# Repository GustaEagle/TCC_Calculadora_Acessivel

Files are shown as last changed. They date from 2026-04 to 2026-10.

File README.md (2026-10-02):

# Calculadora científica acessível (TCC)

Calculadora científica com foco em **acessibilidade** (feedback por voz e operação sem depender só da tela), executada em **Raspberry Pi 4B** com teclado físico, **UPS HAT**, painel **LCD 4,3" Waveshare** e suporte a **monitor HDMI**.

**Equipe:** Gustavo, João, Yuri  

**Repositório:** [github.com/GustaEagle/TCC_Calculadora_Acessivel](https://github.com/GustaEagle/TCC_Calculadora_Acessivel)

---

## Documentação principal

A pasta [`docs/`](docs/README.md) está organizada **por contexto** — comece pelo índice, ou vá direto ao documento:

| Documento | Descrição |
| --- | --- |
| [docs/README.md](docs/README.md) | **Índice da documentação** — o que existe e em que pasta |
| [docs/produto/PRD.md](docs/produto/PRD.md) | Requisitos de produto, escopo e arquitetura em alto nível (**normativo**) |
| [docs/guias/teclado-matriz.md](docs/guias/teclado-matriz.md) | **Teclado físico (matriz 6×7)**: as 38 teclas, funções com Ctrl/Shift, GPIO e diagnóstico |
| [docs/guias/comandos-teclado.md](docs/guias/comandos-teclado.md) | Comandos no teclado de PC: Ctrl/Shift, histórico, última resposta |
| [docs/guias/build-img-linux.md](docs/guias/build-img-linux.md) | Arranque em modo kiosk no Raspberry Pi 4B |
| [docs/desenvolvimento/Sprints.md](docs/desenvolvimento/Sprints.md) | Backlog por sprint e estado das tasks |
| [docs/desenvolvimento/GITHUB_WORKFLOW.md](docs/desenvolvimento/GITHUB_WORKFLOW.md) | Fluxo Git/GitHub da equipe |
| [docs/desenvolvimento/REPO_STRUCTURE.md](docs/desenvolvimento/REPO_STRUCTURE.md) | Mapa de pastas (software, hardware, system) |
| [docs/desenvolvimento/CONTEXT.md](docs/desenvolvimento/CONTEXT.md) | Memória curta entre sessões |
| [cronograma/cronograma.md](cronograma/cronograma.md) | Linha do tempo académica |

---

## Executar

```bash
python -m pip install -r software/requirements.txt
python software/app.py
```

`software/app.py` deteta a saída de vídeo ativa e abre **um** front (PRD §7): monitor HDMI externo quando reconhecido, senão o LCD 4,3", e **modo somente áudio** quando não há vídeo utilizável.

Para desenvolvimento e demonstrações a saída pode ser forçada:

```bash
python software/app.py --force-mode hdmi   # front do monitor externo
python software/app.py --force-mode lcd    # front do painel 4,3"
python software/app.py --force-mode audio  # somente voz, sem janela
```

**Histórico:** abre por **Ctrl + Ans** (no PC, a tecla `a` faz o papel do `Ans` da matriz 6x7). Não há botão de histórico — a entrada é sempre pelo teclado.

Lista completa dos atalhos: [docs/guias/teclado-matriz.md](docs/guias/teclado-matriz.md) (teclado do produto) e [docs/guias/comandos-teclado.md](docs/guias/comandos-teclado.md) (teclado de PC).

Testes: `make check` (ou `python -m unittest discover -s software/tests -t .`).

---

## Estrutura do repositório (resumo)

- **`software/`** — Motor de cálculo, UI (LCD / HDMI / partilhada), acessibilidade (áudio/TTS), plataforma (GPIO, integração), ponto de entrada `app.py`
- **`hardware/`** — PCB (KiCad), snapshots de export para marcos
- **`system/`** — Imagem SO, arranque e scripts (evolução conforme o PRD)
- **`docs/`** — Documentação por contexto: `produto/` (PRD), `guias/` (uso e montagem), `desenvolvimento/` (processo), `testes/`, mais referência de hardware (`raspberry-pi-4b/`, `waveshare/`, `keyboard-layout/`, `cad/`)
- **`cronograma/`** — Cronograma em Markdown, HTML interativo e export bruto
- **`prompts/`** — Prompts de sessão (bootstrap, fecho, agentes)

---

## Contribuir

1. Clonar o repositório e entrar na pasta do projeto  
2. Ler [docs/desenvolvimento/GITHUB_WORKFLOW.md](docs/desenvolvimento/GITHUB_WORKFLOW.md) e, no início de cada sessão, seguir [prompts/bootstrap.txt](prompts/bootstrap.txt)  
3. Trabalhar em branch a partir de `main` atualizada; mensagens de commit em **inglês** (ver [.github/COMMIT_GUIDELINES.md](.github/COMMIT_GUIDELINES.md))

---

## Estado do projeto

O código de aplicação ainda está em estruturação; o PRD e a documentação de apoio são a referência normativa. Consulte [docs/desenvolvimento/Sprints.md](docs/desenvolvimento/Sprints.md) para a sprint corrente e próximos entregáveis.

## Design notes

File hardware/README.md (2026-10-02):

# Hardware

## PCI (KiCad)

- **Canónico (recomendado):** [`pcb/`](pcb/) — um projeto KiCad por linha (ficheiros `.kicad_pro`, `.kicad_sch`, `.kicad_pcb`, bibliotecas locais em subpasta se necessário).
- **Legado / atual:** pasta **`Placa Kicad/`** na raiz do repositório — trabalho em curso; o histórico interno do KiCad (`.history/`) fica **fora do Git** (ver `.gitignore`).

Para marcos de revisão ou fabrico, use **`pcb/snapshots/<data>-<rótulo>/`** com Gerbers, PDF do esquemático, etc., em vez de versionar centenas de ficheiros de backup.

## Outros

- Layout de teclado (KLE): [`docs/keyboard-layout/`](../docs/keyboard-layout/).
- CAD mecânico: [`docs/cad/`](../docs/cad/).

Mapa geral: [docs/desenvolvimento/REPO_STRUCTURE.md](../docs/desenvolvimento/REPO_STRUCTURE.md).

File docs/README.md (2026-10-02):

# Documentação do projeto (`docs/`)

Índice da documentação do TCC — **calculadora científica acessível** em Raspberry Pi 4B.

A pasta está organizada **por contexto**: cada subpasta responde a uma pergunta diferente. Procure primeiro pela pergunta, depois pelo ficheiro.

| Pasta | Responde a | Conteúdo |
| ----- | --- | --- |
| [produto/](produto/) | *O que o produto deve fazer?* | PRD (referência normativa) e materiais/métodos do TCC |
| [guias/](guias/) | *Como se usa e como se faz rodar?* | Teclado da matriz, teclado de PC, imagem de arranque (kiosk) no Pi |
| [desenvolvimento/](desenvolvimento/) | *Como a equipe trabalha?* | Fluxo Git, mapa do repositório, backlog, memória de sessão, registo semanal |
| [testes/](testes/) | *O que já foi validado?* | Relatórios de testes e roteiro de usabilidade |
| [raspberry-pi-4b/](raspberry-pi-4b/) | *Como é a placa?* | Pinout do header J8 (40 pinos), datasheet, diagrama |
| [waveshare/](waveshare/) | *Como são os periféricos?* | LCD 4,3" HDMI (B) e UPS HAT |
| [keyboard-layout/](keyboard-layout/) | *Como é o teclado?* | Layout da matriz 6×7 no formato KLE |
| [cad/](cad/) | *Como as peças se encaixam?* | Modelos 3D (STEP/SLDPRT) do Pi, LCD e UPS HAT |

---

## Por onde começar

- **Chegou agora ao projeto:** [produto/PRD.md](produto/PRD.md) §1 (resumo) → [desenvolvimento/REPO_STRUCTURE.md](desenvolvimento/REPO_STRUCTURE.md) → [desenvolvimento/GITHUB_WORKFLOW.md](desenvolvimento/GITHUB_WORKFLOW.md).
- **Vai programar nesta sessão:** [desenvolvimento/CONTEXT.md](desenvolvimento/CONTEXT.md) (onde a última sessão parou) → [desenvolvimento/Sprints.md](desenvolvimento/Sprints.md) (task em aberto).
- **Vai mexer no hardware:** [raspberry-pi-4b/pinout.md](raspberry-pi-4b/pinout.md) §6 (matriz do teclado) → [keyboard-layout/README.md](keyboard-layout/README.md).
- **Vai montar o aparelho:** [guias/build-img-linux.md](guias/build-img-linux.md) → [waveshare/README.md](waveshare/README.md).

---

## Documentos mais consultados

| Documento | Para quê |
| --- | --- |
| [produto/PRD.md](produto/PRD.md) | Requisitos, escopo e arquitetura — **normativo**; desvios exigem atualizar o PRD |
| [guias/teclado-matriz.md](guias/teclado-matriz.md) | **Teclado físico do produto**: as 38 teclas da matriz 6×7 e o que cada uma faz |
| [guias/comandos-teclado.md](guias/comandos-teclado.md) | Os mesmos comandos no teclado de PC (desenvolvimento e testes) |
| [raspberry-pi-4b/pinout.md](raspberry-pi-4b/pinout.md) | Pinagem J8 e atribuição de GPIO da matriz (contrato com o código) |
| [desenvolvimento/GITHUB_WORKFLOW.md](desenvolvimento/GITHUB_WORKFLOW.md) | Branches, PRs e sequência de comandos da equipe |
| [desenvolvimento/sessoes/](desenvolvimento/sessoes/README.md) | O que cada pessoa fez, por semana do plano |

---

## Fora de `docs/`

| Caminho | Conteúdo |
| --- | --- |
| [`../README.md`](../README.md) | Visão geral do repositório e como executar |
| [`../cronograma/`](../cronograma/) | Linha do tempo académica (Markdown + HTML interativo) |
| [`../prompts/`](../prompts/) | Prompts de sessão (bootstrap, fecho, agentes) |
| [`../openspec/`](../openspec/) | Propostas de mudança e specs vigentes |
| [`../.github/COMMIT_GUIDELINES.md`](../.github/COMMIT_GUIDELINES.md) | Convenção de mensagens de commit |

---

## Convenções desta pasta

- **Um contexto por pasta.** Documento novo entra na pasta que responde à mesma pergunta; se não houver, discuta antes de criar pasta nova.
- **Links relativos**, sempre — o repositório é lido tanto no GitHub como offline no clone.
- **Ficheiros binários** (datasheet, CAD, imagens) ficam junto do documento que os explica, não numa pasta genérica de anexos.

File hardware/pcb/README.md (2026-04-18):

# PCB — KiCad

Coloque aqui o **projeto principal** (ex.: `tcc-calculadora/` com `.kicad_pro`).

## Snapshots (marcos)

Exportações conscientes (não substituem o Git do projeto):

```
snapshots/
  2026-05-01-pre-banca/
  2026-06-10-entrega/
```

Cada pasta pode conter: Gerber ZIP, PDF do esquemático, lista de materiais, notas de revisão.

## O que não versionar

A pasta **`.history/`** gerada pelo KiCad fica fora do Git (ver `.gitignore` na raiz).

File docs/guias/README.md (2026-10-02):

# Guias — operação e montagem

Como **usar** a calculadora e como **fazer o aparelho rodar**. Documentos de procedimento: seguem passo a passo, do começo ao fim.

| Documento | Para quem | Conteúdo |
| --- | --- | --- |
| [teclado-matriz.md](teclado-matriz.md) | Quem usa o produto | **Teclado físico (matriz 6×7)**: catálogo das 38 teclas com posição `C#L#`/`SW#`, layout da grade, funções com `Ctrl`/`Shift`, leitura por GPIO e diagnóstico |
| [comandos-teclado.md](comandos-teclado.md) | Quem desenvolve e testa | **Teclado de PC**: modificadores fixos, histórico, última resposta, graus/radianos, apagar telas, modo somente áudio |
| [build-img-linux.md](build-img-linux.md) | Quem monta o aparelho | Arranque em modo **kiosk** no Raspberry Pi 4B: Pi OS Lite, Alpine ou Buildroot; prós, contras e passos de cada opção |

## Relacionado

- Qual tecla está em qual GPIO: [../raspberry-pi-4b/pinout.md §6](../raspberry-pi-4b/pinout.md)
- Legendas e geometria do teclado: [../keyboard-layout/README.md](../keyboard-layout/README.md)
- `config.txt` e cablagem dos periféricos: [../waveshare/README.md](../waveshare/README.md)

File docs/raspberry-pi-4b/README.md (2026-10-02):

# Raspberry Pi 4 Model B — GPIO (header de 40 pinos)

**Especificação completa do pinout (tabelas, interfaces, notas elétricas):** [pinout.md](pinout.md)

**Diagrama visual:** ficheiro `Pinout.png` (referenciado em [pinout.md](pinout.md)).

**Datasheet oficial (PDF nesta pasta):** [RP-008341-DS-1-raspberry-pi-4-datasheet.pdf](RP-008341-DS-1-raspberry-pi-4-datasheet.pdf)

**Modelo 3D da placa:** [`../cad/raspberry-pi-4-model-b/`](../cad/raspberry-pi-4-model-b/)

**Pinout interativo:** [pinout.xyz](https://pinout.xyz/) · [Documentação Raspberry Pi](https://www.raspberrypi.com/documentation/)

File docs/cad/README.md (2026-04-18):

# Modelos CAD (3D)

Ficheiros **STEP/STP** e **SLDPRT** de referência mecânica para integração da caixa, PCB e periféricos.

| Pasta | Origem / conteúdo |
| ----- | --- |
| [waveshare-4.3inch-hdmi-lcd-b/](waveshare-4.3inch-hdmi-lcd-b/) | Waveshare — LCD **4,3" HDMI (B)** (desenho 3D; alinhar com [wiki](https://www.waveshare.com/wiki/4.3inch_HDMI_LCD_(B))) |
| [waveshare-ups-hat/](waveshare-ups-hat/) | Waveshare — **UPS HAT** (STEP; alinhar com [wiki](https://www.waveshare.com/wiki/UPS_HAT)) |
| [raspberry-pi-4-model-b/](raspberry-pi-4-model-b/) | **Raspberry Pi 4 Model B** — geometria da placa (STEP + SLDPRT conforme ficheiros presentes); pinagem em [../raspberry-pi-4b/README.md](../raspberry-pi-4b/README.md) |

**Nota:** nomes de ficheiros longos ou com espaços podem existir nos exports originais; renomeie no explorador apenas se atualizar referências em desenhos ou scripts.

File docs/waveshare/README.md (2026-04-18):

# Documentação Waveshare (contexto do projeto)

Este diretório contém **notas em português** derivadas das páginas oficiais da Waveshare, para consulta rápida no repositório do TCC. **A fonte normativa continua sendo a wiki e os ficheiros publicados pela Waveshare.**

## Links oficiais (canónicos)

- [UPS HAT — Waveshare Wiki](https://www.waveshare.com/wiki/UPS_HAT)
- [4.3inch HDMI LCD (B) — Waveshare Wiki](https://www.waveshare.com/wiki/4.3inch_HDMI_LCD_(B))
- [UPS HAT — página do produto](https://www.waveshare.com/UPS-HAT.htm)
- [4.3inch HDMI LCD (B) — página do produto](https://www.waveshare.com/4.3inch-hdmi-lcd-b.htm)

## Espelhos locais (Markdown)

| Ficheiro | Tema |
| --- | ---- |
| [UPS_HAT.md](UPS_HAT.md) | UPS HAT, I2C, carregamento, segurança, FAQ |
| [4.3inch_HDMI_LCD_B.md](4.3inch_HDMI_LCD_B.md) | LCD 800×480, `config.txt`, toque, FAQ |

## Modelos 3D no repositório

Ficheiros STEP/STP para alinhamento mecânico estão em [`../cad/`](../cad/README.md):

- [LCD 4,3" HDMI (B)](../cad/waveshare-4.3inch-hdmi-lcd-b/)
- [UPS HAT](../cad/waveshare-ups-hat/)
- [Raspberry Pi 4 Model B](../cad/raspberry-pi-4-model-b/) (placa de referência)

## Snapshot textual

- **Data da captura / redação local:** 2026-04-17  
- **Nota:** diagramas, fotos e PDFs da wiki **não** estão reproduzidos aqui; quando precisar de ilustrações ou datasheets, use os links da wiki e a secção “Resources / Document” de cada página.

## Aviso de uso

O conteúdo descritivo pertence à **Waveshare**. Os ficheiros `.md` desta pasta são um **auxiliar de trabalho**; em trabalhos académicos cite a documentação oficial e as datas de consulta conforme as normas da sua instituição.

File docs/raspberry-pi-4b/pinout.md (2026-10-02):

# Especificação do pinout — Raspberry Pi 4 Model B (header J8)

**Conector:** J8, **40 pinos** (2×20), passo **2,54 mm**.  
**Âmbito:** apenas pinagem e funções de **uso corrente** no header; não substitui o [datasheet oficial](RP-008341-DS-1-raspberry-pi-4-datasheet.pdf) para limites absolutos de corrente, derivações do SoC nem diagramas de bloco.

**Referências externas:** [pinout.xyz](https://pinout.xyz/) · [Documentação Raspberry Pi](https://www.raspberrypi.com/documentation/)

---

## 1. Convenções

| Termo | Significado |
| ----- | --- |
| **Pin** | Número **físico** no conector, **1…40** (estampado na silkbscreen da PCB como “1” junto ao canto da placa). |
| **BCM** | Numeração **Broadcom** do GPIO (uso típico em `gpiozero`, `RPi.GPIO`, `libgpiod`, overlays). |
| **Nome** | Rótulo habitual no **modo GPIO**; entre parêntesis, **função alternativa** mais citada para periféricos. |

**Orientação física:** com a placa vista de cima e os **conectores USB/Ethernet para baixo**, a coluna ímpar (**1, 3, …, 39**) fica em geral **perto da borda** da board; o **pino 1** é o canto que leva **3,3 V** (quadrado na PCB em muitos desenhos). Confirme sempre o **“1”** na sua unidade.

---

## 2. Requisitos elétricos (resumo)

- Todos os pinos marcados como **GPIO** operam a **3,3 V** lógicos. **Não** aplicar **5 V** a entradas GPIO — **não** são tolerantes a 5 V.
- Pinos **3V3** (1, 17): alimentação **3,3 V** limitada (capacidade total partilhada; ver datasheet).
- Pinos **5V** (2, 4): **5 V** (ligados ao rail de alimentação; origem depende do modo de alimentação da placa).
- **GND** (6, 9, 14, 20, 25, 30, 34, 39): referência comum.
- Corrente máxima **por GPIO** e **soma** de I/O: ver **datasheet** e notas de hardware; não assumir carga forte sem transistor/driver.

---

## 3. Tabela de pinos J8 (especificação)

| Pin | Sinal / função principal | BCM | Tipo |
| --- | --- | --- | ---- |
| 1 | 3V3 | — | Alimentação |
| 2 | 5V | — | Alimentação |
| 3 | GPIO2 — **I2C1 SDA** | 2 | GPIO / I2C |
| 4 | 5V | — | Alimentação |
| 5 | GPIO3 — **I2C1 SCL** | 3 | GPIO / I2C |
| 6 | GND | — | Terra |
| 7 | GPIO4 | 4 | GPIO |
| 8 | GPIO14 — **UART0 TXD** | 14 | GPIO / UART |
| 9 | GND | — | Terra |
| 10 | GPIO15 — **UART0 RXD** | 15 | GPIO / UART |
| 11 | GPIO17 — **SPI1 CE1** (ALT) | 17 | GPIO / SPI |
| 12 | GPIO18 — **SPI1 SCLK** (ALT) / **PWM0** / PCM_CLK | 18 | GPIO / SPI / PWM / PCM |
| 13 | GPIO27 | 27 | GPIO |
| 14 | GND | — | Terra |
| 15 | GPIO22 | 22 | GPIO |
| 16 | GPIO23 | 23 | GPIO |
| 17 | 3V3 | — | Alimentação |
| 18 | GPIO24 | 24 | GPIO |
| 19 | GPIO10 — **SPI0 MOSI** | 10 | GPIO / SPI |
| 20 | GND | — | Terra |
| 21 | GPIO9 — **SPI0 MISO** | 9 | GPIO / SPI |
| 22 | GPIO25 | 25 | GPIO |
| 23 | GPIO11 — **SPI0 SCLK** | 11 | GPIO / SPI |
| 24 | GPIO8 — **SPI0 CE0** | 8 | GPIO / SPI |
| 25 | GND | — | Terra |
| 26 | GPIO7 — **SPI0 CE1** | 7 | GPIO / SPI |
| 27 | GPIO0 — **ID_SD** (EEPROM HAT, I2C) | 0 | Reservado HAT / GPIO |
| 28 | GPIO1 — **ID_SC** (EEPROM HAT, I2C) | 1 | Reservado HAT / GPIO |
| 29 | GPIO5 | 5 | GPIO |
| 30 | GND | — | Terra |
| 31 | GPIO6 | 6 | GPIO |
| 32 | GPIO12 — **PWM0** | 12 | GPIO / PWM |
| 33 | GPIO13 — **PWM1** | 13 | GPIO / PWM |
| 34 | GND | — | Terra |
| 35 | GPIO19 — **SPI1 MISO** (ALT) / PCM_FS | 19 | GPIO / SPI / PCM |
| 36 | GPIO16 — **SPI1 CE0** (ALT) | 16 | GPIO / SPI |
| 37 | GPIO26 | 26 | GPIO |
| 38 | GPIO20 — **SPI1 MOSI** (ALT) / PCM_DIN | 20 | GPIO / SPI / PCM |
| 39 | GND | — | Terra |
| 40 | GPIO21 — PCM_DOUT (ALT) | 21 | GPIO / PCM |

**Nota:** **SPI1** só está disponível após ativar o controlador com **Device Tree overlay** (ex.: `spi1-1cs`, `spi1-2cs`, `spi1-3cs` em `config.txt`). Os pinos **MOSI / MISO / SCLK** acima são o mapeamento habitual no header; linhas **CE** (**chip enable** = **chip select**, **CS**) podem ser **reatribuídas** por parâmetros do overlay — ver README em `/boot/firmware/overlays/README` na imagem do SO.

---

## 3.1 SPI0 — sinais no J8 (bus principal)

Controlador **SPI0** (nós típicos `/dev/spidev0.0`, `/dev/spidev0.1`). **CE** = *chip enable* (sinônimo usual de **CS**, *chip select* / **SS**, *slave select*).

| Sinal | Função | BCM | Pin físico |
| ----- | --- | --- | --- |
| **MOSI** | Master Out, Slave In | 10 | 19 |
| **MISO** | Master In, Slave Out | 9 | 21 |
| **SCLK** | *Serial clock* (relógio SPI) | 11 | 23 |
| **CE0** | Chip select 0 | 8 | 24 |
| **CE1** | Chip select 1 | 7 | 26 |

O SPI0 expõe **duas** linhas de chip select (**CE0**, **CE1**). Não há **CE2** no SPI0 neste header.

---

## 3.2 SPI1 — sinais habituais no J8 (bus auxiliar)

Controlador **SPI1** (ex.: `/dev/spidev1.x` quando ativo). Mapeamento **frequente** no conector (compatível com referências como [pinout.xyz — SPI](https://pinout.xyz/pinout/spi)); **confirmar** na sua imagem se usou overlay com `cs*_pin` personalizado.

| Sinal | BCM | Pin físico |
| ----- | --- | --- |
| **MOSI** | 20 | 38 |
| **MISO** | 19 | 35 |
| **SCLK** | 18 | 12 |
| **CE0** | 16 | 36 |
| **CE1** | 17 | 11 |

**CE2 (terceiro chip select):** o overlay **`spi1-3cs`** permite três linhas **CS**; os **números de GPIO** para **CS0 / CS1 / CS2** são **configuráveis** (parâmetros `cs0_pin`, `cs1_pin`, `cs2_pin` no README oficial dos overlays). O valor **padrão** do firmware pode **colidir** com o uso “didático” CE0 = pin 36 se não ler o overlay — **sempre** validar com a documentação da sua versão (`dtoverlay -h spi1-3cs` ou arquivo `README` dos overlays). O **GPIO21** (pin **40**) **não** faz parte deste mapa SPI1 habitual; mantém-se principalmente como **PCM** / GPIO.

---

## 4. Interfaces no header (mapa rápido)

| Interface | Pinos físicos | BCM |
| --- | --- | --- |
| **I2C1** (uso geral, ex.: sensores, muitos HAT) | 3 (SDA), 5 (SCL) | 2, 3 |
| **UART0** | 8 (TX), 10 (RX) | 14, 15 |
| **SPI0** | 19 (**MOSI**), 21 (**MISO**), 23 (**SCLK**), 24 (**CE0**), 26 (**CE1**) | 10, 9, 11, 8, 7 |
| **SPI1** (com overlay) | 38 (**MOSI**), 35 (**MISO**), 12 (**SCLK**), 36 (**CE0**), 11 (**CE1**); **CE2** só com `spi1-3cs` e pinos conforme overlay | 20, 19, 18, 16, 17 |
| **EEPROM HAT** (I2C dedicado) | 27 (ID_SD), 28 (ID_SC) | 0, 1 |

No **Raspberry Pi 4** existem **UARTs adicionais** noutros pinos via configuração; não estão todas listadas nesta especificação resumida.

---

## 5. EEPROM de HAT (pinos 27 e 28)

Os pinos **27** e **28** estão ligados ao bus de **identificação de HAT** (EEPROM). Com **UPS HAT**, **Sense HAT** ou outras placas empilhadas que usem esse bus, **não** atribua estes pinos a **matriz de teclado** ou GPIO geral **sem** analisar **conflito elétrico e lógico** com a pilha de placas.

---

## 6. Matriz do teclado 6×7 — atribuição de GPIO

Teclado **Cherry MX hotswap** ligado **direto ao GPIO** por cabo flat, **sem** microcontrolador (PRD §6). O esquemático KiCad (`hardware/pcb/`) nomeia apenas as nets **`Row0…Row5`** e **`Col0…Col6`**; a correspondência com os pinos do J8 é a tabela abaixo.

**Fonte única de verdade em código:** [`software/hw_platform/keypad_pinout.py`](../../software/hw_platform/keypad_pinout.py) — o módulo valida na importação que cada GPIO existe no J8, que BCM e pino físico batem com a tabela do §3 e que nenhuma linha está repetida. [`software/tests/test_keypad_pinout.py`](../../software/tests/test_keypad_pinout.py) trava estes valores no CI.

> **Numeração:** tudo é **0-based** e o rótulo do chicote **é** a net do esquemático: **L0 = Row0**, **C0 = Col0**. Uma posição da grade escreve-se **`C#L#`** (coluna, linha), e os switches são **`SW0…SW37`** — os mesmos componentes são `SW1…SW38` na PCB do KiCad (**SWn aqui = SW(n+1) lá**).

**Polaridade confirmada no hardware** (o anodo de cada díodo 1N4148 fica do lado do switch/coluna, o catodo na net `RowN`):

| Condutor | Configuração |
| --- | --- |
| Linhas `L0…L5` | entrada com **pull-down** |
| Coluna ativa (uma de cada vez) | saída em **HIGH**, sem bias |
| Colunas inativas | entrada **sem bias** (alta impedância) |

Uma linha lida em **HIGH** com a coluna `Cn` ativa significa switch fechado em `CnLm`. **Nunca** duas colunas em saída ao mesmo tempo, **nunca** uma linha em saída. O scanner está em [`software/hw_platform/keypad_matrix.py`](../../software/hw_platform/keypad_matrix.py) (libgpiod v2, `gpiochip0`, offset = BCM).

### 6.1 Colunas

| Rótulo | Net (KiCad) | Cor do fio | BCM | Pin | Função alternativa do pino |
| --- | --- | --- | --- | --- | --- |
| **C0** | Col0 | Laranja | 26 | 37 | — |
| **C1** | Col1 | Roxo | 19 | 35 | SPI1 MISO (ALT) |
| **C2** | Col2 | Azul | 13 | 33 | PWM1 |
| **C3** | Col3 | Preto com final azul | 21 | 40 | PCM_DOUT (ALT) |
| **C4** | Col4 | Vermelho | 20 | 38 | SPI1 MOSI (ALT) |
| **C5** | Col5 | Marrom | 15 | 10 | **UART0 RXD** |
| **C6** | Col6 | Laranja | 14 | 8 | **UART0 TXD** |

### 6.2 Linhas

| Rótulo | Net (KiCad) | Cor do fio | BCM | Pin | Função alternativa do pino |
| --- | --- | --- | --- | --- | --- |
| **L0** | Row0 | Verde | 10 | 19 | **SPI0 MOSI** |
| **L1** | Row1 | Branco | 9 | 21 | **SPI0 MISO** |
| **L2** | Row2 | Roxo | 11 | 23 | **SPI0 SCLK** |
| **L3** | Row3 | Roxo | 17 | 11 | SPI1 CE1 (ALT, só com overlay) |
| **L4** | Row4 | Amarelo | 27 | 13 | — |
| **L5** | Row5 | Verde | 22 | 15 | — |

13 condutores no total (6 linhas + 7 colunas), sem repetição de GPIO nem de pino físico. **Atenção:** GPIO27 é o **pino físico 13**; o pino físico 27 (EEPROM de HAT, §5) **não** é usado pela matriz.

> Uma versão anterior desta tabela tinha **Row0↔Row2** e **Row3↔Row5** trocadas — os mesmos seis GPIOs em outra ordem. A ordem acima foi conferida eletricamente, tecla a tecla.

### 6.3 Conflitos de função — o que tem de ficar desligado no boot

Seis das treze linhas ocupam pinos com periférico associado. Elas só se comportam como **GPIO comum** enquanto o firmware **não** ativar esse periférico — ver [`system/rpi-os/alpine/overlay/boot/usercfg.txt`](../../system/rpi-os/alpine/overlay/boot/usercfg.txt):

| Periférico | Pinos da matriz | Condição para a matriz funcionar |
| --- | --- | --- |
| **UART0** | C6 (GPIO14), C5 (GPIO15) | `enable_uart=0` e **sem** `console=serial0` no `cmdline.txt` (a imagem usa `console=tty1`). **Custo:** sem consola série para depurar o boot; resta o HDMI/tty1. |
| **SPI0** | L2 (GPIO11), L1 (GPIO9), L0 (GPIO10) | **não** ligar `dtparam=spi=on`. O LCD Waveshare é HDMI, não SPI — nada no produto quer o SPI0. |
| **SPI1** (ALT) | L3 (GPIO17 = CE1) | **não** carregar overlay `spi1-*cs`. Sem overlay, SPI1 nem existe — conflito apenas teórico. |

**I2C1 (GPIO2/GPIO3, pinos 3 e 5) fica FORA da matriz de propósito.** É o barramento onde o UPS HAT lê tensão/corrente/capacidade no endereço **0x42** ([UPS_HAT.md](../waveshare/UPS_HAT.md), RF-06/RF-14): mantendo-o livre, a leitura de bateria usa o I2C **de hardware** (`dtparam=i2c_arm=on`, `/dev/i2c-1`), sem overlay `i2c-gpio` nem código fora do padrão da Waveshare.

> **Porque L3…L5 saíram de GPIO4/3/2 (pinos 7/5/3).** Além do UPS, **GPIO2 e GPIO3 são os únicos pinos do header com pull-ups de 1,8 kΩ para 3,3 V soldados na placa do Pi** — existem sempre, mesmo com o I2C desligado, e nenhuma configuração os remove. Numa linha de matriz lida com pull-down, esses pull-ups a manteriam sempre em HIGH (tecla sempre premida); como I2C, são exatamente os pull-ups que o barramento quer. Os pinos **11/13/15** (GPIO17/27/22) não têm periférico ativo nenhum e continuam a ser três **ímpares contíguos**, ou seja, o flat mantém a geometria.

> **O UPS HAT não é empilhável neste projeto.** O header dele é de 40 pinos **sem passagem** e o header do Pi está ocupado pelo flat do teclado, portanto a HAT liga-se **por fios** (5 V, GND, SDA no pino 3, SCL no pino 5) — ou alimenta o Pi pela saída USB 5 V dela. Confirmar no esquemático do lote antes de soldar.

Os pinos **27/28** (GPIO0/GPIO1, EEPROM de HAT — §5) **não** são usados pela matriz e não entram na lista de livres.

### 6.4 GPIO livres depois desta atribuição

**BCM:** 4, 5, 6, 7, 8, 12, 16, 18, 23, 24, 25 · **Pinos:** 7, 29, 31, 26, 24, 32, 36, 12, 16, 18, 22.

GPIO2/GPIO3 (pinos 3/5) **não** entram aqui: estão reservados ao I2C1 do UPS HAT (§6.3).

### 6.5 Mapa de switches e bring-up

Grade vista de frente, colunas `C0…C6` da esquerda para a direita. Cada célula: switch e keycap. As quatro posições **—** não têm switch (`C2L1`, `C2L2`, `C2L3`, `C4L4`); sinal nelas é defeito e o scanner só o regista no log.

| | C0 | C1 | C2 | C3 | C4 | C5 | C6 |
| - | -- | -- | -- | -- | -- | -- | -- |
| **L0** | SW0 `Pol` | SW1 `x!` | SW2 `Pi` | SW3 `(` | SW4 `)` | SW5 `%` | SW6 `e` |
| **L1** | SW7 `sen` | SW8 `cos` | — | SW9 `7` | SW10 `8` | SW11 `9` | SW12 `/` |
| **L2** | SW13 `tan` | SW14 `log` | — | SW15 `4` | SW16 `5` | SW17 `6` | SW18 `*` |
| **L3** | SW19 `x^-1` | SW20 `^` | — | SW21 `1` | SW22 `2` | SW23 `3` | SW24 `-` |
| **L4** | SW25 `?` | SW26 `nCr` | SW27 `√` | SW28 `0` | — | SW29 `,` | SW30 `+` |
| **L5** | SW31 `Ctrl` | SW32 `exp` | SW33 `Shift` | SW34 `Ans` | SW35 `=` | SW36 `AC` | SW37 `Del` |

A tecla **`?`** existe na placa mas **não tem função** no software: ela é lida e anuncia «Tecla sem função».

**Tempos (valores de bancada, PRD §12):** estabilização de **~1 ms** depois de ativar cada coluna, **debounce de ~20 ms**. Ambos são configuráveis no scanner e na ferramenta de bring-up; rever com o chicote definitivo.

**Checklist de bancada** (manual, no Pi; não corre no CI):

- `python3 software/tools/keypad_bringup.py` — premir as 38 teclas: cada uma aparece com `SW#`, `C#L#`, keycap e GPIOs, a grade final mostra 38 de 38, e nenhuma posição vazia aparece.
- Depois do `Ctrl+C`: `pinctrl get 9-11,13-15,17,19-22,26-27` mostra as 13 GPIOs em entrada sem pull (`ip pn`).
- O mesmo `pinctrl get` depois de `kill -TERM` no app (`python3 -m software.app`).
- Com o app aberto, `Ctrl` e depois `sen` na matriz insere o arco seno — nos dois fronts (LCD e monitor).

---

## 7. Diagrama visual

A imagem `Pinout.png` serve como **referência gráfica**. Pode corresponder a outro modelo no silkscreen (ex.: Pi 3 B+); a **numeração 1…40** e as **funções da tabela acima** aplicam-se ao **Pi 4 Model B** neste projeto.

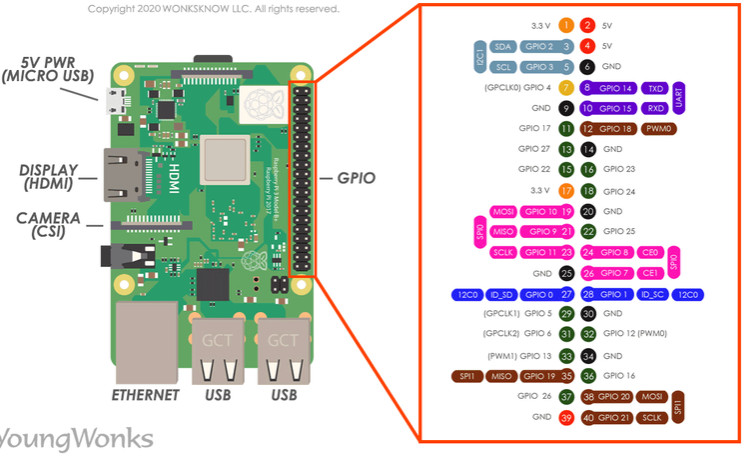
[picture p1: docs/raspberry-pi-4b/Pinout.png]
Pinout GPIO — header de 40 pinos (referência visual)


---

## 8. Artefactos relacionados no repositório

- [README.md](README.md) — índice da pasta (datasheet, CAD, links).
- Modelo 3D: [`../cad/raspberry-pi-4-model-b/`](../cad/raspberry-pi-4-model-b/)

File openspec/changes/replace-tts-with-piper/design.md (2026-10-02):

## Context

A motivação está no `proposal.md` (seção Why) e os requisitos em `specs/speech-engine/spec.md`.

O que já existe e condiciona a abordagem:

- **`software/accessibility/speech.py`** é o **único** lugar que conhece o motor de voz. Ele expõe `SpeechService.say()`, `interrupt_and_say()` e `stop()`, e por baixo tem: uma `queue.Queue`, uma thread worker, o contador `_Generation` (descarta anúncios obsoletos após uma interrupção) e um **processo por frase** (`_SpeakProcess`, subclasse de `multiprocessing.Process`). O processo importa `pyttsx3`, inicializa o motor, escolhe a voz pt-BR, sintetiza para um WAV temporário e toca com `os.system("aplay ...")`. O `_SpeakProcess` lidera um grupo de processo próprio para que `terminate()` mate também o `aplay` neto, e usa um diretório de scratch por frase, apagado no `join()`.
- **Os 5 consumidores** (`app.py`, `ui/lcd/app.py`, `ui/hdmi/app.py`, `audio_only.py`, `ui/shared/video_watch.py`) só chamam `say`/`interrupt_and_say`/`stop`. A mudança fica contida no `speech.py`.
- **`process_factory` / `SpeakProcess` (Protocol)** já são o ponto de injeção: o construtor aceita uma fábrica de "processo de fala" duck-typed (`start`/`join`/`is_alive`/`terminate`). Os testes já usam um `_FakeProcess`. É por aqui que o motor residente entra sem reescrever a fila.
- **Saída de áudio (decidida):** `overlay/etc/asound.conf` fixa a placa `Headphones` (jack 3,5 mm do Pi) **pelo nome**, e o PCM padrão do ALSA na imagem é `plug → hw`, **sem `dmix`**. Só um processo abre a placa por vez. O `espeak-ng` já gera 22.050 Hz / mono / 16-bit, e a voz `cadu` também é 22.050 Hz — o formato que chega ao jack não muda.
- **Imagem:** Alpine 3.24.1 aarch64, Python **3.14.7**, `espeak-ng` 1.52, `alsa-utils` (aplay), só ALSA (sem PulseAudio). O `community` v3.24 tem `onnxruntime`/`py3-onnxruntime` **1.24.4** já compilados para musl e Python 3.14 (confirmado no APKINDEX em cache no rootfs de build). O multiprocessing no 3.14 usa **forkserver** por padrão (o dev/CI usam **fork**).
- **`piper-tts` (upstream `OHF-Voice/piper1-gpl`, versão 1.8.0, GPL-3.0):**
  - depende de `onnxruntime>=1,<2` e `pathvalidate`;
  - **embute o próprio `espeak-ng`** (ligado estaticamente via CMake, tag fixa) e os `espeak-ng-data`, usados só como **fonemizador** — a voz é o modelo neural;
  - o **sdist do PyPI é incompleto** (falta `CMakeLists.txt`, `espeakbridge.c`, `espeak-ng-data`): `pip install piper-tts` compila a partir do **git**, não do sdist. Precisa de `build-base`, `cmake`, `git`, `python3-dev`, `scikit-build` — ~200 MB que **não** vão para a imagem final;
  - a extensão C é `abi3` (compatível entre versões de Python), mas o upstream só declara suporte até 3.13 — o 3.14 precisa ser validado;
  - a API Python é `PiperVoice.load(model, config)` + `voice.synthesize(text) -> Iterable[AudioChunk]`, com `AudioChunk.audio_int16_bytes` (PCM S16LE mono). `SessionOptions` permite limitar as threads do ONNX.
- **Armadilha:** o apk chamado **`piper`** no Alpine **não** é o Piper TTS — é um configurador de mouse (libratbag). Nunca `apk add piper`.
- **Voz `pt_BR-cadu-medium`** (repositório `rhasspy/piper-voices`): 22.050 Hz, 1 locutor, `phoneme_type: espeak`, `espeak.voice: pt-br`, dataset CC0, `.onnx` de 63 MB + `.onnx.json`. `inference`: `noise_scale 0.667`, `length_scale 1.0`, `noise_w 0.8`.
- **Frases fixas são um conjunto pequeno e conhecido:** `SPOKEN_TOKEN_NAMES` (38), os 10 dígitos, os 10 textos de `ERROR_MESSAGES` §13, os avisos 012/013 e os anúncios fixos ("Calculadora pronta", "Controle ativo"...). Dá para pré-sintetizar tudo em poucos MB.

## Goals / Non-Goals

**Goals:**
- Voz neural pt-BR (`cadu`) com o **mesmo contrato** de fila e interrupção de hoje (RF-08), sem tocar nos 5 consumidores.
- Motor **residente**: o modelo carrega uma vez, não por frase.
- Arranque não bloqueado pela carga do modelo (RNF-06): "Calculadora pronta" nunca espera o ONNX.
- Degradação segura: sem Piper, cai para `espeak-ng` e a entrada não trava (WRN-011).
- CI e `make check` continuam **sem** Piper nem áudio, por import tardio e motor injetável.

**Non-Goals:**
- Streaming intra-frase (o Piper devolve a frase inteira).
- Interromper uma síntese **em andamento** (a API do Piper não permite abortar; ver D5).
- Remover o `espeak-ng` do sistema (fonemizador + fallback).
- GPU/CUDA; treino de voz; download de voz em execução.

## Decisions

### D1 — O motor residente entra pela `process_factory`, a fila fica intacta

O `SpeechService` continua idêntico: `say`/`interrupt_and_say`/`stop`, `queue.Queue`, worker, `_Generation`, `process_lock`. O que muda é o objeto que a `process_factory` devolve por frase. Hoje é um `_SpeakProcess` (processo). Passa a ser um **handle de reprodução** leve que:

- fala com o **motor residente** já carregado (não recarrega nada);
- expõe a mesma interface duck-typed `SpeakProcess` (`start`, `join`, `is_alive`, `terminate`), para o worker não perceber diferença;
- em `start()`: sintetiza (ou pega do cache, D4) e dispara **um** `aplay`;
- em `terminate()`: mata o `aplay` (grupo de processo, como hoje);
- em `join()`: espera o `aplay` terminar.

*Alternativa rejeitada:* reescrever a fila para chamar o motor direto na thread worker. Perderia o ponto de teste (`process_factory`/`_FakeProcess`) e misturaria síntese com reprodução, dificultando o `terminate()`.

### D2 — Motor residente: `PiperEngine` carregado em segundo plano

Novo componente em `speech.py` (ou submódulo `accessibility/piper_engine.py`), com **import tardio** do `piper`/`onnxruntime`:

- `PiperEngine.load_async()` carrega `PiperVoice.load(model, config)` numa **thread**, para o construtor do `SpeechService` retornar de imediato (RNF-06).
- Enquanto o modelo não terminou de carregar, ou se a carga falhar, o serviço usa o **fallback** (D6). Assim "Calculadora pronta" sai na hora, pelo espeak-ng, mesmo que o ONNX ainda esteja subindo.
- `synthesize(text) -> bytes` concatena os `AudioChunk.audio_int16_bytes` das frases e devolve PCM S16LE mono.
- As threads do `onnxruntime` são limitadas (`SessionOptions.inter_op_num_threads`/`intra_op_num_threads`, ex.: 2–3), para não competir com o Tk e a varredura da matriz. O valor fica configurável.
- Um único `PiperEngine` por `SpeechService` (o serviço já é reusado entre fronts na troca do RF-09).

### D3 — Reprodução: `aplay` lendo raw pela entrada padrão

O player é `aplay -q -t raw -f S16_LE -c 1 -r <sample_rate> -`, recebendo o PCM pela stdin. Motivos:

- o `sample_rate` vem do `.onnx.json` da voz (cadu = 22.050), não é fixado no código;
- dispensa WAV temporário, `os.system` e processo neto — sai a fila de `fala-*`/`tmp*.wav` em `/tmp`;
- o `aplay` usa o PCM padrão do ALSA, que o `asound.conf` já manda para o jack;
- a interrupção continua sendo **matar o `aplay`**. O handle lidera o próprio grupo de processo (como o `_SpeakProcess` de hoje) e `terminate()` faz `killpg(SIGTERM)`.

Como o ALSA não tem `dmix` (Context), **só um `aplay` toca por vez**. A fila já serializa isso (uma frase por vez), e o fallback nunca toca junto com o Piper.

### D4 — Cache de frases fixas, pré-aquecido após o arranque

Um `dict[str, bytes]` (texto → PCM) guarda as frases de conjunto fechado:

- `SPOKEN_TOKEN_NAMES` (38), os dígitos `0..9`, os 10 `ERROR_MESSAGES` §13 com o prefixo falado ("Erro 001. ..."), os avisos 012/013 e os anúncios fixos.
- O pré-aquecimento roda numa thread de baixa prioridade **depois** que o modelo carrega, sem bloquear nada. Até estar pronto, um miss simplesmente sintetiza na hora.
- `say(text)`: se `text` está no cache, o handle só reproduz os bytes (latência ~ a de abrir o `aplay`); senão, sintetiza.
- Resultados e histórico (números, expressões) **não** entram no cache — são dinâmicos.
- **Mitigação de resultados longos:** "Resultado" e "Última resposta" podem sair do cache **imediatamente**, enquanto o número é sintetizado como frase seguinte. É a diferença entre o Piper e o espeak-ng em latência percebida.

*Estimativa:* todas as frases fixas somam poucos MB de PCM em RAM; aceitável no Pi 4 (Context da imagem).

### D5 — Interrupção: descarte por geração + morte do `aplay`; síntese em curso não é abortada

O `interrupt_and_say()` de hoje faz três coisas que **continuam**: `bump()` da geração, limpa a fila e `terminate()` no processo atual. Com o Piper:

- se a frase interrompida já está **tocando**, o `aplay` é morto na hora (igual a hoje);
- se está sendo **sintetizada**, a API do Piper **não** oferece abortar no meio. No pior caso a síntese da frase termina (~100–500 ms para frases curtas) e é **descartada** pelo `_Generation` antes de tocar — o worker checa `is_stale(generation)` e nem abre o `aplay`. O usuário não ouve a frase obsoleta; só espera, no pior caso, o fim de uma síntese curta.
- A síntese pode ser feita **frase a frase** (o Piper já separa por sentença) e a geração é checada **entre frases**, encurtando a janela para textos longos.

*Trade-off aceito:* não há corte no meio de uma síntese. Para as frases fixas (cache) a síntese nem acontece no caminho crítico, então o caso comum (tecla → `=`) já é instantâneo.

### D6 — Fallback `espeak-ng` e WRN-011

Se `import piper`/`onnxruntime` falhar, se o modelo não carregar, ou enquanto ele ainda está carregando, o serviço usa `espeak-ng`:

- reprodução pelo **mesmo** player raw: `espeak-ng -v pt-br --stdout <texto> | aplay ...`, ou `espeak-ng ... -w tmp.wav`;
- registra `WRN-011` (motor TTS degradado) uma vez, sem repetir a cada frase;
- **nunca bloqueia a entrada** (RF-08): a fila segue funcionando.

Isso mantém o dispositivo utilizável se o build do Piper falhar num campo, e cobre a janela de carga do modelo no arranque.

### D7 — Empacotamento na imagem: wheel pré-compilado + voz com sha256

O `build-alpine-img.sh` **não** compila o Piper dentro do fluxo normal (seria lento sob qemu e traria ~200 MB de toolchain). Em vez disso:

- um **wheel `musl/aarch64`** do `piper-tts` é produzido **uma vez** (num container `alpine:3.24` arm64 ou no próprio Pi, a partir da tag fixa do git) e versionado fora da imagem / baixado no build;
- o build instala o wheel com `pip install --no-deps <wheel>` **sobre** o `py3-onnxruntime` do apk (o `onnxruntime` não vem do pip);
- `pathvalidate` (Python puro) vem do pip;
- a voz `cadu` (`.onnx` + `.onnx.json`) é baixada com **sha256 fixo** e validada, no mesmo padrão do minirootfs do script;
- os modelos de outras línguas embutidos no `piper-tts` (`hebrew/`, `tashkeel/` — ~25 MB) são **apagados** do site-packages, já que só pt-BR é usado;
- o **smoke** deixa de ser `pyttsx3.init()` e passa a ser uma **síntese real** no chroot (Piper → PCM), sem placa de som — teste mais forte que o atual e possível sob qemu;
- o symlink `libespeak.so.1` (defensivo, só para o pyttsx3) é removido.

*Alternativa rejeitada:* compilar o Piper no `build-alpine-img.sh`. Torna o build lento e frágil e mistura toolchain com a imagem final.

### D8 — `py3-onnxruntime` pelo apk, não pelo pip

O `onnxruntime` do PyPI **não** tem wheel `musl`, e compilá-lo é enorme. O Alpine `community` v3.24 já traz `py3-onnxruntime` 1.24.4 para Python 3.14/musl. Vai para `system/rpi-os/alpine/packages`, e o wheel do Piper é instalado com `--no-deps` para não puxar o onnxruntime do pip.

*Efeito:* ~120 MB instalados (closure completo: numpy, openblas, protobuf, abseil, icu, sympy — medido no APKINDEX). É o maior item de tamanho da mudança e cabe na imagem de 2 GB.

### D9 — Multiprocessing vs. thread no motor residente

Hoje cada frase é um **processo** (fork/forkserver). Com o motor residente, o modelo vive no **processo principal**; o que é lançado por frase é o **`aplay`** (subprocesso), não um processo Python que recarrega o motor. Assim:

- não se paga fork + import + load por frase;
- no Pi (Python 3.14/forkserver) não há o risco de o filho não herdar o handler de SIGTERM (memória do projeto `pi-python-forkserver`), porque o `aplay` é um subprocesso comum, não um `multiprocessing.Process`;
- a síntese roda na thread worker do serviço; as threads do ONNX são limitadas (D2).

## Risks / Trade-offs

- **[Build do Piper sob qemu é lento e o sdist é incompleto]** → O wheel é compilado **fora** do fluxo do build (D7), uma vez, e reaproveitado. O `CMakeLists` baixa e compila o espeak-ng estático (tag fixa); sob qemu isso leva dezenas de minutos. Mitigação: compilar num container arm64 nativo ou no Pi, e fixar o artefato.
- **[Python 3.14 não é testado pelo upstream]** → a extensão é `abi3`, mas é preciso **validar** a síntese no chroot 3.14 (o smoke de D7 faz exatamente isso) antes de fechar a imagem.
- **[Latência maior em resultados longos]** → o Piper entrega a frase inteira de uma vez; um número grande pode levar centenas de ms a mais que o espeak-ng. Mitigação: "Resultado"/"Última resposta" saem do cache na hora (D4), e a síntese do número segue como frase seguinte.
- **[ALSA sem `dmix`: reprodução sequencial]** → nunca tocar Piper e fallback ao mesmo tempo, senão `Device or resource busy`. A fila já serializa; o código garante um único player ativo.
- **[Memória e CPU do modelo neural no Pi 4]** → +150–300 MB de RAM residente e picos de CPU na síntese. Threads do ONNX limitadas (D2); a síntese fora do caminho crítico via cache. Medir no hardware (tarefa 6).
- **[Interrupção não corta síntese em curso]** → aceito (D5); janela curta por frase, e o caso comum usa cache.
- **[Licença GPL-3.0 do `piper-tts`]** → o `espeak-ng` já é GPL; a `cadu` é CC0. Registrar a proveniência e a licença na imagem. Não afeta o código próprio do projeto (uso, não linkagem estática distribuída no mesmo binário do app).
- **[Tamanho]** → rootfs ~487 MB → ~0,7 GB. Cabe nos 2 GB; monitorar se a imagem crescer com o kernel/firmware.

## Migration Plan

Não há dados nem estado persistido. A migração é de **motor**; o texto falado e a API não mudam.

1. Provar o Piper/`cadu` **no Pi** (protótipo, tarefa 2): medir carga, latência (tecla, resultado longo), CPU, RAM e temperatura, com as frases reais.
2. Trocar o `speech.py` para o motor residente + cache + fallback, mantendo a API e os testes de fila/interrupção.
3. Empacotar (wheel, `py3-onnxruntime`, voz com sha256, smoke de síntese).
4. Validar no hardware; só então decidir se o apk `espeak-ng` do sistema é removido (fica fora desta mudança).

**Rollback:** reverter o commit devolve o `pyttsx3`/`espeak-ng`. Como o `espeak-ng` **permanece** na imagem (fonemizador + fallback), mesmo um Piper quebrado em campo mantém a voz por fallback.

## Open Questions

- **Threads do ONNX no Pi 4:** 2 ou 3? Depende da medição (tarefa 2) versus a carga do Tk + varredura da matriz.
- **Pré-aquecer todo o cache no arranque** ou só sob demanda na primeira ocorrência? A favor de aquecer: latência previsível desde a primeira tecla. Contra: alguns segundos de CPU no arranque (RNF-06). Decidir com a medição.
- **`length_scale`/velocidade:** manter o padrão da `cadu` (1.0) ou acelerar um pouco, como o `rate 175` do pyttsx3 hoje? É ajuste de UX de voz, a validar com a equipe.
- **Remover o apk `espeak-ng` do sistema depois:** vale os 19 MB, ou o fallback justifica mantê-lo? Fica para depois da validação no hardware.
- **Origem do wheel `musl/aarch64`:** compilar no CI (container arm64), no Pi, ou fixar um artefato no repositório de release? Decisão de infraestrutura de build.

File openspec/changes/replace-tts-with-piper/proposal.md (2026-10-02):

## Why

Hoje a voz da calculadora sai do `espeak-ng` através do `pyttsx3` (`software/accessibility/speech.py`, `requirements.txt`, `system/rpi-os/alpine/packages`). O `espeak-ng` é robusto e cabe no arranque rápido (RNF-06), mas soa **formântico e metálico**, o que atrapalha a inteligibilidade exigida pelo PRD §8 — justamente o requisito que serve o usuário com cegueira total, para quem a voz é o canal principal (RF-04, RF-07). O objetivo é uma voz **neural, natural e em português do Brasil**, mantendo o funcionamento **offline** e a política de interrupção (RF-08) que já existe.

O motor escolhido é o **Piper** (`OHF-Voice/piper1-gpl`, pacote `piper-tts`), TTS neural offline sobre `onnxruntime`, com Raspberry Pi 4 (aarch64) como alvo de primeira classe. A voz será a **`pt_BR-cadu-medium`** (22.050 Hz, 1 locutor, dataset CC0), que a equipe já escolheu e possui.

O trabalho não é uma troca de biblioteca linha a linha. Duas coisas o condicionam e estão na base desta proposta:

- **O modelo de processos do `speech.py` precisa mudar.** Hoje cada frase abre um **processo novo** (`_SpeakProcess`), que importa o motor e reinicializa a voz. Repetir isso com o Piper recarregaria um modelo de 63 MB a cada tecla — inviável. O motor tem de ficar **residente**.
- **O Piper não tem pacote pronto para o Alpine (musl).** Não há apk nem wheel `musl`. O `piper-tts` precisa ser **compilado** a partir do git (o `setup.py` usa CMake e embute o `espeak-ng` estaticamente); o `onnxruntime`, porém, **já existe** no repositório `community` do Alpine v3.24 aarch64 (`py3-onnxruntime` 1.24.4), que é a parte mais difícil e vem pronta.

Sem esta mudança, a calculadora continua com uma voz que cumpre a norma "pt-BR offline" na letra, mas não a intenção de **clareza** do PRD.

## What Changes

- **Motor de voz residente no `software/accessibility/speech.py`.** O `SpeechService` — a fila, o contador de geração (`_Generation`) e a política de interrupção — é **preservado**. O que muda por baixo:
  - Um **motor Piper residente** carrega o modelo `cadu` **uma vez** (em segundo plano, para não travar o arranque) e sintetiza frase a frase.
  - A reprodução passa a ser `aplay` lendo áudio **raw** (`-t raw -f S16_LE -c1 -r <sample_rate do .onnx.json>`) pela entrada padrão, sem WAV temporário e sem `os.system`. O grupo de processo e o `terminate()` que silenciam o `aplay` continuam válidos.
  - **Cache de frases fixas**: os nomes de tecla (`SPOKEN_TOKEN_NAMES`, 38), os dígitos, os textos de erro/aviso §13 e os anúncios fixos são sintetizados uma vez após o arranque e reproduzidos do cache. É o que mantém a latência por tecla igual ou melhor que hoje.
  - **Fallback**: se o Piper não estiver disponível (import falha, modelo ausente), o serviço cai para o `espeak-ng` (`--stdout | aplay`), registra `WRN-011` e **não bloqueia a entrada** (RF-08).
- **Voz `pt_BR-cadu-medium` embutida na imagem.** O modelo `.onnx` + `.onnx.json` é baixado no build com **sha256 fixo** (padrão do `build-alpine-img.sh`) e validado; nada é baixado no aparelho (offline).
- **`piper-tts` na imagem por wheel pré-compilado.** Um wheel `musl/aarch64` é compilado a partir da tag do `piper-tts` e instalado com `--no-deps` sobre o `py3-onnxruntime` do apk. O `onnxruntime` **não** vem do pip.
- **`py3-onnxruntime` adicionado a `system/rpi-os/alpine/packages`** (repositório `community`, já disponível).
- **`pyttsx3` removido** de `requirements.txt`: nenhum caminho passa a usá-lo.
- **Ambiente de desenvolvimento (Docker/CI)** atualizado: em glibc, `pip install piper-tts` funciona direto; um script baixa a voz `cadu`; o `Dockerfile` e o `Makefile` deixam de depender do `pyttsx3`.
- **Documentação e decisões registradas** atualizadas: PRD §12, `software/README.md`, `openspec/config.yaml` e a spec `rpi-boot-image` deixam de dizer "TTS via espeak-ng + pyttsx3" e passam a "Piper (voz cadu), com espeak-ng como fonemizador embutido e fallback".

## Capabilities

### New Capabilities
- `speech-engine`: o motor de síntese de voz offline em pt-BR. Cobre a escolha do Piper e da voz `cadu`, o motor **residente** (modelo carregado uma vez, sem processo por frase), a reprodução por `aplay` em áudio raw pela placa padrão do ALSA, o cache de frases fixas, o carregamento não-bloqueante no arranque (RNF-06), o fallback para `espeak-ng` (WRN-011) e a preservação do contrato de fila e interrupção do `SpeechService` (RF-08).

### Modified Capabilities
- `rpi-boot-image`: o requisito "TTS offline em português embutido" hoje exige `espeak-ng` **e** `pyttsx3`. Passa a exigir o **Piper** com a voz `cadu` embutida e offline, o `onnxruntime` do Alpine, e o `espeak-ng` mantido como fonemizador e fallback (o `pyttsx3` deixa de ser exigido).

## Impact

- **Código alterado:**
  - `software/accessibility/speech.py`: motor residente + player raw + cache + fallback. A API pública (`say`, `interrupt_and_say`, `stop`) e a fila/geração **não mudam**.
  - `software/requirements.txt`: remove `pyttsx3`; acrescenta `piper-tts` (com marcador de ambiente para não quebrar o build musl, que usa o wheel pré-compilado).
  - `system/rpi-os/alpine/packages`: acrescenta `py3-onnxruntime`.
  - `system/rpi-os/alpine/build-alpine-img.sh`: instala o wheel do Piper, baixa e valida a voz `cadu` (sha256), remove os modelos de outras línguas embutidos no `piper-tts` (hebraico/árabe, ~25 MB), troca o smoke de `pyttsx3.init()` por uma **síntese real** no chroot, e remove o symlink `libespeak.so.1` (que só servia ao pyttsx3).
  - `Dockerfile`, `docker-compose*.yml`, `Makefile`: dependências de desenvolvimento.
  - `docs/produto/PRD.md` §12, `software/README.md`, `docs/guias/build-img-linux.md`, `openspec/config.yaml`: texto das decisões.
- **Sem alteração:** os 5 consumidores do serviço de voz — `software/app.py`, `software/ui/lcd/app.py`, `software/ui/hdmi/app.py`, `software/audio_only.py`, `software/ui/shared/video_watch.py` — que só chamam `say` / `interrupt_and_say` / `stop`. Também ficam como estão `software/core/`, os textos falados (`ui/shared/keypad.py`, `history.py`, `error_messages.py`) e a saída de áudio no jack (`overlay/etc/asound.conf`, `usercfg.txt`).
- **Testes:** os testes de fila e interrupção do `SpeechService` continuam (com o motor injetável, sem Piper real). Os testes específicos do driver `pyttsx3`/espeak (`_EspeakLikeEngine`, `SpeakWaitsForPlaybackTest`) são reescritos para o motor residente. Entra um teste de cache e de fallback. A suíte segue rodando **sem Piper** no CI (Python 3.11), por import tardio.
- **Dependências:** `+py3-onnxruntime` e closure (~120 MB instalados, medidos no APKINDEX v3.24 aarch64), `+piper-tts` (wheel, ~35–60 MB) e a voz `cadu` (63 MB). O rootfs sai de ~487 MB para ~0,7 GB, dentro da imagem de 2 GB.
- **Requisitos cobertos:** PRD §8 (inteligibilidade), RNF-02 (TTS offline), RF-08 (a interrupção e a não-blocagem da entrada são preservadas), RNF-06 (carga do modelo não bloqueia o arranque) e RNF-04 (a mudança fica isolada em `accessibility/`).
- **Riscos principais:** build do Piper sob qemu (lento, sdist incompleto, Python 3.14 não testado upstream); latência maior em resultados longos; ALSA sem `dmix` (reprodução sequencial); memória e CPU do modelo neural no Pi 4. Detalhados no `design.md`.

## Não-objetivos

- **Não** mudar o **texto** falado, os nomes de tecla, nem o catálogo de mensagens §13. A migração é do **motor**, não do conteúdo.
- **Não** alterar a saída de áudio no jack de 3,5 mm (`asound.conf`/`usercfg.txt`), que é decisão de produto já registrada.
- **Não** remover o `espeak-ng` da imagem nesta mudança: ele é o fonemizador do Piper (embutido no wheel) e o **fallback**. A remoção do apk `espeak-ng` do sistema, se desejada, fica para uma mudança posterior, depois da validação no hardware.
- **Não** treinar nem afinar voz; usa a `cadu` publicada como está.
- **Não** usar GPU/CUDA (o Pi 4 não tem); o `onnxruntime` roda em CPU.
- **Não** ligar o Piper ao download de vozes em execução (`piper.download_voices`): o aparelho é offline; a voz vai embutida na imagem.
- **Não** adotar streaming intra-frase: o Piper entrega o áudio de uma frase inteira de uma vez. A mitigação (tocar "Resultado" do cache enquanto o número é sintetizado) é de implementação, não de escopo.

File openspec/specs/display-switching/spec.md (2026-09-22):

# display-switching Specification

## Purpose
TBD - created by archiving change add-hdmi-ui. Update Purpose after archive.

## Requirements

### Requirement: Prioridade do monitor HDMI sobre o LCD
Quando as saídas HDMI do LCD e do monitor externo estiverem ambas reconhecidas, o sistema SHALL selecionar o front-end do monitor (`DisplayMode.HDMI`) como saída principal, e o LCD SHALL NOT exibir a mesma interface principal.

#### Scenario: LCD e monitor reconhecidos simultaneamente
- **WHEN** `DisplaySelector.current_mode()` é consultado e tanto a saída HDMI do LCD quanto a do monitor externo estão reconhecidas
- **THEN** o resultado é `DisplayMode.HDMI`

### Requirement: Uso do LCD quando o monitor não está presente
Quando apenas a saída HDMI do LCD estiver reconhecida (monitor externo ausente), o sistema SHALL selecionar o front-end do LCD (`DisplayMode.LCD`).

#### Scenario: Somente LCD reconhecido
- **WHEN** `DisplaySelector.current_mode()` é consultado, a saída HDMI do LCD está reconhecida e a do monitor externo não está
- **THEN** o resultado é `DisplayMode.LCD`

### Requirement: Modo somente áudio sem vídeo utilizável
Quando nenhuma saída de vídeo estiver utilizável (nem LCD nem monitor reconhecidos, incluindo o caso do interruptor físico do LCD cortando sua saída HDMI), o sistema SHALL selecionar `DisplayMode.AUDIO_ONLY`, mantendo entrada por teclado e feedback por voz funcionando (RF-04).

#### Scenario: Nenhuma saída de vídeo reconhecida
- **WHEN** `DisplaySelector.current_mode()` é consultado e nem a saída HDMI do LCD nem a do monitor externo estão reconhecidas
- **THEN** o resultado é `DisplayMode.AUDIO_ONLY`

#### Scenario: Interruptor físico do LCD desligado sem monitor presente
- **WHEN** o interruptor físico do LCD corta sua saída HDMI (painel em standby) e o monitor externo não está reconhecido
- **THEN** `DisplaySelector.current_mode()` retorna `DisplayMode.AUDIO_ONLY`, tratando a saída do LCD como indisponível

### Requirement: Ponto de entrada único desperta o front correto
O sistema SHALL fornecer um único ponto de entrada que consulta `DisplaySelector.current_mode()` na inicialização e instancia exclusivamente o front correspondente (`ui_hdmi` para `HDMI`, `ui_lcd` para `LCD`, ou um laço somente-áudio para `AUDIO_ONLY`), sem instanciar mais de um front visual ao mesmo tempo.

#### Scenario: Inicialização com monitor presente
- **WHEN** o ponto de entrada é executado e `DisplaySelector.current_mode()` retorna `DisplayMode.HDMI`
- **THEN** apenas o front-end `ui_hdmi` é instanciado; `ui_lcd` não é iniciado

#### Scenario: Inicialização sem vídeo utilizável
- **WHEN** o ponto de entrada é executado e `DisplaySelector.current_mode()` retorna `DisplayMode.AUDIO_ONLY`
- **THEN** nenhum front visual (`ui_lcd` ou `ui_hdmi`) é instanciado, e o sistema opera aceitando teclado e respondendo por `SpeechService`

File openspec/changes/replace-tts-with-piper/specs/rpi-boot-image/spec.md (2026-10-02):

## MODIFIED Requirements

### Requirement: TTS offline em português embutido

A imagem SHALL incluir o motor **Piper** (`piper-tts` sobre `onnxruntime`) com a voz **`pt_BR-cadu-medium`** embutida, e a cadeia de áudio necessária para sintetizar voz em **português do Brasil** de forma **offline** (sem qualquer dependência de rede/nuvem), preservando o feedback por voz de entradas e resultados. O `onnxruntime` SHALL vir do repositório do Alpine (`py3-onnxruntime`), e o modelo de voz SHALL ser embutido na imagem com integridade verificada (sha256). O `espeak-ng` SHALL permanecer na imagem como fonemizador do Piper e como motor de **fallback**; o `pyttsx3` SHALL NOT ser exigido.

#### Scenario: Anúncio por voz sem rede

- **WHEN** o dispositivo está sem conexão de rede e o usuário realiza uma operação na calculadora
- **THEN** a entrada e/ou o resultado são anunciados por voz em português do Brasil (voz `cadu`), usando o motor local Piper, sem acessar a rede

#### Scenario: Motor de voz inicializa corretamente

- **WHEN** a aplicação inicia o serviço de TTS na imagem
- **THEN** o modelo `cadu` é carregado a partir da imagem e a síntese ocorre sem falha; se o Piper estiver indisponível, o sistema degrada para `espeak-ng` sem travar a entrada

#### Scenario: Voz embutida e verificada, sem download em execução

- **WHEN** a imagem é construída
- **THEN** o modelo `pt_BR-cadu-medium` (`.onnx` + `.onnx.json`) é incluído com sha256 verificado, e nenhum componente de voz é baixado quando o dispositivo está em uso

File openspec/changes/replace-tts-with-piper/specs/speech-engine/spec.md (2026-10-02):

## Purpose

Definir o **motor de síntese de voz** da calculadora: um TTS neural offline em português do Brasil (Piper, voz `cadu`), residente em memória, que reproduz pela placa de áudio padrão do sistema e preserva a política de fila e interrupção já exigida pelo RF-08. Serve à inteligibilidade do PRD §8 e ao funcionamento offline do RNF-02, sem alterar o texto falado nem os consumidores do serviço de voz.

## ADDED Requirements

### Requirement: Motor de voz neural offline em pt-BR (Piper + cadu)

O sistema SHALL sintetizar a voz com o motor **Piper** (`piper-tts`, sobre `onnxruntime`), usando a voz **`pt_BR-cadu-medium`**, de forma **offline** — sem qualquer dependência de rede ou nuvem. O modelo de voz (`.onnx`) e a sua configuração (`.onnx.json`) SHALL estar embutidos na imagem e SHALL NOT ser baixados em tempo de execução.

#### Scenario: Síntese sem rede
- **WHEN** o dispositivo está sem conexão de rede e uma entrada ou resultado precisa ser anunciado
- **THEN** o texto é falado em português do Brasil pela voz `cadu`, usando o modelo local, sem acessar a rede

#### Scenario: Voz cadu carregada da imagem
- **WHEN** o serviço de voz inicializa
- **THEN** o modelo `pt_BR-cadu-medium` é carregado de um caminho local da imagem, com o `sample_rate` lido do seu `.onnx.json`

### Requirement: Motor residente, sem recarregar por frase

O modelo de voz SHALL ser carregado **uma única vez** por execução e permanecer residente em memória. O sistema SHALL NOT recarregar o modelo a cada anúncio. Cada anúncio SHALL reutilizar o motor já carregado.

#### Scenario: Modelo carregado uma vez
- **WHEN** vários anúncios são feitos em sequência
- **THEN** o modelo de voz é carregado apenas na primeira vez e reutilizado nos anúncios seguintes, sem nova carga do arquivo `.onnx`

### Requirement: Carga não-bloqueante no arranque

A carga do modelo de voz SHALL NOT bloquear o arranque da aplicação (RNF-06). Enquanto o modelo ainda não está pronto, o sistema SHALL permitir que anúncios ocorram por um caminho degradado, sem travar a interface nem a entrada.

#### Scenario: Anúncio de prontidão não espera o modelo
- **WHEN** a aplicação inicia e anuncia que está pronta, antes de o modelo neural terminar de carregar
- **THEN** o anúncio é reproduzido de imediato pelo caminho de fallback, sem aguardar a carga do modelo

### Requirement: Reprodução pela placa de áudio padrão do sistema

O áudio sintetizado SHALL ser reproduzido pela placa de áudio **padrão do ALSA** (que a imagem fixa no jack de 3,5 mm), por meio do reprodutor do sistema (`aplay`), sem depender de servidor de som (PulseAudio). Em nenhum momento SHALL haver mais de um reprodutor de áudio ativo ao mesmo tempo.

#### Scenario: Som sai pela saída padrão
- **WHEN** um anúncio é reproduzido
- **THEN** o áudio sai pela placa padrão definida na configuração do ALSA da imagem, sem PulseAudio

#### Scenario: Reprodução serializada
- **WHEN** um anúncio está tocando e outro é solicitado
- **THEN** os anúncios são reproduzidos um de cada vez, sem dois reprodutores concorrentes sobre a mesma placa

### Requirement: Preservação da fila e da interrupção (RF-08)

O motor SHALL preservar o contrato de fila e interrupção existente: um anúncio de maior prioridade (resultado ou erro P1) SHALL interromper de forma consistente o anúncio em curso ou enfileirado de menor prioridade, e apenas o anúncio mais recente MUST ser reproduzido. A entrada por teclado SHALL NOT ficar bloqueada enquanto a voz fala.

#### Scenario: Resultado interrompe anúncio de tecla
- **WHEN** uma tecla está sendo anunciada e o usuário aciona a avaliação
- **THEN** o anúncio da tecla em reprodução é cortado e o resultado é falado, sem sobrepor os dois

#### Scenario: Anúncio obsoleto descartado sem tocar
- **WHEN** uma interrupção chega enquanto uma frase de menor prioridade ainda está sendo sintetizada e ainda não começou a tocar
- **THEN** essa frase é descartada por obsolescência e não chega a ser reproduzida

#### Scenario: Entrada não bloqueia durante a fala
- **WHEN** o usuário pressiona teclas enquanto um anúncio está em curso
- **THEN** as teclas são aceitas e processadas sem esperar o fim da fala

### Requirement: Cache de frases de conjunto fechado

O sistema SHALL manter em memória o áudio pré-sintetizado das frases de **conjunto fechado** — nomes de tecla, dígitos, mensagens de erro e aviso do PRD §13 e anúncios fixos — e reproduzi-las a partir desse cache, para manter a latência por tecla baixa. Resultados e expressões dinâmicas SHALL ser sintetizados sob demanda.

#### Scenario: Nome de tecla reproduzido do cache
- **WHEN** uma tecla cujo nome falado pertence ao conjunto fixo é anunciada, após o cache estar aquecido
- **THEN** o áudio correspondente é reproduzido do cache, sem nova síntese

#### Scenario: Resultado dinâmico é sintetizado
- **WHEN** um resultado numérico precisa ser anunciado
- **THEN** ele é sintetizado sob demanda pelo motor, pois não pertence ao conjunto fixo

### Requirement: Fallback quando o motor neural está indisponível

Se o motor Piper não puder ser carregado (dependência ausente, modelo ausente ou falha de carga) ou enquanto ainda está carregando, o sistema SHALL degradar para o motor `espeak-ng`, SHALL registrar o aviso `WRN-011` (motor TTS degradado) e SHALL NOT bloquear a entrada do usuário.

#### Scenario: Piper ausente cai para espeak-ng
- **WHEN** o motor Piper não está disponível no arranque
- **THEN** os anúncios são reproduzidos por `espeak-ng`, o sistema registra `WRN-011` e a calculadora continua utilizável

#### Scenario: Falha de voz não trava a entrada
- **WHEN** ocorre uma falha pontual na síntese ou na reprodução
- **THEN** a entrada por teclado continua sendo aceita e o erro é registrado, sem interromper o uso (RF-08)

### Requirement: Contrato de integração inalterado para os consumidores

A interface pública do serviço de voz (`say`, `interrupt_and_say`, `stop`) SHALL permanecer inalterada, de modo que os fronts (LCD, HDMI e somente áudio) e o observador de vídeo continuem funcionando **sem alteração**. A troca de motor SHALL NOT exigir mudanças fora do módulo de acessibilidade.

#### Scenario: Fronts não mudam
- **WHEN** um front chama `say` ou `interrupt_and_say` como faz hoje
- **THEN** o anúncio ocorre com o novo motor, sem que o código do front precise ser alterado

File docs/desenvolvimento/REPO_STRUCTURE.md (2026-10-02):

# Estrutura do repositório (mapa PRD → pastas)

Este documento liga o [PRD.md](../produto/PRD.md) à organização de código e hardware. **Não é obrigatório** criar tudo antes do primeiro commit: pastas vazias podem ganhar ficheiros à medida que as tasks avançam; a árvore abaixo é a **direção** acordada.

---

## Resumo visual

| Área no PRD | Pasta(s) |
| --- | --- |
| Motor de cálculo (§8), Python | [`software/core/`](../../software/core/) |
| Ponto de entrada (escolhe a saída ativa, §7) | [`software/app.py`](../../software/app.py) |
| Front LCD 7.x (§7) | [`software/ui/lcd/`](../../software/ui/lcd/) |
| Front monitor HDMI (§7) | [`software/ui/hdmi/`](../../software/ui/hdmi/) |
| Peças de UI partilhadas pelos dois fronts | [`software/ui/shared/`](../../software/ui/shared/) |
| Modo somente áudio (RF-04) | [`software/audio_only.py`](../../software/audio_only.py) |
| Áudio / TTS / acessibilidade (§8) | [`software/accessibility/`](../../software/accessibility/) |
| GPIO, UPS, detecção HDMI, integração | [`software/hw_platform/`](../../software/hw_platform/) |
| Testes (cruzados ou por módulo) | [`software/tests/`](../../software/tests/) + `tests/` dentro de cada pacote quando fizer sentido |
| PCI KiCad, fenolite (§6) | [`hardware/pcb/`](../../hardware/pcb/) — ver nota sobre `Placa Kicad/` |
| Imagem SO, `config.txt`, arranque, scripts (§12) | [`system/`](../../system/) |
| Datasheets, CAD, pinout, Waveshare | [`docs/`](../README.md) (já existente) |
| Cronograma interativo | [`cronograma/`](../../cronograma/) |

---

## KiCad e várias versões

- O projeto atual pode continuar em **`Placa Kicad/`** até migrarem sem problemas de caminhos; a pasta alvo versionada é **`hardware/pcb/<nome-do-projeto>/`** (um `.kicad_pro` por linha de produto).
- O KiCad gera **`/.history/`** com muitos ficheiros: está **ignorado no Git** (ver [`.gitignore`](../../.gitignore)). Para marcos (revisão, envio à gráfica), use **`hardware/pcb/snapshots/`** com subpastas datadas (ex.: `2026-06-10-gerbers-review/`) contendo export explícito (Gerber, PDF esquemático, STEP se necessário).

---

## Criar pastas “já” vs ir commitando

- **Convém** ter o **esqueleto** `software/*` e `system/` desde cedo: todos sabem onde pôr ficheiros e o PRD cita modularidade (RNF-04).
- **Não é obrigatório** preencher cada pasta na primeira sprint: ficheiros aparecem com as features.
- Quem trabalha com IA: no início da sessão, o [`prompts/bootstrap.txt`](../../prompts/bootstrap.txt) já pede leitura do PRD; **não é necessário um agente novo** só para pastas — opcionalmente mencionar *“seguir docs/desenvolvimento/REPO_STRUCTURE.md”* no chat se estiverem a refatorar árvore.

---

## Migração sugerida (quando quiserem)

1. Copiar ou mover o `.kicad_pro` + `.kicad_sch` + `.kicad_pcb` (+ bibliotecas locais) para `hardware/pcb/tcc-calculadora/` (nome ajustável).
2. Manter `Placa Kicad/` só como arquivo ou apagar após validar que o Git e o KiCad abrem o novo caminho.
3. Registar no [`CONTEXT.md`](CONTEXT.md) a pasta canónica da PCB.

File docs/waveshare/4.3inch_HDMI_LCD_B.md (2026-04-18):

# 4,3" HDMI LCD (B) — Waveshare — notas para o repositório

**Fonte:** [Waveshare Wiki — 4.3inch HDMI LCD (B)](https://www.waveshare.com/wiki/4.3inch_HDMI_LCD_(B))  
**Página do produto:** [4.3inch-hdmi-lcd-b.htm](https://www.waveshare.com/4.3inch-hdmi-lcd-b.htm)  
**Snapshot local:** 2026-04-17

LCD IPS **4,3"**, **800 × 480**, HDMI, painel táctil capacitivo (5 pontos), vidro temperado (dureza até **6H** segundo a wiki). Serve com Raspberry Pi (Raspberry Pi OS, Ubuntu, Kali, Retropie) ou como monitor em PC Windows.

---

## Características (resumo)

- Resolução de hardware **800 × 480**.
- Táctil capacitiva **5 pontos**; em PC Windows suporta Windows 11/10/8.1/8/7 com cinco pontos.
- Menu **OSD** multilingue (brilho, contraste, gestão de energia, etc.).
- **Jack áudio 3,5 mm** e conector de altifalante; áudio via HDMI.

---

## Uso com PC Windows

1. Ligar a interface **TOUCH** do LCD a uma porta **USB** do PC; aguardar reconhecimento do táctil.
2. Ligar o **HDMI** do LCD ao HDMI do PC; após ~**10 s** a imagem deve estabilizar.
3. Áudio: auscultadores no conector **HP** ou altifalante no conector indicado (ex.: **8 Ω, 5 W** na FAQ de áudio).

**Nota:** com vários monitores no Windows, o táctil deste LCD pode controlar apenas o cursor no **monitor principal**; a wiki recomenda definir este LCD como principal.

---

## Uso com Raspberry Pi

Sistemas referidos: Raspberry Pi OS, Ubuntu, Kali, Retropie. Imagem recomendada: versão atual do [site oficial Raspberry Pi](https://www.raspberrypi.com/software/operating-systems/).

1. Descarregar e extrair o `.img`.
2. Formatar o cartão (a wiki sugere [SDFormatter](https://files.waveshare.com/upload/d/d7/Panasonic_SDFormatter.zip) no Windows).
3. Gravar a imagem (a wiki sugere [Win32DiskImager](https://files.waveshare.com/upload/7/76/Win32DiskImager.zip)).
4. No cartão, editar **`config.txt`** na raiz (ou `/boot/firmware/config.txt` em layouts mais recentes) e **acrescentar no fim**:

```ini
hdmi_force_hotplug=1
hdmi_group=2
hdmi_mode=87
hdmi_cvt 800 480 60 6 0 0 0
```

5. Inserir o cartão no Pi.
6. Ligar **TOUCH** do LCD a **USB** do Pi.
7. Ligar **HDMI** do LCD ao **HDMI** do Pi; alimentar e aguardar alguns segundos.

---

## Teclas físicas (OSD)

| Tecla | Função |
| ----- | --- |
| **Power** | Liga / desliga o display (backlight); útil para reduzir consumo em repouso prolongado. |
| **Menu** | Abre o menu OSD; dentro do menu funciona como **OK**. |
| **Up / Left** | Navegação. |
| **Down / Right** | Navegação. |
| **Exit** | Sair; dentro do menu funciona como **voltar**. |

---

## Recursos (oficiais)

- [Desenho 3D (ZIP)](https://files.waveshare.com/wiki/4.3inch_HDMI_LCD_B/4.3inch_HDMI_LCD_3D_Drawing.zip)
- Cópia local extraída (STEP): pasta [`../cad/waveshare-4.3inch-hdmi-lcd-b/`](../cad/waveshare-4.3inch-hdmi-lcd-b/) (ver [`../cad/README.md`](../cad/README.md))

A wiki lista também software adicional na secção **Software** — confirmar na [página atual](https://www.waveshare.com/wiki/4.3inch_HDMI_LCD_(B)).

---

## FAQ (resumo útil)

### Quadrados coloridos no autoteste da GPU no arranque

Acrescentar a `/boot/config.txt` (ou equivalente em Bookworm):

```ini
disable_splash=1
```

### Substituir o logótipo de arranque (Raspberry Pi)

Substituir a imagem em:

`/usr/share/plymouth/themes/pix/splash.png`

### Toque longo = clique direito (Raspberry Pi)

A wiki descreve instalação de **evdev-rce** para sistemas **32 bits** Bullseye (exemplo datado **2022-04-04**); **64 bits** pode não ser suportado por defeito. Passos resumidos:

```bash
wget https://files.waveshare.com/upload/1/18/Evdev-right-click-emulation.zip
unzip Evdev-right-click-emulation.zip
cd evdev-right-click-emulation
sudo apt install build-essential libevdev2 libevdev-dev -y
sudo cp 'out/evdev-rce' '/usr/local/bin/'
sudo chmod +x '/usr/local/bin/evdev-rce'
```

Execução inicial:

```bash
sudo evdev-rce
```

Configuração de utilizador `pi`, módulo `uinput`, regra udev e arranque automático — ver secção completa na wiki (ficheiro `99-uinput.rules`, `autostart/right_click.desktop`, variáveis `LONG_CLICK_INTERVAL` e `LONG_CLICK_FUZZ`).

### O ecrã apaga sozinho?

Depende do sistema e da hibernação; no Raspberry Pi OS, por defeito pode haver escurecimento após ~**10 minutos** sem interação.

### Táctil em PC Linux “genérico”

Experimentar driver **hid-multitouch** no kernel.

### Temperatura de trabalho

**0 °C — 70 °C** (valores da wiki).

### Tensão e corrente típicas

~**5 V**, corrente ~**0,5 A** (indicativos da wiki).

### Brilho por PWM (hardware)

A wiki indica **remoção de uma resistência** indicada no desenho, ligação do pad **PWM** do ecrã ao **PWM** do Pi e **GND** comum, e comandos `gpio` de exemplo para PWM no GPIO 18 (consultar **figura na wiki** — não reproduzida aqui).

### Interface áudio 4 pinos (PH2.0)

Disposição de pinos: **+ − − +**. Altifalante sugerido: [8 Ω 5 W (Waveshare)](https://www.waveshare.com/product/displays/accessories/speakers/8ohm-5w-speaker.htm).

---

## Anti‑pirataria / imitações

A wiki inclui avisos sobre produtos falsificados e diferenças de qualidade. Em caso de dúvida sobre autenticidade, contactar o suporte Waveshare.

---

## Suporte

Formulário e horário na [página oficial](https://www.waveshare.com/wiki/4.3inch_HDMI_LCD_(B)) (GMT+8).

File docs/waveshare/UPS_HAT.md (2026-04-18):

# UPS HAT (Waveshare) — notas para o repositório

**Fonte:** [Waveshare Wiki — UPS HAT](https://www.waveshare.com/wiki/UPS_HAT)  
**Página do produto:** [UPS-HAT.htm](https://www.waveshare.com/UPS-HAT.htm)  
**Snapshot local:** 2026-04-17

UPS HAT para Raspberry Pi: alimentação ininterrupta a **5 V**, circuitos de proteção de bateria e comunicação por **I2C** para monitorização de tensão, corrente, potência e capacidade restante.

---

## Características (resumo)

- Header GPIO de **40 pinos** padrão Raspberry Pi.
- Barramento **I2C** para leitura em tempo real (tensão, corrente, potência, capacidade restante).
- Proteções: sobrecarga / sobredescarga, sobrecorrente, curto‑circuito, polaridade inversa; carga equilibrada entre células.
- Regulador **5 V** onboard, até **2,5 A** contínuos (valor indicado na wiki).
- Saída **5 V USB** para alimentar outros módulos.
- LEDs de **aviso** das baterias (útil para detetar inversão de polaridade na instalação).

---

## Especificações indicadas na wiki

| Parâmetro | Valor |
| --- | ----- |
| Tensão de saída | 5 V |
| Carregador | **8,4 V, 2 A** |
| Barramento de controlo | I2C |
| Bateria | 18650 Li **3,7 V** (não incluídas) |
| Capacidade de referência no material demo | **5200 mAh** total para 2 células (exemplo; baterias não incluídas) |
| Dimensões | 56 mm × 85 mm |
| Furo de montagem | 3,0 mm |

---

## Hardware e segurança

- A interface **8,4 V** é a **porta de carregamento**; usar o carregador adequado (8,4 V / 2 A) indicado pelo fabricante.
- O **interruptor** liga/desliga a alimentação (na documentação Waveshare também referem uso com Jetson Nano).
- **LEDs WARNING:** acendem se as baterias estiverem **invertidas**. **Não carregar** com polaridade invertida.
- Na **primeira instalação** das baterias, a placa pode não arrancar de imediato; pode ser necessário **carregar um pouco** para “ativar” as células.
- Usar **carregador adequado**; adaptadores inadequados podem danificar o módulo.

### Avisos de segurança (Li‑ion / Li‑po)

- Risco de incêndio ou danos se recarga ou uso forem incorretos.
- Não inverter polaridade; não usar carregadores de má qualidade.
- Não misturar baterias velhas com novas nem marcas diferentes.
- Comprar baterias compatíveis e de fabricantes fiáveis; respeitar ciclos de vida e substituir quando apropriado (a wiki sugere substituição após vida útil de ciclos ou **mais de dois anos**, o que ocorrer primeiro).
- Armazenar longe de inflamáveis e de crianças.

---

## Raspberry Pi: ativar I2C

```bash
sudo raspi-config
```

Interfacing Options → I2C → **Yes**, depois reiniciar:

```bash
sudo reboot
```

A HAT pode ir empilhada nos **40 pinos** ou ligada por fios; na ligação manual, **VCC** ao **3,3 V** conforme indicação da wiki (confirmar no esquemático do seu lote).

---

## Demo e código de exemplo (wiki)

```bash
sudo apt-get install p7zip
wget https://files.waveshare.com/upload/d/d9/UPS_HAT.7z
7zr x UPS_HAT.7z -r -o./UPS_HAT
cd UPS_HAT
python3 INA219.py
```

Após iniciar o servidor de exemplo, o terminal pode mostrar IP, tensão da bateria, corrente, percentagem estimada, e informação de CPU/GPU/memória (conforme demo).

**Sinal da corrente:**

- **Corrente negativa:** as baterias estão a **alimentar** o Raspberry Pi.
- **Corrente positiva:** as baterias estão a **carregar**.

---

## Endereço I2C

Na FAQ da wiki, o endereço indicado é **0x42**. Para verificar no sistema:

```bash
sudo apt-get install i2c-tools
sudo i2cdetect -y 1
```

(Em alguns modelos de Pi o barramento pode ser `0` em vez de `1`; ajuste conforme a sua placa.)

---

## Recursos para download (oficiais)

- [Demo codes — UPS_HAT.7z](https://files.waveshare.com/upload/d/d9/UPS_HAT.7z)
- [Demo codes V2 — UPS_HAT_V2.zip](https://files.waveshare.com/wiki/UPS_HAT_B/UPS_HAT_V2.zip)

Cópia local do STEP da HAT: pasta [`../cad/waveshare-ups-hat/`](../cad/waveshare-ups-hat/) (ver [`../cad/README.md`](../cad/README.md)).

Na wiki, na secção **Document**, há ainda ligações para desenho 3D, esquemático e datasheets (INA219, HY2120, HY2213). **Consulte sempre a página atual** para URLs atualizadas.

---

## FAQ (resumo da wiki)

| Questão | Resposta resumida |
| --- | --- |
| Altura com o Pi | ~**42,05 mm** empilhado. |
| Indicador do carregador | **Vermelho** a carregar; **verde** carregado (com carga ligada o estado pode manter‑se em vermelho — ver FAQ “green to red”). |
| Corrente negativa | Baterias a alimentar o Pi. |
| Tempo de carga (indicativo) | Da ordem de **~3 h** (condições dependentes das células e carga). |
| Desligar com bateria baixa | Por I2C é possível ler tensão/corrente/capacidade e **programar** gravação de dados e **shutdown** ordenado. |
| Percentagem ~88% “cheio” | O demo assume **5200 mAh**; com outras capacidades é preciso **ajustar parâmetros** no programa. |
| Duas fontes vs uma | Usar **apenas** a fonte **8,4 V / 2 A** na HAT é suficiente para o Pi na orientação da wiki; **não** ligar fonte direta ao Pi em paralelo conforme essa recomendação. |
| Arranque após instalar baterias | Pode ser preciso **carregar primeiro** para iniciar; se persistir falha, a wiki indica medições de tensão (ver **figuras na página oficial**). |

Para perguntas com **diagramas** (USB externo, teste de tensão, etc.), abra a [página oficial](https://www.waveshare.com/wiki/UPS_HAT).

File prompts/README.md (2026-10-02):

# Prompts do repositório (TCC Calculadora)

Arquivos de texto para colar em conversas com IA (ex.: Cursor) e padronizar rituais da equipe.

| Arquivo | Quando usar |
| --- | --- |
| [`bootstrap.txt`](bootstrap.txt) | **Início de sessão:** Git atualizado, branch correta, leitura de contexto antes de codar. |
| [`close-session.txt`](close-session.txt) | **Fim de sessão:** resumo, `docs/desenvolvimento/Sprints.md`, `docs/desenvolvimento/CONTEXT.md`, handoff. |
| [`agent-sprint-coach.txt`](agent-sprint-coach.txt) | **Durante a sessão:** saúde do sprint atual vs PRD e cronograma. |
| [`agent-weekly-squad-lead.txt`](agent-weekly-squad-lead.txt) | **Semanal:** retrospectiva, status do projeto, prioridades da próxima semana (papel tech/squad lead). |
| [`agent-github-sync.txt`](agent-github-sync.txt) | **Equipe / Git:** checar se a branch está atrás de `main`, explicar fluxo Gustavo → João e merge paralelo. |

Fluxo Git e convenções: [`docs/desenvolvimento/GITHUB_WORKFLOW.md`](../docs/desenvolvimento/GITHUB_WORKFLOW.md).  
Commits: [`.github/COMMIT_GUIDELINES.md`](../.github/COMMIT_GUIDELINES.md).

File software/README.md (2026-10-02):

# Software (calculadora)

Alinhado ao [PRD.md](../docs/produto/PRD.md) §8: **motor em Python**, **dois fronts** (LCD e HDMI), **áudio** em paralelo, módulos **sem** acoplar o núcleo à UI.

| Pasta | Conteúdo esperado |
| ----- | --- |
| `core/` | Parser, precedência, funções §5, códigos de erro; API estável para as UIs. |
| `app.py` | Ponto de entrada: escolhe a saída ativa (§7) e inicia **um** front. |
| `ui/lcd/` | Painel 4,3" — **somente a tela** (800x480 fixo): sem teclado nem botões, entrada só pelo teclado físico. |
| `ui/hdmi/` | Monitor externo — janela do tamanho da tela ativa, com **composição e tipografia derivadas da resolução** (ver "Faixas de layout" abaixo). |
| `ui/shared/` | O que os dois fronts partilham: textos de erro §13, paleta, teclado, formatação, histórico, regras de layout. |
| `audio_only.py` | Modo somente áudio (RF-04), sem janela gráfica. |
| `accessibility/` | TTS, fila de anúncios, política de interrupção (RF-08); idioma pt-BR. |
| `hw_platform/` | GPIO / matriz teclado, leitura UPS quando existir, detecção de saídas HDMI (helpers). |
| `tests/` | Testes de integração ou smoke que cruzam módulos. |

## Faixas de layout (front HDMI)

O monitor externo não tem resolução conhecida, então o front escolhe **na
construção** o que cabe na tela — como a calculadora do Windows, que vai
soltando painéis conforme estreita. Teclado e histórico são conveniências: a
entrada real é o **teclado físico** (RF-05), então nenhuma faixa reduz o
catálogo de operações do PRD §5.

| Faixa | A partir de | Mostra |
| ----- | --- | --- |
| completa | 1200x700 | expressão, resultado, teclado e histórico |
| média | 900x600 | expressão, resultado e teclado |
| compacta | abaixo disso | expressão e resultado |

A tipografia acompanha a resolução por um fator `min(largura/1280, altura/720)`
limitado a **[0,75 ; 2,0]** — o piso protege quem tem visão parcial (PRD §4), o
teto evita que num 4K sobrem três botões por linha.

Os limiares e a escala vivem **num ponto só**, em
[`ui/shared/layout.py`](ui/shared/layout.py): ajustar um número não exige ler o
front inteiro. O módulo é livre de Tk de propósito, e por isso testável sem
display (`tests/test_hdmi_layout_tiers.py`); a ligação com os widgets é
verificada à parte, com janela (`tests/test_hdmi_layout_wiring.py`).

A janela **não** redimensiona: a decisão é tomada uma vez. Numa troca de saída
de vídeo (RF-09) o front é reconstruído, e aí a tela nova é lida de novo.

Cada subprojeto pode ter o seu próprio `tests/` ou `pyproject.toml` quando a stack estabilizar.

## Dependências

- **Python:** `ttkbootstrap` e `piper-tts` (voz neural cadu, sobre `onnxruntime`), com versões fixadas em [requirements.txt](requirements.txt). Em glibc (CI/Docker/host) o `piper-tts` vem do PyPI; na imagem Alpine (musl/aarch64) ele é instalado por um wheel pré-compilado + `py3-onnxruntime` do apk (ver `system/rpi-os/alpine/`).
- **Sistema:** `python3-tk` (Tkinter), `alsa-utils` (`aplay`, que reproduz o PCM) e **`espeak-ng`** — agora como **fonemizador do Piper** e motor de **fallback** (WRN-011), não mais como voz principal.
  > A voz principal é a neural **`cadu`** (Piper). Baixe-a para o caminho padrão com `scripts/download-piper-voice.sh /opt/piper/voices` (o Docker já faz isso no build). Sem a voz ou sem o Piper, o serviço degrada para o `espeak-ng` e registra `WRN-011`, sem travar a entrada (RF-08). Use `espeak-ng`, não o `espeak` clássico.
- **Testes:** só a biblioteca padrão (`unittest`) — nenhuma dependência extra. Ver `make check`.

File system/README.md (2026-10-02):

# Sistema (SO / arranque / imagem)

Área para tudo o que não é “aplicação Python” mas é necessário ao produto no Raspberry Pi 4B, conforme [PRD.md](../docs/produto/PRD.md) §12.

| Subpasta | Uso sugerido |
| --- | --- |
| `rpi-os/` | Scripts de configuração, snippets de `config.txt`, unidades `systemd`, políticas de utilizador `kiosk`, notas de pacotes. |
| `buildroot/` | Receitas ou `defconfig` se optarem por imagem Buildroot (pode ficar vazia até haver decisão). |

**Regra:** não commitar imagens `.img` completas (ocupam muito espaço); documentar como gerar a imagem a partir de scripts ou CI, se mais tarde existir.

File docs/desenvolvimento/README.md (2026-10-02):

# Desenvolvimento — como a equipe trabalha

Processo, estado e memória do trabalho de **Gustavo, João e Yuri**. Nada aqui descreve o produto (isso é [../produto/](../produto/README.md)); tudo aqui descreve *como chegamos lá*.

| Documento | Quando se lê | Quando se escreve |
| --- | --- | --- |
| [CONTEXT.md](CONTEXT.md) | **Início** de sessão — onde a anterior parou, pendências, próximo foco | **Fim** de cada sessão |
| [Sprints.md](Sprints.md) | Ao escolher o que fazer — backlog por sprint, responsável e status | Ao concluir ou criar task |
| [GITHUB_WORKFLOW.md](GITHUB_WORKFLOW.md) | Antes de abrir branch ou PR — convenções de nome e sequência de comandos | Ao mudar a convenção da equipe |
| [REPO_STRUCTURE.md](REPO_STRUCTURE.md) | Ao não saber onde um ficheiro deve morar — mapa PRD → pastas | Ao criar área nova no repositório |
| [sessoes/](sessoes/README.md) | Para saber o que cada pessoa fez na semana N | **Fim** de cada sessão, no ficheiro `semana-NN.md` |

## Ciclo de uma sessão

1. **Abrir:** ler `CONTEXT.md` e a task em `doing` no `Sprints.md` (prompt: [`../../prompts/bootstrap.txt`](../../prompts/bootstrap.txt)).
2. **Trabalhar:** branch a partir de `main` atualizada, conforme `GITHUB_WORKFLOW.md`.
3. **Fechar:** atualizar `CONTEXT.md`, marcar o status no `Sprints.md` e registar em `sessoes/semana-NN.md` (prompt: [`../../prompts/close-session.txt`](../../prompts/close-session.txt)).

## Relacionado

- Prazos académicos: [`../../cronograma/cronograma.md`](../../cronograma/cronograma.md)
- Mensagens de commit: [`../../.github/COMMIT_GUIDELINES.md`](../../.github/COMMIT_GUIDELINES.md)
- Propostas de mudança em aberto: [`../../openspec/changes/`](../../openspec/changes/)

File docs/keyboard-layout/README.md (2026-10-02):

# Layout de teclado (Keyboard Layout Editor)

Este diretório contém o ficheiro **[keyboard-layout(9).json](keyboard-layout%289%29.json)** no formato exportado pelo site **[Keyboard Layout Editor](https://www.keyboard-layout-editor.com/)** (KLE).

## Como abrir ou editar

1. Abra [keyboard-layout-editor.com](https://www.keyboard-layout-editor.com/).
2. Menu **Raw data** (painel lateral) ou **Upload JSON** / importação equivalente.
3. Carregue o ficheiro `keyboard-layout(9).json` desta pasta.
4. Para guardar alterações: **Download JSON** no KLE e substitua o ficheiro no repositório (ou guarde com novo nome e atualize este README).

## Formato

O KLE usa um **array de linhas**; cada linha é um array de teclas. Cada tecla pode ser:

- uma **cadeia de texto** (legenda visível), ou
- um **objeto** com propriedades como `w` (largura em unidades de tecla), `h` (altura), `x` / `y` (posição em grelha), etc.

Documentação informal da sintaxe: painel **Raw data** do próprio site e [repositório do projeto no GitHub](https://github.com/ijprest/keyboard-layout-editor) (licença e código).

## Pinagem (GPIO)

A ligação da matriz **6×7** aos pinos do Raspberry Pi está em [raspberry-pi-4b/pinout.md §6](../raspberry-pi-4b/pinout.md#6-matriz-do-teclado-67--atribuição-de-gpio) (linhas, colunas, cor de fio e conflitos de periférico), com a fonte em código em [`software/hw_platform/keypad_pinout.py`](../../software/hw_platform/keypad_pinout.py). Este layout KLE descreve as **legendas**; o pinout descreve os **fios**.

## Relação com o projeto

Este layout descreve a **grelha de teclas da calculadora científica** (funções tipo `sen`, `cos`, `tan`, `log`, `π`, `Ans`, `Shift`, etc.) para:

- documentação visual do teclado;
- ferramentas que importem JSON do KLE (por exemplo fluxos **KiCad** com plugins que aceitem este formato — confirme sempre o caminho do ficheiro nas preferências do plugin).

## Ficheiros

| Ficheiro | Descrição |
| --- | --- |
| `keyboard-layout(9).json` | Dados crus do layout (export KLE). |

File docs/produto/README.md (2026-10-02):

# Produto — requisitos e definição

O que a calculadora **deve** ser. Esta pasta é a referência normativa: quando o código diverge daqui, ou o código está errado, ou o PRD precisa ser atualizado — não se resolve por decisão isolada.

| Documento | Conteúdo |
| --- | --- |
| [PRD.md](PRD.md) | **Documento de requisitos de produto** (v1.5): personas, requisitos funcionais (RF) e não funcionais (RNF), saídas de vídeo, catálogo de funções, códigos de erro, SO/arranque |
| [materiais-e-metodos-tcc.md](materiais-e-metodos-tcc.md) | **Materiais e métodos** do TCC: componentes de hardware, especificações e finalidade de cada peça no protótipo |

## Como se lê o PRD

- **RF-xx / RNF-xx** são os identificadores citados pelo backlog, pelas propostas em [`../../openspec/`](../../openspec/) e pelos comentários no código — cite sempre o identificador, não o número da seção.
- Mudança de escopo entra **primeiro** no PRD e no [cronograma](../../cronograma/cronograma.md), depois vira task em [../desenvolvimento/Sprints.md](../desenvolvimento/Sprints.md).

## Relacionado

- Comportamento já implementado do teclado: [../guias/comandos-teclado.md](../guias/comandos-teclado.md)
- O que foi validado contra os requisitos: [../testes/](../testes/README.md)

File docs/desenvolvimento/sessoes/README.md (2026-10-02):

# Registro de sessões (equipe)

Objetivo: ao **fim de cada sessão** de trabalho, cada pessoa **anota o que desenvolveu**; **uma vez por semana do plano** tudo fica reunido no **mesmo ficheiro**, visível para Gustavo, João e Yuri e versionado no Git.

---

## Convenção de ficheiros

- Um ficheiro por **Semana N** do [`cronograma/cronograma.md`](../../../cronograma/cronograma.md) (domingo a sábado, semana 1 = 01/03–07/03/2026).
- Nome: **`semana-NN.md`** com `NN` de **01** a **30** (ex.: `semana-07.md`).
- Local: esta pasta `docs/desenvolvimento/sessoes/`.

Para saber **N** a partir da data de hoje: usar o [`cronograma/cronograma.html`](../../../cronograma/cronograma.html) (indica “Semana N do plano”) ou contar a partir de 01/03/2026.

---

## Estrutura dentro de cada `semana-NN.md`

Cada ficheiro tem três secções fixas (**Gustavo**, **João**, **Yuri**). Em cada sessão, a pessoa **acrescenta** no fim da sua secção um bloco com data e conteúdo (não apagar registos antigos da mesma semana).

Modelo de bloco por sessão:

```markdown
#### AAAA-MM-DD — resumo curto (opcional)

- **Task / ID:** ex. T1.2, ou descrição livre se ainda sem ID.
- **Feito:** bullets objetivos (o que foi implementado, decidido ou documentado).
- **PR / branch:** opcional.
- **Bloqueios / próximo:** opcional.
```

---

## Fluxo recomendado

1. Durante a semana, cada um vai **acrescentando** blocos no `semana-NN.md` correto (pode ser no fim de sessão ou antes do push).
2. No **close-session** (prompt [`prompts/close-session.txt`](../../../prompts/close-session.txt)), incluir atualização deste registo junto com [`CONTEXT.md`](../CONTEXT.md) e [`Sprints.md`](../Sprints.md).
3. Integrar em `main` com o resto do trabalho para os outros verem o histórico agregado.

---

## Ficheiros

| Ficheiro | Semana do plano (exemplo) |
| --- | --- |
| [`_template-semana.md`](_template-semana.md) | Modelo vazio para copiar ao criar `semana-NN.md` novo |
| [`semana-07.md`](semana-07.md) | Semana 7 — 12/04 a 18/04/2026 (exemplo inicial) |

Crie `semana-08.md`, etc., quando entrar a semana seguinte (ou crie todos de uma vez a partir do template, se preferirem).

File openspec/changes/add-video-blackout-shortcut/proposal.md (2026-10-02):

## Why

O produto é uma calculadora para quem **não depende da tela**: a voz é o canal principal (RF-04, RNF-02) e a entrada é o teclado físico (RF-05). Hoje, porém, **não existe forma de apagar a tela** — o LCD embutido fica aceso durante toda a sessão mesmo para um utilizador cego, que não tira nenhum proveito dele.

Isso custa duas coisas. **Autonomia:** o painel é uma carga permanente sobre o UPS HAT, cuja bateria é explicitamente limitada (§11, RF-06) — luz que ninguém olha é bateria desperdiçada. **Privacidade e conforto:** a expressão em curso e o resultado ficam visíveis a quem estiver por perto, e num ambiente escuro (sala de aula, quarto partilhado) o painel incomoda terceiros sem servir ao dono.

O interruptor físico do LCD (§7.0) **não** resolve: ele age só no LCD, é uma peça mecânica fora do alcance do software, e o PRD §7.4 trata o seu desligamento como *ausência de vídeo utilizável* — o app cai para `AUDIO_ONLY` e **destrói o front**, perdendo a UI e o modelo de interação por teclas. Não há nada equivalente para o monitor externo, e nada que o utilizador consiga acionar sem tirar a mão do teclado.

O RF-04 já prevê exatamente este estado — «operar em modo somente áudio quando o display estiver **desligado** ou indisponível» — mas hoje só o alcançamos por acidente de hardware, nunca por comando do utilizador.

## What Changes

- **Novo comando de teclado: apagar/religar as telas.** Um atalho alterna (*toggle*) entre `aceso` e `apagado`. Ao apagar, **todas** as saídas de vídeo do X são desligadas via `xrandr --off`: o LCD (HDMI0) e também o monitor externo (HDMI1) **quando estiver conectado**. Ao religar, a saída volta a ser escolhida pela regra de prioridade já existente do PRD §7.2 (monitor > LCD) — o comando não fixa painel nenhum.
- **A calculadora continua a funcionar, inteira, com as telas apagadas.** O front (janela Tk) **não** é destruído: continua a receber teclas, a calcular e a anunciar por voz. Esta é a diferença essencial em relação ao `DisplayMode.AUDIO_ONLY`, que existe para *ausência de hardware de vídeo* e troca o front por um laço de linha de comando. Apagar a tela é uma **preferência do utilizador**, não uma mudança de modo — expressão em curso, `Ans`, histórico e o estado graus/radianos ficam intactos.
- **Atalho `Ctrl` + `AC`, com teclas que já existem na matriz.** A matriz 6x7 real **não tem** tecla livre para o comando (a `?` que constava de `keypad.py` e dos ficheiros KLE não existe no teclado físico). O comando passa a ser a **função secundária de `AC`** com `Ctrl` — o mesmo modelo do `Ctrl` + `Ans` do histórico: não desloca nenhuma função científica do §5, não exige alteração de PCB, e é **o mesmo atalho no PC** (`Ctrl` e depois `Esc`). `AC` é a tecla de «voltar ao neutro», e sozinha continua a ser a via de recuperação (ver abaixo).
- **Confirmação por voz obrigatória, em ambos os sentidos.** Com a tela apagada o utilizador não tem retorno visual nenhum: o anúncio é a **única** prova de que o comando funcionou e a única forma de descobrir como desfazer. O anúncio de desligamento inclui a tecla que religa.
- **Anti-armadilha: `AC` sempre religa.** A tecla `AC` (`Esc` no PC), que já significa «volta ao estado neutro», passa a religar a tela quando ela está apagada. Sem isto, um utilizador vidente que acione o comando por engano fica perante um aparelho aparentemente morto — o modo mais grave de falha que esta mudança pode introduzir.
- **A escolha sobrevive à troca de painel (RF-09).** Se um monitor for ligado ou desligado com as telas apagadas, o `VideoOutputWatch` continua a fazer a entrega entre fronts, mas o novo front **nasce apagado**: uma reconfiguração de hardware não deve cancelar em silêncio uma escolha explícita do utilizador.
- **Novo código de aviso `WRN-013`** registado no PRD §13, como a própria secção exige para códigos novos. **Não** se reusa o `WRN-012`: ele já designa a *troca automática de saída* do RF-09, e dar duas leituras opostas à mesma frase quebraria a regra «mesmo código → mesmo significado» das convenções do projeto.
- **Documentação:** `docs/guias/comandos-teclado.md` deixa de listar `?` como tecla reservada (ela não existe na matriz) e passa a descrever o comando `Ctrl` + `AC`; o `README.md` da imagem Alpine ganha o caso na checklist de bring-up. Os ficheiros KLE não são alterados por esta mudança.

## Capabilities

### New Capabilities
- `video-blackout`: apagar e religar, por comando do utilizador, **todas** as saídas de vídeo reconhecidas, mantendo o front ativo e a calculadora plenamente operável por teclado e voz; inclui a confirmação falada, a via de recuperação garantida (`AC`) e a persistência da escolha ao longo da sessão.

### Modified Capabilities
(nenhuma.) O `display-switching` foi examinado e **não** muda ao nível de requisito: os seus requisitos descrevem o resultado de `DisplaySelector.current_mode()` e qual front é instanciado, e o blackout não toca em nenhum dos dois — a prioridade monitor > LCD continua a decidir qual painel *seria* usado, e continua a nascer exatamente um front por modo. A interação real (com o blackout ativo, a entrega de front do RF-09 tem de propagar o estado em vez de o descartar) é comportamento **da nova capacidade**, e fica especificada nela.

## Impact

- **Código alterado:** `software/hw_platform/video_output.py` (função para desligar todas as saídas e reler o estado para confirmar), `software/app.py` (`point_x_at` respeita o blackout; o estado acompanha o laço `run_mode`), `software/ui/hdmi/app.py` e `software/ui/lcd/app.py` (ligação da tecla e anúncio — mesmo comportamento nos dois fronts), `software/ui/shared/keypad.py` (`AC` ganha a função secundária `BLACKOUT`; a `?` inexistente sai do catálogo), `software/ui/shared/video_watch.py` (propagação do estado na entrega).
- **Sem alteração:** `software/core/` — o motor de cálculo não sabe que existe tela, e continua assim (regra do projeto); `software/hw_platform/display.py`, cuja regra de prioridade do §7 já está correta; o catálogo matemático do PRD §5.
- **Documentação alterada:** `docs/produto/PRD.md` §13 (registo do `WRN-013`), `docs/guias/comandos-teclado.md`, `system/rpi-os/alpine/README.md`.
- **Testes novos** em `software/tests/`, seguindo o padrão de `test_video_output.py`: o caminho `xrandr` é *mockado*, de modo que a suíte continua a correr sem servidor X no CI (Python 3.11).
- **Requisitos cobertos:** RF-04 (o «display desligado» que o requisito já previa passa a ser alcançável por comando), RF-05 (mapeamento de teclas documentado), RF-06 (autonomia do UPS), RF-09 e RNF-03 (a escolha atravessa o hotplug sem travar o app).
- **Risco principal:** deixar o utilizador sem forma de religar. Mitigado pelo anúncio falado que nomeia a tecla, pelo `AC` como via de recuperação e pelo facto de o estado nunca sobreviver a um reinício.

## Não-objetivos

- **Não** alterar o escopo matemático do PRD §5 nem o catálogo de funções: `AC` não tinha função com `Ctrl`, e o atalho não desloca nenhuma operação existente.
- **Não** acrescentar teclas à matriz nem alterar a PCB ou os ficheiros KLE.
- **Não** acoplar `software/core/` a `xrandr`, a Tk ou a qualquer noção de tela.
- **Não** substituir nem replicar o interruptor físico do LCD (§7.0), que continua a ser a via de hardware e a ser lido como ausência de vídeo.
- **Não** redefinir a prioridade monitor > LCD do §7.2, nem introduzir espelhamento ou uso simultâneo das duas telas.
- **Não** implementar economia de energia automática (apagar por inatividade, temporizador, ou reação ao nível de bateria do UPS): esta mudança entrega apenas o comando explícito. O gancho automático fica para uma mudança futura, se o TCC o justificar.
- **Não** persistir a preferência entre encerramentos — alinhado ao RF-13 e ao RF-06, que dispensam persistência de sessão. O aparelho arranca sempre com a tela acesa.
- **Não** desligar a **retroiluminação** do painel por GPIO/DSI nem cortar energia do monitor: o alcance é o CRTC do servidor X, que é o que o software controla de forma portável.

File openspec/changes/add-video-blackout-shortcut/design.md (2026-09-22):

## Context

Ver `proposal.md` — Why para a motivação, e `specs/video-blackout/spec.md` para os requisitos.

O que já existe e condiciona a abordagem:

- **`hw_platform/video_output.py`** já sabe falar com o `xrandr`: descobre os nomes reais das saídas (`read_outputs()`), aplica um layout exclusivo numa única chamada (`activate()`) e **relê o estado para confirmar** que o CRTC mudou, porque o código de saída do `xrandr` só diz que o comando foi aceite. Tudo é melhor-esforço: fora do Pi não há X e as chamadas reportam falha em vez de levantar exceção.
- **`app.py:run_mode()`** é um laço: `point_x_at(mode)` → `start_front(mode, state, speech)`. O front devolve o modo que assume a seguir (ou `None` para sair). O `CalculatorState` é construído **uma vez** e atravessa todas as trocas de front — é assim que a expressão em curso sobrevive ao RF-09.
- **`ui/shared/video_watch.py`** faz a entrega: sonda o *sysfs* de 2 em 2 segundos e, ao detetar mudança, destrói a janela para que o laço construa o outro front.
- **`ui/shared/keypad.py`** listava uma tecla `?` com token vazio, mas **ela não existe na matriz 6x7 real** — não há tecla livre. `AC` e `Del` são as teclas de controlo sem função secundária com `Ctrl`, e o `Ctrl` + `Ans` do histórico já estabeleceu o modelo «comando = modificador + tecla existente».
- Os dois fronts (`ui/lcd`, `ui/hdmi`) têm `_bind_keyboard()` e `_handle_token()` deliberadamente espelhados.

Restrição decisiva: `xrandr --off` desativa o **CRTC**, não o conector. O *sysfs* continua a reportar `connected`, logo o `DisplayWatcher` **não** vê o blackout como mudança de vídeo e não dispara entrega de front. Isto é o que torna a funcionalidade possível sem tocar na máquina de estados do §7.4.

## Goals / Non-Goals

**Goals:**
- Manter o blackout **inteiramente fora** de `DisplayMode`, para que a máquina de estados do PRD §7.4 continue a significar exatamente «que hardware de vídeo existe».
- Um único ponto que aplica vídeo ao servidor X, para que acender e apagar não possam divergir.
- Comportamento idêntico nos dois fronts sem duplicar lógica — mesma regra que já pôs `video_watch.py` em `ui/shared/`.
- Testável no CI sem servidor X, pelo mesmo padrão de *mock* de `test_video_output.py`.

**Non-Goals:**
- **Não** usar DPMS (`xset dpms force off`): o DPMS reacende a qualquer evento de input, e num aparelho cujo único meio de interação é o teclado a tela reacenderia na tecla seguinte. É a razão técnica pela qual o alcance é o CRTC.
- **Não** desligar retroiluminação por GPIO/DSI nem cortar energia do monitor.
- **Não** acrescentar opção de linha de comando para arrancar apagado — contraria o requisito de arranque sempre aceso.

## Decisions

### D1 — O blackout é estado de sessão, não um `DisplayMode`

**Escolha:** um objeto de sessão mutável, criado em `run_mode()` e passado a `point_x_at()` e a cada front.

**Alternativa rejeitada — `DisplayMode.BLACKOUT`:** `DisplayMode` decide **qual front construir**. Um valor novo obrigaria `start_front()` a escolher um front para um estado que não tem front próprio, e a entrega do RF-09 passaria a ter de distinguir «mudou o hardware» de «o utilizador carregou numa tecla». Pior: `AUDIO_ONLY` troca o front pelo `AudioOnlyCalculator`, que lê **linhas inteiras** do stdin — um modelo de interação completamente diferente do teclado tecla-a-tecla. Reaproveitá-lo destruiria a expressão em curso e mudaria o significado de cada tecla.

**Alternativa rejeitada — guardar em `CalculatorState`:** viola a regra do projeto de manter `core/` sem qualquer noção de UI ou de vídeo.

**Alternativa rejeitada — global de módulo em `video_output`:** invisível nos testes, e obrigaria a limpeza entre casos.

Como o objeto pertence ao laço `run_mode()`, a persistência através da troca de front (RF-09) sai **de graça**: é o mesmo mecanismo que já preserva o `CalculatorState`, e não há estado a serializar.

### D2 — Um único ponto aplica o vídeo

`point_x_at()` passa a consultar o estado de sessão: apagado → desliga todas as saídas; aceso → mantém o comportamento atual (`activate()` no painel escolhido pela prioridade do §7.2). O *toggle* nos fronts apenas inverte o sinalizador e chama esse mesmo ponto.

Consequência desejada: o reacendimento **não** precisa de recordar qual painel estava aceso. Ele reexecuta a regra de prioridade, e por isso um monitor ligado ou removido durante o blackout é automaticamente respeitado — sem código adicional.

### D3 — Desligar tudo numa só chamada, e verificar

`xrandr --output <A> --off --output <B> --off` numa única invocação, pela mesma razão que `activate()` já documenta: o servidor reconfigura uma vez em vez de piscar entre dois comandos. A seguir, relê `read_outputs()` e confirma que **nenhuma** saída ficou ativa — o código de saída do `xrandr` diz que o comando foi aceite, não que o CRTC obedeceu.

Os nomes das saídas vêm de `read_outputs()`/`output_name()`, que já resolvem a divergência `HDMI-A-1` (sysfs) vs `HDMI-1` (driver X) na ordem env var → saída presente no X → convenção. Nada de nomes adivinhados.

### D4 — `Ctrl` + `AC`, igual na matriz e no PC

**Escolha:** `BLACKOUT` é a função secundária (`Ctrl`) da tecla `AC`. Na matriz: `Ctrl` e depois `AC`. No PC: `Ctrl` e depois `Esc` (o `Esc` já é o `AC`).

**Porquê `AC`:** é a tecla de «voltar ao estado neutro», e **sozinha** continua a ser a via de recuperação (D5). Quem apaga por engano recupera com a tecla ao lado do dedo, sem precisar de lembrar o modificador. Como toda a função secundária, `Ctrl` + `AC` **substitui** a primária — não limpa a expressão — e consome o `Ctrl`.

**Porquê não outra:** a matriz não tem tecla livre (a `?` do catálogo antigo não existe no hardware). `Ctrl` + `Del` funcionaria, mas separaria o atalho da via de recuperação em teclas diferentes; `Shift` + `AC` fica livre para o futuro. `Ctrl` + `Shift` + tecla está tomado pelo modo «o que faz esta tecla?», que continua a apenas **descrever** `AC` e as suas duas funções.

**Teclado de PC:** o teclado chega ao `_handle_token()` sem o `secondary` da definição da tecla — o mesmo problema que o `Ans` já resolve atribuindo `HISTORY` quando vem vazio. `AC` recebe o mesmo tratamento. Não há atalho extra no PC (`v`, `<question>`): o comando é o mesmo nos dois teclados, como o do histórico. No Windows, `Ctrl`+`Esc` *em simultâneo* abre o menu Iniciar; como o `Ctrl` da calculadora é fixo, pressiona-se em sequência — o kiosk do Pi não tem esse conflito.

**Nome falado:** o anúncio de desligamento nomeia **`AC`** como a tecla que religa (a mais curta das duas vias, e a mesma no PC como `Esc`).

### D5 — `AC` como via de recuperação, em código partilhado

A regra «`AC` reacende antes de limpar» vive num módulo novo `ui/shared/video_blackout.py`, junto com o objeto de sessão e as frases do `WRN-013`. Os fronts chamam-no de `_handle_token()`. Mesma justificação que pôs `video_watch.py` em `ui/shared/`: um só comportamento para os dois fronts, e testável com um duplo em vez de uma janela real.

### D6 — `WRN-013` novo, em vez de reusar `WRN-012`

O PRD §13 exige que códigos novos sejam registados na secção. `WRN-012` designa a **troca automática** de saída do RF-09 e é anunciado como «Saída de vídeo alterada» — o próprio `video_output._warn_layout()` já documenta a recusa em dar dois sentidos à mesma frase. Um comando deliberado do utilizador é outro evento e recebe outro código.

### D7 — Dimensionamento da janela durante o blackout

O front HDMI dimensiona-se por `video_output.screen_size()`. Com todos os CRTC desligados, o ecrã X pode reportar um tamanho degenerado, e uma reconstrução de front durante o blackout (hotplug) escolheria a faixa de layout errada. Mitigação: durante o blackout, o dimensionamento usa o modo **preferido da saída-alvo** em vez do tamanho corrente do ecrã, caindo para o comportamento atual quando o valor não for legível.
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

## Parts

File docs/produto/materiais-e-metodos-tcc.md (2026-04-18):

# Materiais e Métodos (TCC)

Esta lista detalha os componentes de hardware e materiais utilizados na construção do protótipo da Calculadora Científica Acessível, documentando suas especificações e finalidades dentro do escopo do projeto de Trabalho de Conclusão de Curso (TCC).

## 1. Placa de Processamento Principal

### Raspberry Pi 4 Model B
* **Especificações Principais:** 8GB de RAM.
* **Descrição:** A unidade principal de processamento (Single-Board Computer) para o projeto. É responsável por rodar o Sistema Operacional e o motor de cálculo da aplicação integrado à lógica visual (via saídas HDMI para monitor e LCD) e sonora (TTS pelo áudio) do projeto de acessibilidade.

## 2. Periféricos de Tela e Interface

### 4.3inch HDMI LCD (B)
* **Produto:** 4.3inch Capacitive Touch Screen LCD
* **Especificações:**
  * Tecnologia TFT IPS com tela de 4.3 polegadas.
  * Resolução em hardware de 800 × 480 pixels.
  * Controle por toque capacitivo de 5 pontos; painel de vidro temperado de dureza até 6H.
  * Possui *Jack de áudio* embutido de 3.5mm para alto-falante, extraindo suporte nativo de áudio via HDMI.
  * Menu OSD multicamada controlado por botões para gerenciar energia, brilho e contraste.
* **Descrição:** Funciona como o painel local do produto. Comportando-se como interface principal caso o monitor externo não esteja presente. Pode ter sua visualização suspensa através do envio de sinais controlados ou pelo interruptor de energia do vídeo. É montado externamente e suporta os sistemas operacionais principais do projeto.
* **Link de Referência:** [Wiki Waveshare 4.3inch HDMI LCD (B)](https://www.waveshare.com/wiki/4.3inch_HDMI_LCD_(B))

### Cabo Plano Flexível (FFC) compatível com HDMI
* **Nome do Produto:** Cabo plano flexível compatível com HDMI FFC, Raspberry Pi 4 Micro H, DMI para HD, Mini HDM I, 90 graus, FFC, Fita de 20Pin FPV
* **Variantes Adquiridas:** Conectores A4, D1, e fita FFC medindo 15cm.
* **Descrição:** Um cabo em formato achatado de 20-pinos focado em espaços curtos/aero (FPV) e com angulação a 90°. Projetado para estabelecer um canal direto que transmita os dados da conexão Micro HDMI (A4) provinda do Pi 4 para as conexões Mini HDMI ou Standard (D1) da tela LCD, ocupando pouco volume físico na espessura do equipamento.
* **Link:** [AliExpress](https://pt.aliexpress.com/item/1005004030924780.html)

## 3. Gestão e Alimentação

### UPS HAT (Uninterruptible Power Supply)
* **Model:** UPS HAT para Raspberry Pi
* **Especificações:**
  * Opera com interface padrão de 40-Pinos do Raspberry Pi (GPIO header).
  * Comunicação de barramento I2C, monitorando ativamente tensão de baterias, corrente, energia elétrica e capacidade limite contínua.
  * Regulador a bordo de 5V gerando correntes de saída de até 2.5A.
  * Suporta duas baterias do formato de Lítio (Li) 18650 de 3.7V (oferecendo idealmente em total 5200mAh instalados).
  * Requerimento para carga total de entrada: 8.4V 2A através do plugue DC.
  * Elementos de circuitos integrados englobam proteção para: curto-circuito, sobrecarga ou descarga excessiva, reverso na polaridade da bateria e um sistema atuando balanço de recarga (equalizing charge).
  * Medições do módulo de 56mm x 85mm.
* **Descrição:** É o cérebro auxiliar de estabilidade operacional — fornecendo uma funcionalidade perene no estilo bateria de *notebook*. Ajuda na continuidade elétrica isolada e suporta verificação das correntes via I2C. Quando o poder da capacidade entra num nível abaixo, é ele quem provê o gatilho para os avisos por interface de áudio (TTS) sem impor reinicialização forçada abrupta do Pi.
* **Link de Referência:** [Wiki Waveshare UPS HAT](https://www.waveshare.com/wiki/UPS_HAT)

## 4. Teclado Mecânico Físico Tátil

### Cherry MX Red Switches
* **Produto:** Switch Red 
* **Especificações:**
  * Estilo de Chave: Linear.
  * Força de Atuação Requerida (Resistência): Leve, de apenas 45 cN.
  * Ponto de Pré-Curso: Distância curta em torno de 2.0 mm de fundo de tecla de acionamento rápido base.
  * Curso Total: 4.0 mm.
  * Resistência certificada: Mais de 100 milhões de repetições suportadas no switch.
* **Descrição:** Adotados para perfazer a rede de botões tátil principal (organizados numa matriz customizada 7x7 de portas lógicas atreladas nas interfaces GPIO). Eles asseguram digitações mais constantes e velozes para o usuário, ao mesmo tempo criando uma ausência do 'click' mecânico notório o que deixa a trilha mais suave (linearidade), e deixa a evidência puramente atrelada aos anúncios áudios (bipe eletrônico / voz) da Calculadora Acessível.
* **Link de Referência:** [Guia do Switch Cherry MX](https://www.daskeyboard.com/blog/cherry-mx-switches/)

## 5. Áudio e Retorno Auxiliar (TTS)

### Cabo de Áudio 90 Graus 3.5mm TRS
* **Nome do Produto:** 90 graus 3.5mm trs/trrs cabo de áudio estéreo 3.5mm a 3.5mm ângulo direito cabo aux para fone de ouvido mp3 smartphone tablet alto-falantes do carro
* **Especificações:** Comprimento de 0.2m (20 centímetros), 3 Polos TRS operantes na modalidade Macho para Fêmea e extremidades contornadas com geometria ergonômica de 90° (ângulo direito).
* **Descrição:** Solução física restrita para cabiar internamente a saída de áudio base do minicomputador para as aberturas do gabinete em direção aos fones de ouvidos de usuário do TCC, acomodando mais perfeitamente no compartimento sem que dobras excessivas do cabo de áudio resultem no mal contato e que a estabilidade das ondas vitais de informações verbais acustificadas fiquem resguardadas.
* **Link:** [AliExpress](https://pt.aliexpress.com/item/1005008288720867.html)

## 6. Integrantes Customizados Físicos

### Placa de Circuito Impresso (PCI)
* **Características / Dimensões:** Modelo dupla face de tamanho limite de 15×15 cm.
* **Método de Confecção:** Placa em base de tipo Fenolite. O design logístico efetuado através do KiCad com subsequente gravação corrosiva num laboratório físico utilizando percloreto de ferro.
* **Descrição:** A fundação rígida do layout âncora; que alinha eletrificamente as bases operantes dos perfis de switches do tipo *hotswap*. É um substrato desenhado explicitamente contendo em si cabeçotes do cabeamento conectivo paralelo no formato de trilha (cabo flat) que termina sendo ligado nos terminais elétricos nativos expansivos do Raspberry Pi em formato de 7x7 portas de colunas interligadas.

### Elementos Braille de Encapsulamento
* **Composição de Obra / Fabrica:** Estruturada no elemento de modelagem termoplástica chamado PLA nativo. O procedimento material é manufaturado pela impressora compacta 3D modelo *Bambu Lab A1*.
* **Descrição:** Corpos e superfícies táteis de acoplamento do controle dos chassis (botões, *switches* de interruptores das peças do LCD) contendo demarcações estendidas das texturas do formato da linguística brasileira de deficiência visual (Braille PT-BR). Propõem um ambiente onde os utilizadores do limite físico de cegueira ou visibilidade reduzida alcancem acessibilidade na indicação de operação do hardware local.

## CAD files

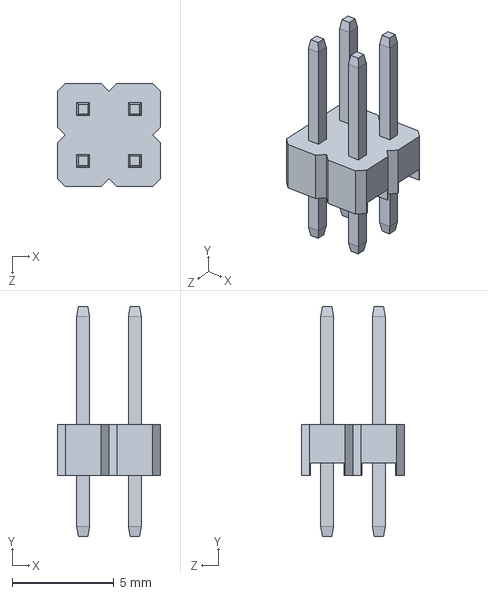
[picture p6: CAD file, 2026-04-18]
docs/cad/raspberry-pi-4-model-b/2.54 mm DUPONT MALE PIN HEADER, POE, 2X2, RPi4ModelB.SLDPRT
5.08 x 11.3 x 5.08 mm

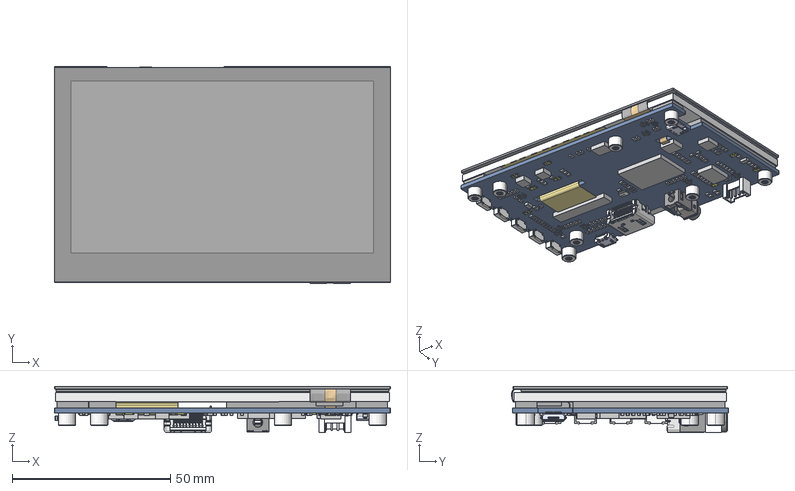
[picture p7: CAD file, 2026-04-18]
docs/cad/waveshare-4.3inch-hdmi-lcd-b/4_3inch-HDMI-LCD_B.stp
106.1 x 68.5 x 14.6 mm
43H-800480-IPS
43H-800480-TP
EVA-2MM
OPEN_CASCADE_STEP_TRANSLATOR_7_
EXTRUDED-4327 x 45
EXTRUDED-4610 x 15
EXTRUDED-4802 x 2
EXTRUDED-5044 x 3
EXTRUDED-5269 x 37
USER_LIBRARY-SOT-363
EXTRUDED-16048 x 24
EXTRUDED-16275 x 8
EXTRUDED-16467 x 8
EXTRUDED-16659 x 8
EXTRUDED-16851 x 6
EXTRUDED-19233 x 2
EXTRUDED-21782
EXTRUDED-22053 x 9
EXTRUDED-22434
EXTRUDED-23024 x 9
EXTRUDED-23216 x 3
USER_LIBRARY-MICROUSB-B_MOLEX_1 x 2
SMTSO-M2_5-4ET x 8
HDMI-19PIN-SMT
MICROPHONE_PLUG__RPI4MODELB_ASM
HP2_0-4PIN-PLUG_IN-VERTICAL
SWITCH-7X3_3X3_5 x 5
C0001

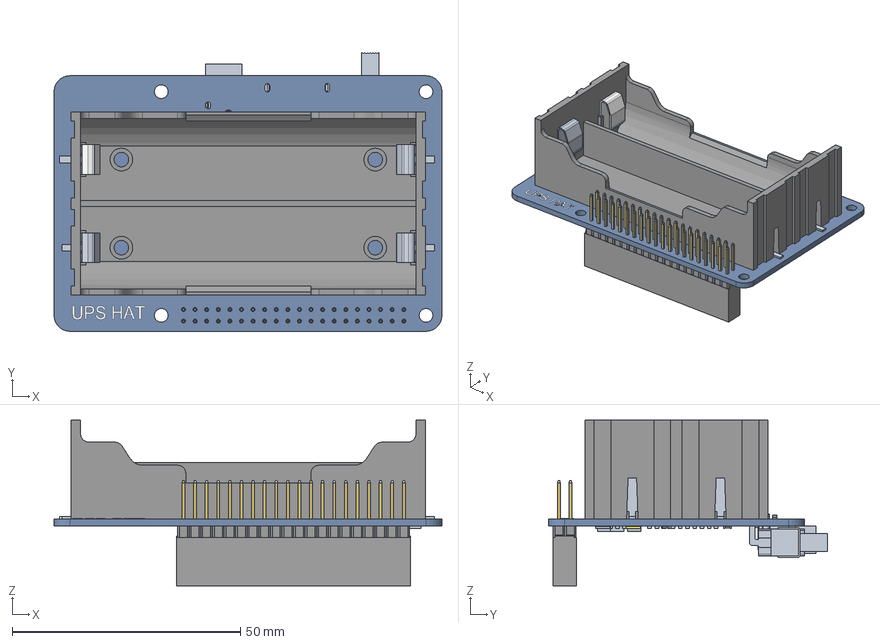
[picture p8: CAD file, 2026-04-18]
docs/cad/waveshare-ups-hat/ups-hat_20221117.stp
85.0 x 61.0 x 36.4 mm
PCB_1
PCB_2
PCB_3
PCB_4
PCB_5
PCB_6
PCB_7
PCB_8
PCB_9
PCB_10
PCB_11
PCB_12
PCB_13
PCB_14
PCB_15
PCB_16
PCB_17
PCB_18
PCB_19
PCB_20
PCB_21
PCB_22
PCB_23
PCB_24
PCB_25
PCB_26
PCB_27
PCB_28
PCB_29
PCB_30
PCB_31
PCB_32
PCB_33
PCB_34
PCB_35
PCB_36
PCB_37
PCB_38
PCB_39
PCB_40
PCB_41
PCB_42
PCB_43
PCB_44
PCB_45
PCB_46
PCB_47
PCB_48
PCB_49
PCB_50
PCB_51
PCB_52
PCB_53
PCB_54
PCB_55
PCB_56
PCB_57
PCB_58
PCB_59
PCB_60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

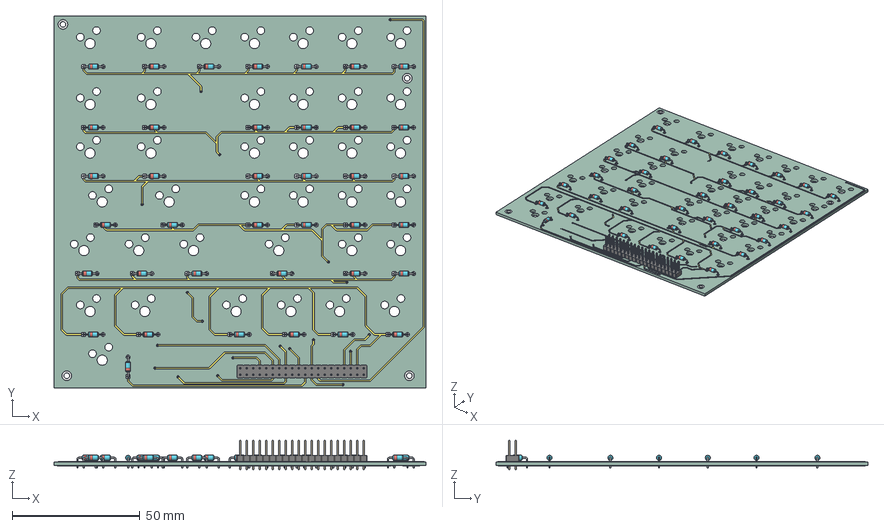
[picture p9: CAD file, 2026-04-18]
hardware/pcb/TCC-06-17-2026-PTH/Placa/Placa1.0.step
145.5 x 145.5 x 11.5 mm
D_DO-35_SOD27_P7.62mm_Horizontal x 38
PinHeader_2x20_P2.54mm_Vertical
tcc-16-04-2026-1322_copper
tcc-16-04-2026-1322_pad
tcc-16-04-2026-1322_via
tcc-16-04-2026-1322_PCB

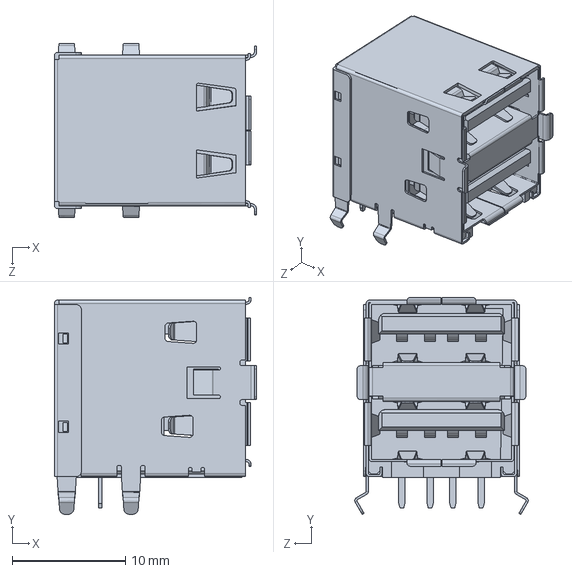
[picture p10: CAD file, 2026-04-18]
docs/cad/raspberry-pi-4-model-b/2X USB2.0 PORTS, RPi4ModelB.SLDPRT
17.9 x 19.2 x 15.3 mm

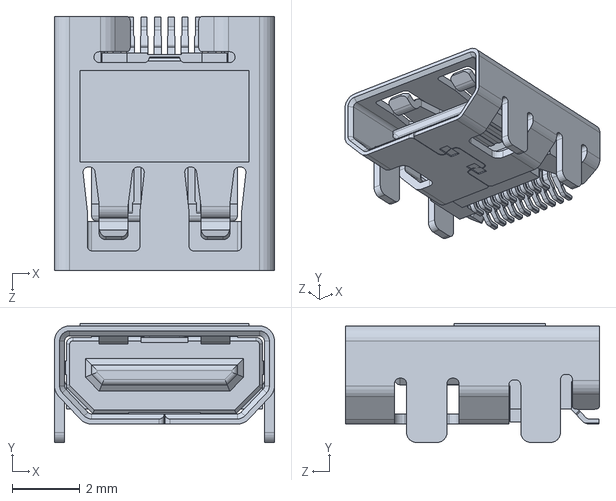
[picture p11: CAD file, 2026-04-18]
docs/cad/raspberry-pi-4-model-b/Female Micro HDMI Connector, RPi4ModelB.SLDPRT
6.50 x 3.52 x 7.50 mm

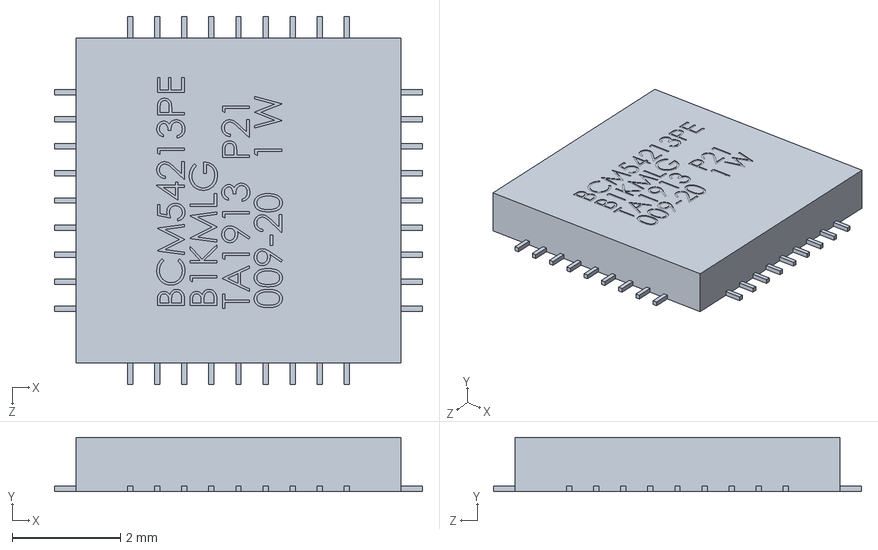
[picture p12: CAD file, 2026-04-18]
docs/cad/raspberry-pi-4-model-b/Broadcom BCM54213PE Gigabit Ethernet Transceiver, RPi4ModelB.SLDPRT
6.80 x 1.00 x 6.80 mm

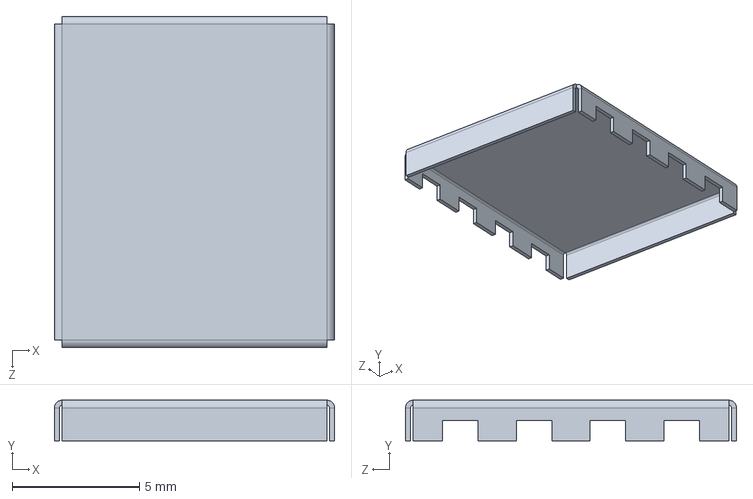
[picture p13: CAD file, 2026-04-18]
docs/cad/raspberry-pi-4-model-b/Cypress CYW43455 Wireless Module Cover, RPi4ModelB.SLDPRT
11.0 x 1.60 x 13.0 mm

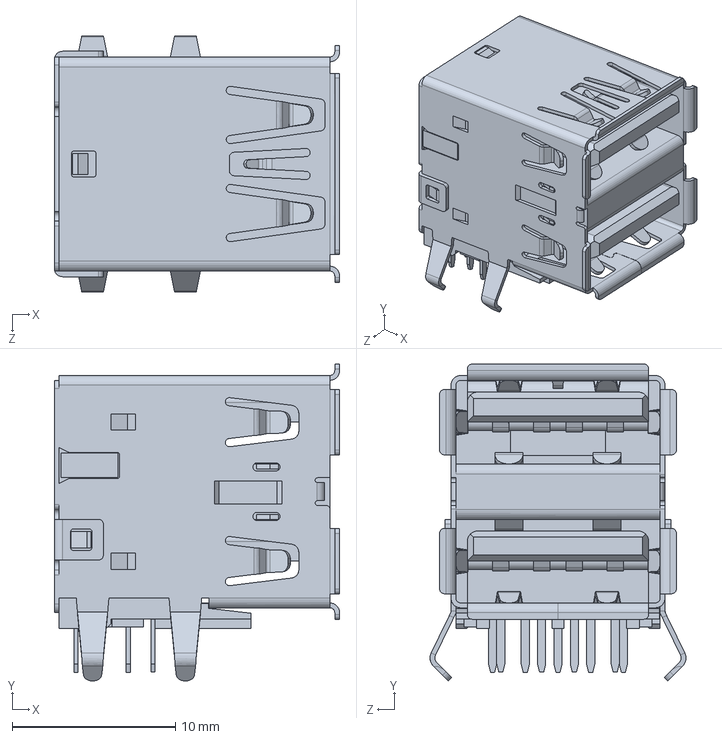
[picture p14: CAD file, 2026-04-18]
docs/cad/raspberry-pi-4-model-b/2X USB3.0 PORTS, RPi4ModelB.SLDPRT
17.5 x 19.4 x 15.7 mm

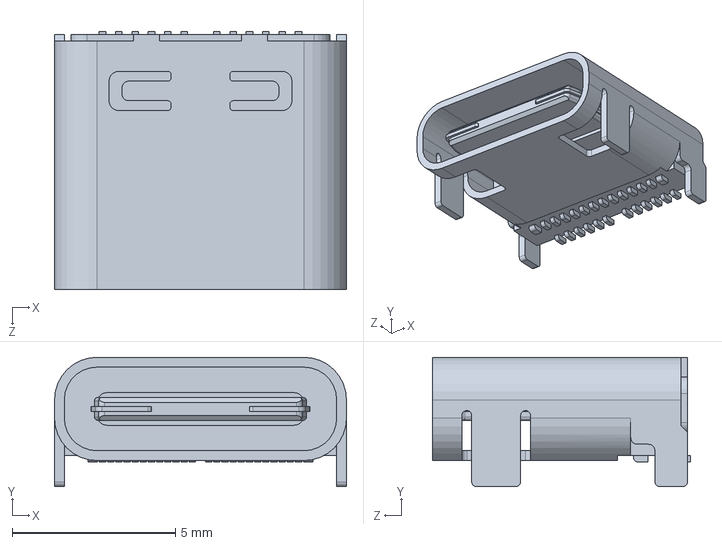
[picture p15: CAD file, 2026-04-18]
docs/cad/raspberry-pi-4-model-b/Female USB Type C Connector, RPi4ModelB.SLDPRT
8.94 x 3.96 x 7.90 mm

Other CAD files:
docs/cad/raspberry-pi-4-model-b/Broadcom BCM2711B0 CPU, RPi4ModelB.SLDPRT
docs/cad/raspberry-pi-4-model-b/Display Connector, RPi4ModelB.SLDPRT
docs/cad/raspberry-pi-4-model-b/Microphone Plug, RPi4ModelB.SLDPRT
docs/cad/raspberry-pi-4-model-b/Raspberry Pi 4 Model B.x_b
docs/cad/raspberry-pi-4-model-b/VIA VL805 PCIe USB 3.0 controller, RPi4ModelB.SLDPRT

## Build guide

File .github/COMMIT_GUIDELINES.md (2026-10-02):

# Diretrizes de commit (TCC Calculadora)

Padronização de mensagens de commit para este repositório (equipe: Gustavo, João, Yuri).  
Base: [Conventional Commits](https://www.conventionalcommits.org/) (mesma ideia do guia “Service-Desk”, adaptada ao projeto).

---

## 1. Objetivo

- Manter histórico **legível** e fácil de bisectar (`git bisect`).
- Facilitar **revisão** em PR e, no futuro, **changelog** semi-automático.
- Alinhar comunicação entre hardware, firmware/software e documentação.

---

## 2. Formato

```
<tipo>[escopo opcional]: descrição curta em inglês
```

- **Título:** imperativo (“add”, “fix”, não “added” / “fixes”).
- **~72 caracteres** no título (recomendado).
- **Corpo (opcional):** linha em branco após o título; explicar *por quê*, listar pontos importantes, referenciar issue/PR.

Exemplo com corpo:

```text
feat(ui): add basic LCD layout shell

Wireframe only; behavior in follow-up PR.
Closes #12
```

---

## 3. Tipos (quando usar)

| Tipo | Uso neste projeto |
| ---- | --- |
| `feat` | Nova funcionalidade ou melhoria visível (UI, cálculo, integração GPIO, fluxo da calculadora). |
| `fix` | Correção de bug ou falha de integração. |
| `docs` | README, `docs/`, PRD, comentários de documentação, diagramas. |
| `style` | Formatação, lint, imports — **sem** mudança de comportamento. |
| `refactor` | Reestruturação de código sem novo comportamento. |
| `perf` | Otimização de tempo, CPU ou memória. |
| `test` | Testes unitários, integração ou e2e. |
| `chore` | Manutenção geral: dependências, scripts, tarefas de housekeeping. |
| `build` | Build, empaquetamento, toolchain (ex.: scripts de release). |
| `ci` | Apenas pipelines (`.github/workflows`, etc.), sem mudar código de produto. |

---

## 4. Escopo (opcional, recomendado quando claro)

Ajuda em monorepos ou pastas grandes. Exemplos para este trabalho:

- `feat(calc):` — núcleo de expressões / precisão.
- `feat(ui):` / `feat(lcd):` — interface no painel.
- `fix(gpio):` — leitura de teclado / pinagem.
- `docs(pinout):` — `docs/raspberry-pi-4b/`.
- `docs(waveshare):` — notas UPS/LCD.
- `hardware(kicad):` ou `hardware(layout):` — PCB, esquemático, teclado.
- `chore(repo):` — `.gitignore`, prompts, organização de pastas.

Use escopo **curto** e consistente na equipe.

---

## 5. Fluxo rápido

```powershell
git checkout -b feature/descricao-curta
# ... alterações ...
git add -A
git commit -m "feat(ui): add display status placeholder" -m "Scaffold only; logic in next task."
git push -u origin feature/descricao-curta
```

Abrir **Pull Request** para `main`; referenciar issue, se existir (`Closes #n` no corpo).

---

## 6. Ajustes locais (com cuidado)

- `git commit --amend` — corrigir **última** mensagem ou incluir arquivos esquecidos (antes do push, ou com acordo da equipe se já publicado).
- `git reset --soft HEAD~1` — desfazer último commit mantendo alterações no stage/working tree.
- `git rebase -i HEAD~n` — reorganizar mensagens/commits **antes** de merge (alinhar com a equipe; evitar reescrever histórico compartilhado sem necessidade).

---

## 7. Regras fixas da equipe

1. Mensagens em **inglês** (título e, de preferência, corpo).
2. Um commit deve representar uma **unidade lógica** de mudança quando possível (facilita review).
3. Usar **escopo** quando deixar o contexto óbvio (`feat(lcd):`, `docs(workflow):`, etc.).

Documento irmão: [`docs/desenvolvimento/GITHUB_WORKFLOW.md`](../docs/desenvolvimento/GITHUB_WORKFLOW.md).

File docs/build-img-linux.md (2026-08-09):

# Rodar a calculadora como sistema embarcado (kiosk) no Raspberry Pi 4B

Objetivo: ao **ligar o Pi, ele arranca direto no aplicativo** da calculadora —
sem mostrar o SO, desktop ou terminal. Referência: [PRD.md](../../PRD.md) §12
(SO/arranque) e RNF-06 (boot rápido).

---

## Duas decisões distintas

1. **Como o app arranca sozinho (modo kiosk)** — é o trabalho de verdade;
   funciona igual em qualquer base de SO.
2. **Como empacotar/distribuir** — imagem Linux pronta vs instalar no Pi OS.
   É só "como entregar", não muda o comportamento.

---

## Opções de empacotamento

| Abordagem | Boot | Esforço | Recomendação |
| --- | ---- | --- | --- |
| **Pi OS Lite + kiosk** | ~15–25 s | Baixo | ✅ Começar por aqui |
| **Alpine (`system/rpi-os/alpine/`)** | rápido (enxuto) | Médio | ✅ Imagem por script, kiosk embutido; alternativa leve ao Buildroot |
| **Buildroot** (`system/buildroot/`) | ~3–8 s | Alto | ⚠️ Só se precisar provar boot ultrarrápido (RNF-06) |
| **Docker no Pi** | Lento | Médio | ❌ Não usar no produto (bom só p/ testar no PC) |

> "Gerar uma imagem que tenha ela" **não** exige Buildroot: configure o Pi OS
> Lite uma vez, valide, e **clone o cartão para um `.img`** (ver abaixo). Isso já
> é uma imagem Linux com o app embutido, reprodutível e sem a dor do Buildroot.
>
> **Docker não é forma de embarcar** GUI no aparelho final — foi útil apenas
> para desenvolvimento/teste no PC.

---

## Como o kiosk funciona (Pi OS Lite)

O app é Tkinter, então precisa de um X11 mínimo — mas **sem desktop**, só o app:

```
Liga o Pi
  → Autologin no console (raspi-config → Boot → Console Autologin)
  → ~/.bash_profile dispara:  startx
  → ~/.xinitrc prepara a tela e executa:  python3 -m software.app
  → Só a janela da calculadora na tela (sem menu, sem barra, sem cursor)
```

O `.xinitrc` também **reinicia o app se ele cair** (laço `while true`), fazendo o
papel de um `Restart=always` sem a complicação de iniciar o X a partir de um
serviço systemd (que exige mexer no `Xwrapper.config`).

---

## Passo a passo (Pi OS Lite + kiosk via ~/.xinitrc)

1. **Gravar Pi OS Lite (64-bit)** no cartão (Raspberry Pi Imager). Dá para
   pré-configurar usuário/senha/Wi-Fi/SSH no próprio Imager (ícone de engrenagem).

2. **Instalar dependências** no Pi:
   ```bash
   sudo apt update
   sudo apt install -y xserver-xorg xinit python3-tk espeak-ng python3-pip unclutter
   ```

   > ⚠️ É `espeak-ng`, **não** `espeak`. O `espeak` clássico é incompatível com o
   > driver do `pyttsx3` (falha com `SetVoiceByName ... gmw/en`) e o TTS não sobe.

3. **Copiar o código** para o Pi (ex.: `/home/pi/calculadora/`, contendo `software/`)
   e instalar as libs Python com as versões fixadas do projeto:
   ```bash
   cd /home/pi/calculadora
   pip3 install --break-system-packages -r software/requirements.txt
   ```

4. **Autologin no console:** `sudo raspi-config` → *System Options* →
   *Boot / Auto Login* → **Console Autologin**.

5. **Criar o lançador do kiosk** em `/home/pi/.xinitrc`:
   ```bash
   xset s off -dpms          # nunca apagar/desligar a tela
   unclutter -idle 0 &       # esconder o cursor do mouse
   cd /home/pi/calculadora
   while true; do            # reinicia o app se ele fechar/cair
       python3 -m software.app
   done
   ```

6. **Disparar o X no login** adicionando ao final de `/home/pi/.bash_profile`:
   ```bash
   [ "$(tty)" = "/dev/tty1" ] && startx
   ```

7. **Reiniciar:**
   ```bash
   sudo reboot
   ```

Ao voltar, o Pi arranca direto na calculadora.

---

## Ajustes recomendados de appliance

- **Sem blanking de tela / cursor escondido / auto-restart:** já embutidos no
  `~/.xinitrc` do passo 5.
- **Áudio:** garantir a saída correta (`raspi-config` → *System Options* → *Audio*)
  para o TTS pt-BR sair no dispositivo certo (HDMI vs. jack).
- **HDMI/LCD:** a lógica de `DisplaySelector` (RF-02) ainda é stub; o kiosk
  desenha na saída ativa do X. Detecção/troca automática é trabalho à parte.

> **Alternativa via systemd:** se preferir gerenciar por serviço, é possível, mas
> exige um launcher separado **e** `allowed_users=anybody` em
> `/etc/X11/Xwrapper.config` para o systemd conseguir iniciar o X. O método
> `~/.xinitrc` acima evita isso e é o padrão consagrado de kiosk no Pi.

---

## Gerar uma imagem distribuível (.img)

Depois de tudo configurado e validado:

1. Desligar o Pi, remover o cartão, inserir no PC.
2. Clonar para arquivo (Linux):
   ```bash
   sudo dd if=/dev/sdX of=calculadora.img bs=4M status=progress
   ```
   (ou usar *Pi Imager* / *rpi-clone*).
3. Opcional: encolher a imagem com `pishrink` para caber em cartões menores.

> **Não commitar `.img` no Git** (regra do [system/README.md](../README.md)):
> versione apenas os scripts/config deste diretório e documente como gerar.

---

## Criar a imagem do zero (reprodutível)

Clonar o cartão (seção acima) é rápido, mas depende de você ter configurado o Pi
"na mão". Para uma imagem **reprodutível a partir do zero** — que qualquer pessoa
regenera só rodando um build — há duas vias:

| Via | O que gera | Esforço | Quando escolher |
| --- | --- | --- | --- |
| **pi-gen** | Imagem baseada no Pi OS, montada por script | Médio | ✅ Reprodutível sem sair do ecossistema Pi OS |
| **Alpine** | Imagem Alpine mínima (musl) montada por script | Médio | ✅ Appliance enxuto e reprodutível; boot rápido sem o custo do Buildroot |
| **Buildroot** | Linux mínimo do zero (kernel + rootfs custom) | Alto | ⚠️ Só p/ boot ultrarrápido / appliance enxuto (RNF-06) |

### Via A — pi-gen (Pi OS montado por script)

`pi-gen` é a ferramenta oficial que constrói as imagens do Raspberry Pi OS. Você
adiciona um "estágio" próprio que instala o app e o kiosk — o resultado é um
`.img` gerado 100% por script, sem configuração manual.

1. Clonar e preparar:
   ```bash
   git clone https://github.com/RPi-Distro/pi-gen
   cd pi-gen
   ```
2. Criar um estágio `stage-calculadora/` com:
   - `00-packages` — lista de pacotes apt (`xserver-xorg xinit python3-tk espeak-ng unclutter`).
   - `01-run.sh` — copia a pasta `software/`, instala as libs Python
     (`pip3 install --break-system-packages -r software/requirements.txt`), grava o
     `~/.xinitrc` e o `~/.bash_profile` e habilita o autologin (os mesmos passos 3–6
     da seção kiosk, mas em script).
3. Definir `config` (nome da imagem, `TARGET_HOSTNAME`, usuário) e rodar:
   ```bash
   sudo ./build.sh
   ```
4. A imagem sai em `deploy/*.img` — pronta para gravar com o Pi Imager.

> Vantagem: o build é o "código" da imagem. Versione o estágio
> `stage-calculadora/` em `system/rpi-os/` (não o `.img`).

### Via C — Alpine (kiosk enxuto por script)

Imagem **Alpine Linux (aarch64)** montada 100% por script, já com o app e o kiosk
embutidos. Fica mais enxuta que o Pi OS e é bem mais rápida de montar que o
Buildroot (usa pacotes prontos: `python3`, `py3-tkinter`, `espeak-ng`, X mínimo).
Base fixada e reprodutível; roda no PC via `qemu-user`/binfmt (ou nativo no Pi).

Tudo vive em [../system/rpi-os/alpine/](../system/rpi-os/alpine/):

```bash
cd system/rpi-os/alpine
sudo ./build-alpine-img.sh          # gera calculadora-alpine-<ver>-aarch64.img
```

O script baixa+verifica o minirootfs oficial, instala os pacotes de `packages` +
kernel/firmware do Pi + as libs Python de `software/requirements.txt`, configura
o autologin/kiosk (mesmo padrão `~/.xinitrc` desta doc, adaptado ao OpenRC/BusyBox
do Alpine) e empacota a imagem. Detalhes de gravação e a **checklist de validação
no hardware** estão no [README da pasta](../system/rpi-os/alpine/README.md).

> Como nas demais vias: versione só os scripts/config de `system/rpi-os/alpine/`,
> **nunca** o `.img`.

### Via B — Buildroot (Linux do zero)

Constrói um sistema mínimo só com o necessário para o app. Boot em segundos, mas
é a via mais trabalhosa — Tkinter, X e TTS precisam ser habilitados manualmente e
alguns pacotes Python não existem prontos no Buildroot. Os artefatos reutilizáveis
(defconfig, overlay) ficam em [system/buildroot/](../buildroot/).

1. Obter o Buildroot e partir do defconfig do Pi 4 (64-bit):
   ```bash
   git clone https://gitlab.com/buildroot.org/buildroot
   cd buildroot
   make raspberrypi4_64_defconfig
   ```
2. `make menuconfig` e habilitar:
   - **Toolchain:** headers/compilador compatíveis.
   - **Target packages → Interpreter languages:** `python3` + a opção **tkinter**.
   - **Graphic libraries → X.org:** servidor X mínimo (xserver + xinit).
   - **Audio/misc:** `espeak-ng` (para o TTS; o `espeak` clássico não serve ao pyttsx3).
   - **System:** init (systemd **ou** BusyBox) e autologin.
3. **App + dependências Python:** `ttkbootstrap` e `pyttsx3` não são pacotes
   nativos do Buildroot. Opções:
   - criar um *package* Buildroot para cada um, **ou**
   - usar um **rootfs overlay** (`system/buildroot/overlay/`) com o `software/` e
     as libs Python já instaladas, mais um script de init que executa
     `startx python3 -m software.app`.
4. Construir a imagem:
   ```bash
   make
   ```
   O resultado (`output/images/sdcard.img`) já é a imagem final.
5. Gravar no cartão com `dd` (mesmo comando da seção `.img`).

> **Honestidade de prazo:** para o TCC, comece pela **Via A (pi-gen)** ou pelo
> kiosk simples. O Buildroot só compensa se boot ultrarrápido for um **resultado
> a demonstrar** — o cross-build de Tkinter + X + TTS consome tempo real.

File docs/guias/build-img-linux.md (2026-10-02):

# Rodar a calculadora como sistema embarcado (kiosk) no Raspberry Pi 4B

Objetivo: ao **ligar o Pi, ele arranca direto no aplicativo** da calculadora —
sem mostrar o SO, desktop ou terminal. Referência: [PRD.md](../produto/PRD.md) §12
(SO/arranque) e RNF-06 (boot rápido).

---

## Duas decisões distintas

1. **Como o app arranca sozinho (modo kiosk)** — é o trabalho de verdade;
   funciona igual em qualquer base de SO.
2. **Como empacotar/distribuir** — imagem Linux pronta vs instalar no Pi OS.
   É só "como entregar", não muda o comportamento.

---

## Opções de empacotamento

| Abordagem | Boot | Esforço | Recomendação |
| --- | ---- | --- | --- |
| **Pi OS Lite + kiosk** | ~15–25 s | Baixo | ✅ Começar por aqui |
| **Alpine (`system/rpi-os/alpine/`)** | rápido (enxuto) | Médio | ✅ Imagem por script, kiosk embutido; alternativa leve ao Buildroot |
| **Buildroot** (`system/buildroot/`) | ~3–8 s | Alto | ⚠️ Só se precisar provar boot ultrarrápido (RNF-06) |
| **Docker no Pi** | Lento | Médio | ❌ Não usar no produto (bom só p/ testar no PC) |

> "Gerar uma imagem que tenha ela" **não** exige Buildroot: configure o Pi OS
> Lite uma vez, valide, e **clone o cartão para um `.img`** (ver abaixo). Isso já
> é uma imagem Linux com o app embutido, reprodutível e sem a dor do Buildroot.
>
> **Docker não é forma de embarcar** GUI no aparelho final — foi útil apenas
> para desenvolvimento/teste no PC.

---

## Como o kiosk funciona (Pi OS Lite)

O app é Tkinter, então precisa de um X11 mínimo — mas **sem desktop**, só o app:

```
Liga o Pi
  → Autologin no console (raspi-config → Boot → Console Autologin)
  → ~/.bash_profile dispara:  startx
  → ~/.xinitrc prepara a tela e executa:  python3 -m software.app
  → Só a janela da calculadora na tela (sem menu, sem barra, sem cursor)
```

O `.xinitrc` também **reinicia o app se ele cair** (laço `while true`), fazendo o
papel de um `Restart=always` sem a complicação de iniciar o X a partir de um
serviço systemd (que exige mexer no `Xwrapper.config`).

---

## Passo a passo (Pi OS Lite + kiosk via ~/.xinitrc)

1. **Gravar Pi OS Lite (64-bit)** no cartão (Raspberry Pi Imager). Dá para
   pré-configurar usuário/senha/Wi-Fi/SSH no próprio Imager (ícone de engrenagem).

2. **Instalar dependências** no Pi:
   ```bash
   sudo apt update
   sudo apt install -y xserver-xorg xinit python3-tk espeak-ng alsa-utils python3-pip unclutter
   ```

   > ⚠️ É `espeak-ng`, **não** `espeak`. O `espeak-ng` é o **fonemizador** do Piper
   > e o motor de **fallback** (WRN-011); a voz principal é a neural `cadu`. O
   > `alsa-utils` fornece o `aplay`, que reproduz o PCM.

   Baixe a voz neural cadu para o caminho padrão (uma vez; o dispositivo é offline):
   ```bash
   sudo scripts/download-piper-voice.sh /opt/piper/voices
   ```

3. **Copiar o código** para o Pi (ex.: `/home/pi/calculadora/`, contendo `software/`)
   e instalar as libs Python com as versões fixadas do projeto:
   ```bash
   cd /home/pi/calculadora
   pip3 install --break-system-packages -r software/requirements.txt
   ```

4. **Autologin no console:** `sudo raspi-config` → *System Options* →
   *Boot / Auto Login* → **Console Autologin**.

5. **Criar o lançador do kiosk** em `/home/pi/.xinitrc`:
   ```bash
   xset s off -dpms          # nunca apagar/desligar a tela
   unclutter -idle 0 &       # esconder o cursor do mouse
   cd /home/pi/calculadora
   while true; do            # reinicia o app se ele fechar/cair
       python3 -m software.app
   done
   ```

6. **Disparar o X no login** adicionando ao final de `/home/pi/.bash_profile`:
   ```bash
   [ "$(tty)" = "/dev/tty1" ] && startx
   ```

7. **Reiniciar:**
   ```bash
   sudo reboot
   ```

Ao voltar, o Pi arranca direto na calculadora.

---

## Ajustes recomendados de appliance

- **Sem blanking de tela / cursor escondido / auto-restart:** já embutidos no
  `~/.xinitrc` do passo 5.
- **Áudio:** garantir a saída correta (`raspi-config` → *System Options* → *Audio*)
  para o TTS pt-BR sair no dispositivo certo (HDMI vs. jack).
- **HDMI/LCD:** a lógica de `DisplaySelector` (RF-02) ainda é stub; o kiosk
  desenha na saída ativa do X. Detecção/troca automática é trabalho à parte.

> **Alternativa via systemd:** se preferir gerenciar por serviço, é possível, mas
> exige um launcher separado **e** `allowed_users=anybody` em
> `/etc/X11/Xwrapper.config` para o systemd conseguir iniciar o X. O método
> `~/.xinitrc` acima evita isso e é o padrão consagrado de kiosk no Pi.

---

## Gerar uma imagem distribuível (.img)

Depois de tudo configurado e validado:

1. Desligar o Pi, remover o cartão, inserir no PC.
2. Clonar para arquivo (Linux):
   ```bash
   sudo dd if=/dev/sdX of=calculadora.img bs=4M status=progress
   ```
   (ou usar *Pi Imager* / *rpi-clone*).
3. Opcional: encolher a imagem com `pishrink` para caber em cartões menores.

> **Não commitar `.img` no Git** (regra do [system/README.md](../README.md)):
> versione apenas os scripts/config deste diretório e documente como gerar.

---

## Criar a imagem do zero (reprodutível)

Clonar o cartão (seção acima) é rápido, mas depende de você ter configurado o Pi
"na mão". Para uma imagem **reprodutível a partir do zero** — que qualquer pessoa
regenera só rodando um build — há duas vias:

| Via | O que gera | Esforço | Quando escolher |
| --- | --- | --- | --- |
| **pi-gen** | Imagem baseada no Pi OS, montada por script | Médio | ✅ Reprodutível sem sair do ecossistema Pi OS |
| **Alpine** | Imagem Alpine mínima (musl) montada por script | Médio | ✅ Appliance enxuto e reprodutível; boot rápido sem o custo do Buildroot |
| **Buildroot** | Linux mínimo do zero (kernel + rootfs custom) | Alto | ⚠️ Só p/ boot ultrarrápido / appliance enxuto (RNF-06) |

### Via A — pi-gen (Pi OS montado por script)

`pi-gen` é a ferramenta oficial que constrói as imagens do Raspberry Pi OS. Você
adiciona um "estágio" próprio que instala o app e o kiosk — o resultado é um
`.img` gerado 100% por script, sem configuração manual.

1. Clonar e preparar:
   ```bash
   git clone https://github.com/RPi-Distro/pi-gen
   cd pi-gen
   ```
2. Criar um estágio `stage-calculadora/` com:
   - `00-packages` — lista de pacotes apt (`xserver-xorg xinit python3-tk espeak-ng alsa-utils unclutter`).
   - `01-run.sh` — copia a pasta `software/`, instala as libs Python
     (`pip3 install --break-system-packages -r software/requirements.txt`, que puxa o
     `piper-tts`/`onnxruntime` em glibc), baixa a voz cadu
     (`scripts/download-piper-voice.sh /opt/piper/voices`), grava o `~/.xinitrc` e o
     `~/.bash_profile` e habilita o autologin (os mesmos passos 3–6 da seção kiosk,
     mas em script).
3. Definir `config` (nome da imagem, `TARGET_HOSTNAME`, usuário) e rodar:
   ```bash
   sudo ./build.sh
   ```
4. A imagem sai em `deploy/*.img` — pronta para gravar com o Pi Imager.

> Vantagem: o build é o "código" da imagem. Versione o estágio
> `stage-calculadora/` em `system/rpi-os/` (não o `.img`).

### Via C — Alpine (kiosk enxuto por script)

Imagem **Alpine Linux (aarch64)** montada 100% por script, já com o app e o kiosk
embutidos. Fica mais enxuta que o Pi OS e é bem mais rápida de montar que o
Buildroot (usa pacotes prontos: `python3`, `py3-tkinter`, `py3-onnxruntime`,
`espeak-ng`, X mínimo; o Piper vem por wheel + a voz cadu baixada no build).
Base fixada e reprodutível; roda no PC via `qemu-user`/binfmt (ou nativo no Pi).

Tudo vive em [../system/rpi-os/alpine/](../../system/rpi-os/alpine/):

```bash
cd system/rpi-os/alpine
sudo ./build-alpine-img.sh          # gera calculadora-alpine-<ver>-aarch64.img
```

O script baixa+verifica o minirootfs oficial, instala os pacotes de `packages` +
kernel/firmware do Pi + as libs Python de `software/requirements.txt`, configura
o autologin/kiosk (mesmo padrão `~/.xinitrc` desta doc, adaptado ao OpenRC/BusyBox
do Alpine) e empacota a imagem. Detalhes de gravação e a **checklist de validação
no hardware** estão no [README da pasta](../../system/rpi-os/alpine/README.md).

> Como nas demais vias: versione só os scripts/config de `system/rpi-os/alpine/`,
> **nunca** o `.img`.

### Via B — Buildroot (Linux do zero)

Constrói um sistema mínimo só com o necessário para o app. Boot em segundos, mas
é a via mais trabalhosa — Tkinter, X e TTS precisam ser habilitados manualmente e
alguns pacotes Python não existem prontos no Buildroot. Os artefatos reutilizáveis
(defconfig, overlay) ficam em [system/buildroot/](../../system/buildroot/).

1. Obter o Buildroot e partir do defconfig do Pi 4 (64-bit):
   ```bash
   git clone https://gitlab.com/buildroot.org/buildroot
   cd buildroot
   make raspberrypi4_64_defconfig
   ```
2. `make menuconfig` e habilitar:
   - **Toolchain:** headers/compilador compatíveis.
   - **Target packages → Interpreter languages:** `python3` + a opção **tkinter**.
   - **Graphic libraries → X.org:** servidor X mínimo (xserver + xinit).
   - **Audio/misc:** `espeak-ng` (fonemizador do Piper + fallback), `alsa-utils`
     (`aplay`) e `onnxruntime` (runtime do Piper). A voz principal é a neural cadu
     (Piper), instalada por wheel + modelo baixado no build.
   - **System:** init (systemd **ou** BusyBox) e autologin.
3. **App + dependências Python:** `ttkbootstrap` e `piper-tts` não são pacotes
   nativos do Buildroot. Opções:
   - criar um *package* Buildroot para cada um, **ou**
   - usar um **rootfs overlay** (`system/buildroot/overlay/`) com o `software/` e
     as libs Python já instaladas, mais um script de init que executa
     `startx python3 -m software.app`.
4. Construir a imagem:
   ```bash
   make
   ```
   O resultado (`output/images/sdcard.img`) já é a imagem final.
5. Gravar no cartão com `dd` (mesmo comando da seção `.img`).

> **Honestidade de prazo:** para o TCC, comece pela **Via A (pi-gen)** ou pelo
> kiosk simples. O Buildroot só compensa se boot ultrarrápido for um **resultado
> a demonstrar** — o cross-build de Tkinter + X + TTS consome tempo real.

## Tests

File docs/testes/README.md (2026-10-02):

# Testes — resultados e roteiros

O que já foi **validado** e o que ainda precisa ser executado com pessoas. Os testes automatizados vivem em [`../../software/tests/`](../../software/tests/); esta pasta guarda os **registos** e os roteiros manuais.

| Documento | Tipo | Estado |
| --- | ---- | --- |
| [arithmetic_tests_2026-05-17.md](arithmetic_tests_2026-05-17.md) | Log de execução — aritmética e funções científicas (15 suítes, robustez e precisão) | Executado em **2026-05-17**: 15/15 sucesso |
| [testes_logaritmicos_renumerado.md](testes_logaritmicos_renumerado.md) | Casos esperados de logaritmos (55 casos: base, mudança de base, precisão, performance) | Conferido |
| [usability_test_script_accessibility.md](usability_test_script_accessibility.md) | **Roteiro** de usabilidade com foco em acessibilidade | **Pendente** — a executar com usuários reais |

## Convenções

- Relatório de execução leva **data no nome** (`*_AAAA-MM-DD.md`) — é um registo histórico, não se reescreve.
- Roteiro (documento a executar) **não** leva data: é reutilizado a cada rodada, e os achados de cada rodada entram na seção final.
- Achado que vira trabalho: abrir task em [../desenvolvimento/Sprints.md](../desenvolvimento/Sprints.md) ou proposta em [`../../openspec/changes/`](../../openspec/changes/).

## Relacionado

- Requisitos que estes testes verificam: [../produto/PRD.md](../produto/PRD.md) §5 (funções) e §13 (códigos de erro)
- Suíte automatizada: `make check`

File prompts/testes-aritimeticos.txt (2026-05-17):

Objetivo

Realizar testes aritméticos para todas as funções disponíveis na calculadora, garantindo que o motor de cálculo esteja retornando resultados corretos e consistentes.

Etapas
Criar uma lista de testes contendo:
a operação matemática a ser executada;
o resultado esperado da operação.
Executar todos os cálculos utilizando o motor de cálculo da aplicação.
Comparar o resultado obtido com o resultado esperado.
Validar e registrar o status de cada teste:
✅ Sucesso — resultado correto;
⚠️ Divergência — diferença aceitável por arredondamento;
❌ Falha — resultado incorreto;
🚫 Erro esperado — operação inválida tratada corretamente.
Escopo dos Testes

Os testes devem abranger todas as funcionalidades aritméticas disponíveis, incluindo:

Soma
Subtração
Multiplicação
Divisão
Potenciação
Radiciação
Porcentagem
Operações com números negativos
Operações com casas decimais
Prioridade de operadores
Expressões com parênteses
Funções logarítmicas
Logaritmo decimal (log)
Logaritmo natural (ln)
Logaritmo em bases variáveis
Funções trigonométricas
Seno (sin)
Cosseno (cos)
Tangente (tan)
Funções trigonométricas inversas
Casos especiais e limites numéricos
Tratamento de erros matemáticos
Resultado Esperado

Ao final da execução, todos os cálculos devem produzir resultados compatíveis com os valores esperados, validando o funcionamento correto do motor de cálculo da calculadora.

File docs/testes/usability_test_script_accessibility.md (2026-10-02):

# Roteiro de teste de usabilidade — acessibilidade

**Contexto:** change `accessibility-improvements` (`openspec/changes/accessibility-improvements/`).
**Objetivo:** validar com usuários reais o que a implementação e os testes automatizados não conseguem confirmar sozinhos — clareza do áudio, contraste percebido, navegação sem mouse e ausência de fricção nos fluxos.

Este documento é um roteiro a ser **executado pela equipe** com usuários reais (idealmente incluindo pessoas com cegueira total e com baixa visão, conforme as personas do [PRD.md](../produto/PRD.md) §4). Os achados devem ser registrados na seção final e realimentar novas propostas/specs.

---

## Perfil dos participantes sugeridos

- Ao menos 1 pessoa com cegueira total (uso apoiado só em áudio).
- Ao menos 1 pessoa com baixa visão (ex.: ~50%, conforme PRD §4).
- Opcional: 1 pessoa sem deficiência visual, para comparação de baseline.

## Ambiente

- Rodar via Docker local ([docker-compose.yml](../../docker-compose.yml)) ou diretamente com `python -m software.app`.
- Fones de ouvido disponíveis (uso previsto no PRD §7.3).

---

## Roteiro de tarefas

Para cada tarefa, observar: **tempo até concluir**, **erros/hesitações**, **se o áudio foi suficiente para concluir sem olhar a tela**.

1. **Operação básica:** calcular `12 + 8` e ouvir o resultado.
2. **Função científica:** calcular `√(64)` e conferir se o valor falado e exibido fazem sentido.
3. **Erro proposital:** tentar `10 / 0` — o aviso falado explica o problema? O texto na tela usa a mesma mensagem?
4. **Aviso (não passa de erro rígido):** pressionar `Ans` sem nenhum cálculo anterior — confirmar que é anunciado como "Aviso", não "Erro".
5. **Repetir última resposta:** após um cálculo, usar Shift+`=` (ou Ctrl+`=`) e confirmar que a resposta é reanunciada sem precisar recalcular.
6. **Navegação só por teclado:** repetir as tarefas 1–5 sem tocar no mouse, usando os atalhos documentados em `software/hw_platform/keyboard.py`.
7. **Modificadores:** ativar Shift e Ctrl e conferir se o estado é percebido (visual e sonoro) antes de pressionar a função.
8. **Histórico:** abrir o histórico de operações e confirmar que a abertura é anunciada.
9. **Alternância Graus/Radianos:** trocar o modo e confirmar o anúncio correspondente.
10. **Leitura geral da tela:** para o participante com baixa visão, perguntar se o contraste e o tamanho do texto são suficientes em uso normal (sem ampliação extra).

---

## Perguntas pós-teste

- O que você faria diferente se estivesse usando a calculadora sozinho(a), sem apoio?
- Alguma mensagem falada foi confusa ou longa demais?
- Algum botão ficou "sem resposta" (nem visual nem sonora) em algum momento?
- Você conseguiria operar a calculadora inteira sem tocar na tela/mouse?

---

## Achados (preencher após as sessões)

| Data | Participante (perfil) | Tarefa | Achado | Prioridade | Ação sugerida |
| ---- | --- | --- | --- | --- | --- |
| _(pendente)_ | | | | | |

> Ao preencher esta tabela, considere abrir uma nova proposta OpenSpec (`/opsx:propose`) para achados que exigam mudança de comportamento, em vez de editar o change já arquivado.

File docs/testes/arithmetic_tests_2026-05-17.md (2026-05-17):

# Log de Resultados — Testes Aritméticos e Científicos
**Data:** 2026-05-17
**Relator:** Antigravity (IA)
**Contexto:** Validação de Robustez e Precisão (Alta Performance)

## Resumo de Status
- **Total de testes:** 15 suítes (cobertura total do PRD + Robustez)
- **Sucesso:** 15
- **Falhas:** 0
- **Divergências:** 0 (Ajuste de epsilon para 1e-9)

---

## Detalhamento por Categoria

### 1. Robustez e Precisão
| Operação | Resultado | Status | Notas |
| :--- | :--- | :--- | :--- |
| `0.1 + 0.2` | `0.3` | ✅ Sucesso | Epsilon 1e-9 validado |
| `1 / 3 * 3` | `1.0` | ✅ Sucesso | Precisão de float64 |
| `999999.999999 - ...` | `0.000001` | ✅ Sucesso | Cancelamento numérico testado |

### 2. Associatividade e Ordem
| Operação | Resultado | Status | Notas |
| :--- | :--- | :--- | :--- |
| `10 - 3 - 2` | `5` | ✅ Sucesso | Associatividade à esquerda |
| `100 / 10 / 2` | `5` | ✅ Sucesso | Associatividade à esquerda |
| `2^3^2` | `512` | ✅ Sucesso | Associatividade à direita (`2^(3^2)`) |
| `-3^2` | `-9` | ✅ Sucesso | Precedência de potência (standard math) |

### 3. Identidades Matemáticas (Validação Forte)
| Operação | Resultado | Status | Notas |
| :--- | :--- | :--- | :--- |
| `sin(x)^2 + cos(x)^2`| `1.0` | ✅ Sucesso | Identidade Pitagórica |
| `log(2*5)` vs `log(2)+log(5)`| Equivalente | ✅ Sucesso | Propriedade do Produto |
| `ln(e^x)` | `x` | ✅ Sucesso | Consistência Log/Exp |
| `e^ln(x)` | `x` | ✅ Sucesso | Identidade Eperiana |

### 4. Stress de Parser e UX
| Entrada / Expressão | Resultado | Status | Notas |
| :--- | :--- | :--- | :--- |
| `((((((2+3))))))` | `5` | ✅ Sucesso | Profundidade de parênteses |
| `sin(cos(tan(30)))` | `~0.51` | ✅ Sucesso | Funções aninhadas |
| `SIN(30) + 2 × 2` | `4.5` | ✅ Sucesso | Case-insensitive e símbolos UTF-8 |
| `2++2` | `4` | ✅ Sucesso | Normalização de operadores duplos |

### 5. Erros Agressivos
| Expressão | Resultado | Status | Notas |
| :--- | :--- | :--- | :--- |
| `()` | `ERR-007` | 🚫 Erro esperado | Expressão vazia |
| `(2+3` | `ERR-007` | 🚫 Erro esperado | Parêntese não fechado |
| `sqrt(-1)` | `ERR-002` | 🚫 Erro esperado | Domínio matemático (Real only) |
| `1/0 + 5` | `ERR-001` | 🚫 Erro esperado | Divisão por zero em expressão |

---
**Assinatura:** 
*Validado via `software/tests/test_arithmetic.py` em 2026-05-17.*

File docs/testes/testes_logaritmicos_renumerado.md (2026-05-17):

# Lista de Cálculos Logarítmicos com Resultados Esperados

## Logaritmos Básicos

1. `log10(100) = 2` - ✅
2. `log10(1000) = 3` - ✅
3. `log2(8) = 3` - ✅
4. `log2(1024) = 10` - ✅
5. `log5(125) = 3` - ✅
6. `log3(81) = 4` - ✅
7. `ln(e) = 1` - ✅
8. `ln(e^5) = 5` - ✅
9. `log10(0.1) = -1` - ✅
10. `log2(0.5) = -1` - ✅

\---

## Mudança de Base

11. `log4(64) = 3` - ✅
12. `log7(49) = 2` - ✅
13. `log9(27) = 1.5` - ✅
14. `log16(2) = 0.25` - ✅
15. `log25(5) = 0.5` - ✅

\---

## Propriedades dos Logaritmos

16. `log(10 \* 100) = 3` - ✅
17. `log(1000 / 10) = 2` - ✅
18. `log(10^5) = 5` - ✅
19. `log(2^8) ≈ 2.40824` - ✅
20. `log(50) + log(2) = 2` - ✅
21. `log(100) - log(10) = 1` - ✅
22. `2 \* log(10) = 2` - ✅
23. `log(sqrt(100)) = 1` - ✅

\---

## Casos com Resultado Decimal

24. `log10(7) ≈ 0.84510` - ✅
25. `log2(3) ≈ 1.58496` - ✅
26. `ln(2) ≈ 0.69315` - ✅
27. `log5(12) ≈ 1.54396` - ✅
28. `log7(100) ≈ 2.36658` - ✅

\---

## Casos Extremos / Validação

29. `log10(1) = 0` - ✅
30. `ln(1) = 0` - ✅
31. `log2(1) = 0` - ✅
32. `log10(0) -> erro esperado` - ✅
33. `log10(-5) -> erro esperado` - ✅
34. `log1(10) -> base inválida` - ✅
35. `log-2(8) -> base inválida` - ✅

\---

## Combinações Avançadas

36. `log2(32) + log2(4) = 7` - ✅
37. `log10(1000) - log10(10) = 2` - ✅
38. `log(1000) / log(10) = 3` - ✅
39. `ln(e^8) - ln(e^3) = 5` - ✅
40. `log3(27 \* 9) = 5` - ✅

\---

## Testes de Precisão

41. `ln(1.0001) ≈ 9.9999500033*10^-5` - ✅
42. `log10(999999) ≈ 5.999999566` - ✅
43. `log2(2048) = 11` - ✅
44. `log10(3.14159265) ≈ 0.4971498722` - ✅
45. `ln(123456789) ≈ 18.63140177` - ✅

\---

## Testes Mistos

46. `sqrt(log10(10000)) = 2` - ✅
47. `(log2(64))^2 = 36` - ✅
48. `log10(10^8) = 8` - ✅
49. `ln(sqrt(e^6)) = 3` - ✅
50. `log5(625) * 2 = 8` - ✅

\---

## Casos para Performance

51. `log2(2^100) = 100` - ✅
52. `ln(e^50) = 50` - ✅
53. `log10(10^20) = 20` - ✅
54. `log3(3^15) = 15` - ✅
55. `log7(7^30) = 30` - ✅

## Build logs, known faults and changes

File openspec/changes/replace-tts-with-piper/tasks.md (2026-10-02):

## 1. Preparação e decisão

- [ ] 1.1 Medir a **baseline** no Pi: latência entre soltar a tecla e o som com o espeak-ng/pyttsx3 atual, para o "sete", para um resultado longo e para um erro §13. Registrar em `docs/testes/`. Verificar: números anotados para comparação posterior.
- [ ] 1.2 Confirmar no rootfs de build que `py3-onnxruntime` (community v3.24, aarch64) resolve para Python 3.14/musl e mede ~120 MB de closure. Verificar: `apk add --simulate py3-onnxruntime` no chroot lista os pacotes esperados sem erro.
- [x] 1.3 Registrar a decisão no OpenSpec/PRD antes de codar (esta mudança). Verificar: `proposal.md`, `design.md`, `specs/speech-engine/spec.md` e `specs/rpi-boot-image/spec.md` presentes e coerentes.

## 2. Protótipo no hardware (gate antes de codar o serviço)

- [ ] 2.1 Compilar um wheel `musl/aarch64` de `piper-tts` (tag fixa, via git — o sdist do PyPI é incompleto) num container `alpine:3.24` arm64 ou no próprio Pi, sobre `py3-onnxruntime`. Verificar: `pip install --no-deps <wheel>` e `python3 -c "import piper"` no Pi.
- [ ] 2.2 Rodar a voz `cadu` no Pi (Python 3.14) e sintetizar as frases reais: 38 nomes de tecla, dígitos, os 10 erros §13, avisos 012/013 e resultados longos. Verificar: WAVs gerados e audíveis; nenhuma palavra curta ("é", "pi", "mais") engolida — senão, avaliar pontuação/pausa.
- [ ] 2.3 Medir carga do modelo, latência por frase (tecla e resultado longo), pico de CPU, RAM residente e temperatura. Verificar: latência de tecla ≤ baseline (2.1) com cache; resultado longo dentro do aceitável do PRD; anotado em `docs/testes/`.
- [ ] 2.4 Teste de escuta da `cadu` com as frases reais (equipe). Verificar: inteligibilidade aprovada (PRD §8); se reprovada, reavaliar voz antes de prosseguir (fora do escopo desta mudança se trocar).
- [ ] 2.5 Definir o número de threads do ONNX no Pi 4 e se o cache é pré-aquecido no arranque ou sob demanda (design, Open Questions). Verificar: valores escolhidos com base em 2.3.

## 3. Serviço de voz residente (`software/accessibility/speech.py`)

- [x] 3.1 Criar o motor residente (import tardio de `piper`/`onnxruntime`): carga assíncrona do modelo `cadu`, `synthesize(text) -> bytes` (PCM S16LE mono) e threads do ONNX limitadas (D2). Verificar: `python -c "import software.accessibility.speech"` **sem** Piper instalado não falha (import tardio).
- [x] 3.2 Substituir a reprodução por um player raw `aplay -t raw -f S16_LE -c1 -r <sample_rate> -` pela stdin, com grupo de processo próprio e `terminate()` que mata o `aplay` (D3). Verificar: teste com `aplay` falso no PATH (memória `tts-fake-aplay-testing`) confirma o comando e o formato; `terminate()` encerra o player.
- [x] 3.3 Manter a fila, `_Generation` e a API `say`/`interrupt_and_say`/`stop` intactas, ligando o motor pela `process_factory`/`SpeakProcess` (D1). Verificar: os testes de fila e interrupção existentes passam com um motor injetado (sem Piper real).
- [x] 3.4 Implementar o cache de frases fixas, aquecido após a carga do modelo, e a reprodução por cache no `say` (D4). Verificar: teste mostra que uma frase do conjunto fixo não chama a síntese quando o cache está quente, e que um resultado numérico chama.
- [x] 3.5 Implementar o fallback `espeak-ng` + `WRN-011` (motor ausente, modelo ausente, ou durante a carga), sem bloquear a entrada (D6). Verificar: teste com Piper "indisponível" reproduz por espeak-ng, loga `WRN-011` uma vez, e a fila segue.
- [x] 3.6 Reescrever/retirar os testes específicos do driver pyttsx3 (`_EspeakLikeEngine`, `SpeakWaitsForPlaybackTest`) para o motor residente; adicionar testes de cache e fallback. Verificar: `python -m unittest software.tests.test_speech_service -v` passa sob **fork e forkserver** (memória `pi-python-forkserver`).

## 4. Dependências de desenvolvimento (Docker/CI/host)

- [x] 4.1 `software/requirements.txt`: remover `pyttsx3`; adicionar `piper-tts` com marcador de ambiente que não quebre o build musl (imagem usa o wheel pré-compilado). Verificar: `pip install -r requirements.txt` funciona no CI (glibc, Python 3.11).
- [x] 4.2 Script para baixar a voz `cadu` (`.onnx` + `.onnx.json`) com sha256, reutilizável por Docker e imagem. Verificar: script baixa e valida o hash; roda idempotente.
- [x] 4.3 `Dockerfile`, `docker-compose*.yml`, `Makefile`: remover dependência do `pyttsx3`, instalar `piper-tts` e a voz, manter a ponte de áudio para o host. Verificar: `make up` fala pela voz `cadu` no host Linux.
- [x] 4.4 Confirmar que `make check` e o CI passam **sem** Piper e **sem** áudio (import tardio, motor injetável). Verificar: `python -m unittest discover -s software/tests -v` verde no CI.

## 5. Imagem Alpine (`system/rpi-os/alpine/`)

- [x] 5.1 `packages`: adicionar `py3-onnxruntime` (community). Atualizar o comentário da seção de TTS (Piper + cadu; espeak-ng como fonemizador/fallback). Verificar: `test_image_packages.py` (parser) e o `apk add` no chroot incluem o pacote.
- [x] 5.2 `build-alpine-img.sh`: instalar o wheel do Piper com `--no-deps`, baixar e validar a voz `cadu` (sha256), remover os modelos de outras línguas do `piper-tts` (hebrew/tashkeel, ~25 MB) e o symlink `libespeak.so.1`. Verificar: rootfs contém `piper`, o `.onnx` da cadu e não contém o pyttsx3.
- [x] 5.3 Trocar o smoke de `pyttsx3.init()` por uma **síntese real** do Piper no chroot (Piper → PCM, sem placa de som). Verificar: o smoke gera PCM não-vazio sob qemu; falha cedo se o Piper não importar no 3.14.
- [x] 5.4 Atualizar o checklist de hardware do `system/rpi-os/alpine/README.md`: voz `cadu` anuncia offline, interrupção (RF-08) sem `Device busy`, `/tmp` sem sobras, latência e arranque. Verificar: itens presentes no checklist.

## 6. Validação no hardware e documentação

- [ ] 6.1 Gravar a imagem e validar no Pi: voz `cadu` offline; interrupção do `=` corta a fala sem sobrepor; sem `WRN-011` inesperado (Piper carregou); `/tmp` (tmpfs) sem acúmulo. Verificar: checklist do README marcado no aparelho.
- [ ] 6.2 Medir latência (tecla, resultado, erro) e tempo de arranque no hardware; comparar com a baseline (1.1). Verificar: números em `docs/testes/`; RNF-06 não regride de forma inaceitável.
- [x] 6.3 Atualizar PRD §12, `software/README.md`, `docs/guias/build-img-linux.md` e `openspec/config.yaml`: TTS passa a "Piper (voz cadu), espeak-ng como fonemizador/fallback"; remover as afirmações de que a voz é pyttsx3/espeak. Verificar: `grep -rn pyttsx3 software docs openspec` só aparece em contexto histórico/arquivado.
- [x] 6.4 Rodar a suíte completa e revisar o diff. Verificar: `python -m unittest discover -s software/tests -v` verde; nenhum consumidor de voz (`app.py`, fronts, `audio_only.py`, `video_watch.py`) alterado.
- [x] 6.5 Decidir (fora desta mudança) se o apk `espeak-ng` do sistema é removido depois da validação. Verificar: decisão registrada; se mantido, justificativa do fallback anotada.

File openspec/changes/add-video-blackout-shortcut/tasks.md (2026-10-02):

## 1. Mecânica: desligar todas as saídas no X

- [x] 1.1 Em `software/hw_platform/video_output.py`, criar `all_off(outputs)` que monta **uma única** chamada `xrandr --output <A> --off --output <B> --off` com os nomes resolvidos por `output_name()` (design D3), e devolve `bool`. Verificar: teste unitário confirma o `argv` exato com os dois nomes.
- [x] 1.2 Após o `xrandr`, reler `read_outputs()` e só devolver `True` quando **nenhuma** saída estiver ativa; divergência ou estado ilegível → `False` e `logger.warning` com o código `WRN-013`. Verificar: teste com releitura *mockada* mostrando saída ainda ativa devolve `False`.
- [x] 1.3 Tratar o caso de só o LCD estar presente no X como sucesso, sem erro pela ausência do monitor (spec: «Apenas o LCD conectado»). Verificar: teste com `read_outputs()` devolvendo uma só saída.
- [x] 1.4 Garantir degradação sem X: sem `DISPLAY` ou sem binário `xrandr`, `all_off()` devolve `False` sem levantar exceção, reusando `available()`/`missing_xrandr_on_x()`. Verificar: teste com `DISPLAY` removido do ambiente.
- [x] 1.5 Acrescentar os testes de 1.1–1.4 a `software/tests/test_video_output.py`, seguindo o padrão de *mock* de `subprocess.run` já usado no ficheiro. Verificar: `python -m unittest software.tests.test_video_output -v` passa **sem** servidor X.

## 2. Estado de sessão e frases partilhadas

- [x] 2.1 Criar `software/ui/shared/video_blackout.py` com um objeto de sessão mutável (sinalizador `active`, inicial `False`) e **sem** importar Tk (design D1, D5). Verificar: `python -c "import software.ui.shared.video_blackout"` corre sem `DISPLAY`.
- [x] 2.2 No mesmo módulo, definir as frases do `WRN-013` — apagado (nomeando a tecla `AC` como via de retorno), religado (nomeando o painel), e falha ao apagar — como constantes/funções, no padrão de `video_changed_speech()` em `video_watch.py`. Verificar: teste confirma que a frase de desligamento contém a tecla e o prefixo «Aviso 013».
- [x] 2.3 Implementar a função de *toggle* que recebe o estado de sessão e um aplicador de vídeo injetável, inverte o sinalizador **só** quando o aplicador confirma sucesso, e devolve a frase a anunciar (spec: «Falha ao apagar é anunciada e não altera o estado»). Verificar: teste com aplicador que falha deixa `active == False` e devolve a frase de falha.
- [x] 2.4 Implementar a regra de recuperação por `AC`: com `active == True`, reacende e limpa o sinalizador; com `active == False`, não chama o aplicador (spec: «AC inalterado com a tela acesa»). Verificar: teste com duplo contando chamadas ao aplicador — zero com a tela acesa.
- [x] 2.5 Criar `software/tests/test_video_blackout.py` com os casos de 2.2–2.4. Verificar: passa sem `DISPLAY`.

## 3. Integração no laço de fronts

- [x] 3.1 Em `software/app.py`, construir o estado de sessão **uma vez** em `run_mode()`, ao lado do `CalculatorState`, e passá-lo a `point_x_at()` e a `start_front()` (design D1). Verificar: `software/tests/test_entrypoint_dispatch.py` continua a passar.
- [x] 3.2 Alterar `point_x_at()` para, com `active == True`, chamar `video_output.all_off()` em vez de `activate()`; com `False`, manter o comportamento atual intacto (design D2). Verificar: teste novo com `video_output` *mockado* confirma qual das duas funções é chamada em cada estado.
- [x] 3.3 Expor o reacendimento como chamada a `point_x_at(mode_atual)`, para que reacender reexecute a prioridade do §7.2 sem memorizar o painel anterior (spec: «Reacendimento respeita a prioridade de painel»). Verificar: teste em que o seletor simulado muda de LCD para HDMI entre apagar e religar confirma `activate()` com o monitor como alvo.
- [x] 3.4 Confirmar que a entrega do RF-09 preserva o blackout: com `active == True`, uma troca de front leva `point_x_at()` a chamar `all_off()` para o front seguinte (spec: «Hotplug durante o blackout não reacende a tela»). Verificar: teste do laço `run_mode()` com dois fronts simulados em sequência.
- [x] 3.5 Confirmar que `--force-mode audio` e o `AudioOnlyCalculator` **não** recebem nem usam o estado de blackout. Verificar: teste de *dispatch* do modo áudio inalterado.

## 4. Tecla e ligação nos dois fronts

- [x] 4.1 Em `software/ui/shared/keypad.py`, dar à tecla `AC` a função secundária `BLACKOUT` (`("AC", "AC", "BLACKOUT", None)`), retirar a tecla `?` inexistente na matriz (vira espaço vazio) e acrescentar o nome falado em `SPOKEN_TOKEN_NAMES` (design D4). Verificar: teste confirma que `BLACKOUT` só é alcançável como secundária de `AC`, que nenhuma tecla `?` resta no catálogo, e que `BLACKOUT` não coincide com nenhum token do §5.
- [x] 4.2 Em `software/hw_platform/keyboard.py`, **não** acrescentar atalho próprio: o PC usa `Ctrl` e depois `Esc`, como a matriz. Verificar: teste confirma que nenhuma tecla de `KEY_MAP` produz `BLACKOUT`.
- [x] 4.3 Em `software/ui/hdmi/app.py`, atribuir `BLACKOUT` como `secondary` quando `AC` chega do teclado sem ele (mesmo tratamento do `Ans`/`HISTORY`), tratar o token `BLACKOUT` depois da resolução dos modificadores, e tratar o caso `AC` sozinho chamando o módulo de 2.x e anunciando por `speech.interrupt_and_say()`. Verificar: teste de GUI (sob Xvfb) com `Ctrl` seguido de `AC` pela via do teclado confirma o anúncio e a inversão do estado com aplicador *mockado*.
- [x] 4.4 Espelhar 4.3 em `software/ui/lcd/app.py`, mantendo os dois `_handle_token()` equivalentes. Verificar: o mesmo teste parametrizado pelos dois fronts.
- [x] 4.5 Garantir que `Ctrl` + `AC` **não** limpa a expressão nem entra nela, **consome** o `Ctrl` como qualquer função secundária, e que o modo «o que faz esta tecla?» (`Ctrl`+`Shift`) apenas **descreve** `AC` com a sua função secundária, sem apagar a tela. Verificar: testes da expressão intacta e do `Ctrl` consumido nos dois fronts, e teste com `Ctrl`+`Shift` ativos no HDMI confirmando descrição falada e estado de vídeo inalterado.
- [x] 4.6 Verificar o requisito «Calculadora permanece operável»: com `active == True`, digitar `2+2`, `=`, confirmar resultado anunciado e presença no histórico; religar e confirmar expressão, `Ans`, histórico e modo graus/radianos intactos. Verificar: teste de GUI de ponta a ponta com aplicador *mockado*.

## 5. Dimensionamento durante o blackout

- [x] 5.1 No front HDMI, quando o front é construído com `active == True`, dimensionar pela geometria preferida da saída-alvo em vez de `video_output.screen_size()`, caindo para o comportamento atual quando ilegível (design D7). Verificar: teste com `screen_size()` *mockado* a devolver tamanho degenerado confirma que a faixa de layout escolhida corresponde à saída-alvo.
- [x] 5.2 Confirmar que, com `active == False`, o dimensionamento é **exatamente** o atual. Verificar: `software/tests/test_window_geometry.py` e `test_hdmi_layout_wiring.py` passam sem alterações.

## 6. Documentação e registo do código

- [x] 6.1 Registar `WRN-013` na tabela do `docs/produto/PRD.md` §13 (P2, «Telas desligadas/religadas por comando»), com a frase falada, e acrescentar entrada no histórico de versões do PRD. Verificar: a linha existe entre `WRN-012` e `WRN-020`.
- [x] 6.2 Em `docs/guias/comandos-teclado.md`, retirar `?` da lista de teclas reservadas (§3; ela não existe na matriz), acrescentar `Ctrl` + `AC` às tabelas do teclado físico e `Ctrl` e depois `Esc` à do PC (com a nota do menu Iniciar no Windows), e documentar a recuperação por `AC`. Verificar: nenhuma menção residual a `?` como tecla nem a `v` como atalho.
- [x] 6.3 Em `system/rpi-os/alpine/README.md`, acrescentar à checklist de bring-up os itens da secção 7. Verificar: itens presentes na checklist.

## 7. Verificação no hardware (Raspberry Pi 4B)

- [ ] 7.1 Com só o LCD ligado, pressionar `Ctrl` e depois `AC`: o LCD apaga e o anúncio `WRN-013` é ouvido. Verificar: `xrandr --query` mostra a saída do LCD sem geometria ativa, e `~/calculadora.log` regista o sucesso.
- [ ] 7.2 **Hipótese crítica (design, Riscos):** com as telas apagadas, digitar `2+2=` e confirmar o resultado falado — prova de que as teclas continuam a chegar à janela Tk sem CRTC ativo. Se falhar, **parar** e reabrir o design antes de continuar.
- [ ] 7.3 Confirmar se o driver `modesetting` aceita desligar o último CRTC. Se recusar, confirmar que o anúncio é o de falha, que a tela permanece acesa, e registar o resultado no `README.md` da imagem.
- [ ] 7.4 Com LCD e monitor ligados, pressionar `Ctrl` + `AC`: as duas saídas apagam. Pressionar `Ctrl` + `AC` de novo: reacende **só** o monitor. Verificar por `xrandr --query`.
- [ ] 7.5 Com as telas apagadas, ligar o monitor externo, aguardar a entrega de front, e confirmar que **nenhum** painel acende; depois pressionar `AC` e confirmar que o monitor reacende com a expressão limpa.
- [ ] 7.6 Encerrar a calculadora com as telas apagadas e reiniciá-la: arranca acesa. Verificar visualmente.
- [ ] 7.7 Medir e registar se o LCD Waveshare corta a retroiluminação sem sinal ou mostra «sem sinal» iluminado (alimenta a Open Question de autonomia). Verificar: resultado registado no `README.md` da imagem.

## 8. Fecho

- [x] 8.1 Correr a suíte completa como o CI: `xvfb-run -a python -m unittest discover -s software/tests -t . -v`. Verificar: todos os testes passam, incluindo os pré-existentes.
- [x] 8.2 Validar a mudança: `openspec validate add-video-blackout-shortcut --strict`. Verificar: sem erros.

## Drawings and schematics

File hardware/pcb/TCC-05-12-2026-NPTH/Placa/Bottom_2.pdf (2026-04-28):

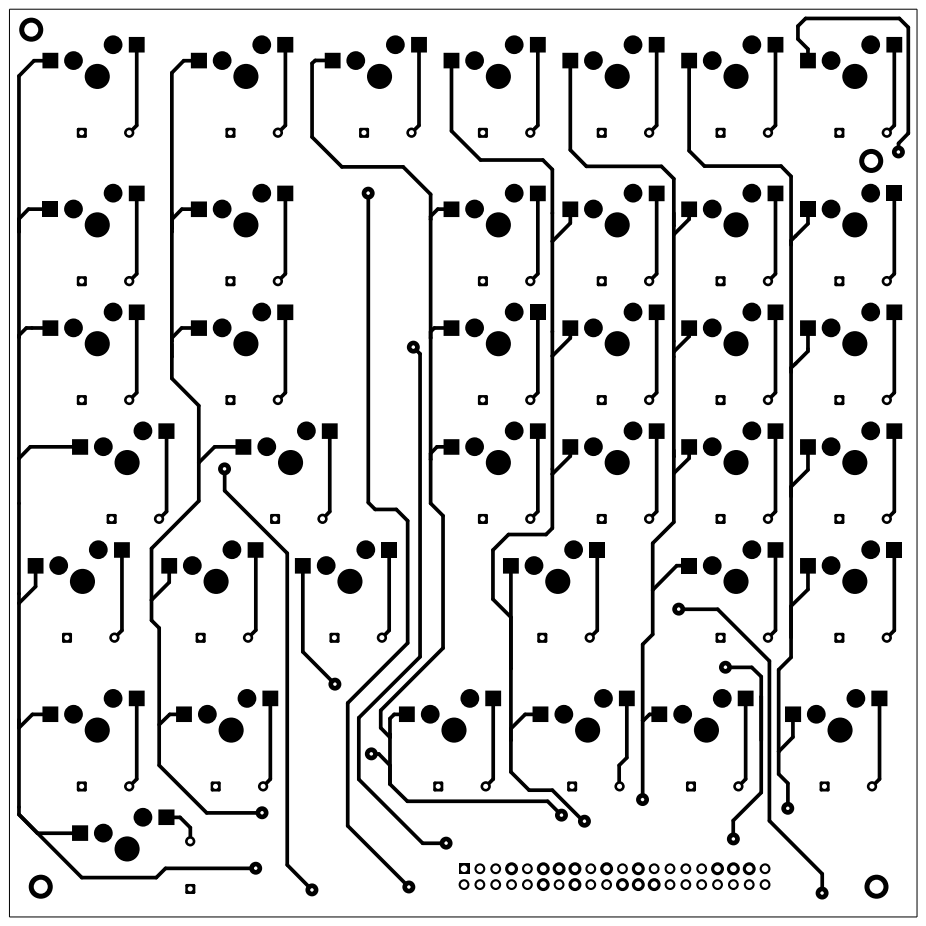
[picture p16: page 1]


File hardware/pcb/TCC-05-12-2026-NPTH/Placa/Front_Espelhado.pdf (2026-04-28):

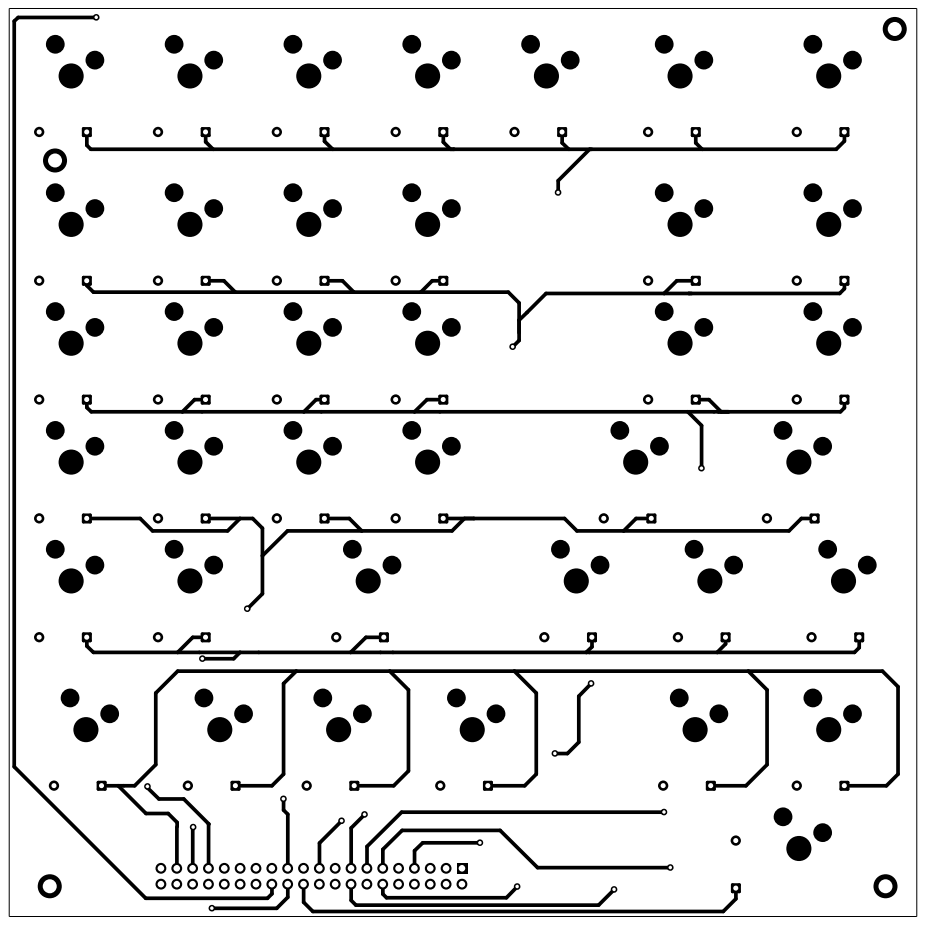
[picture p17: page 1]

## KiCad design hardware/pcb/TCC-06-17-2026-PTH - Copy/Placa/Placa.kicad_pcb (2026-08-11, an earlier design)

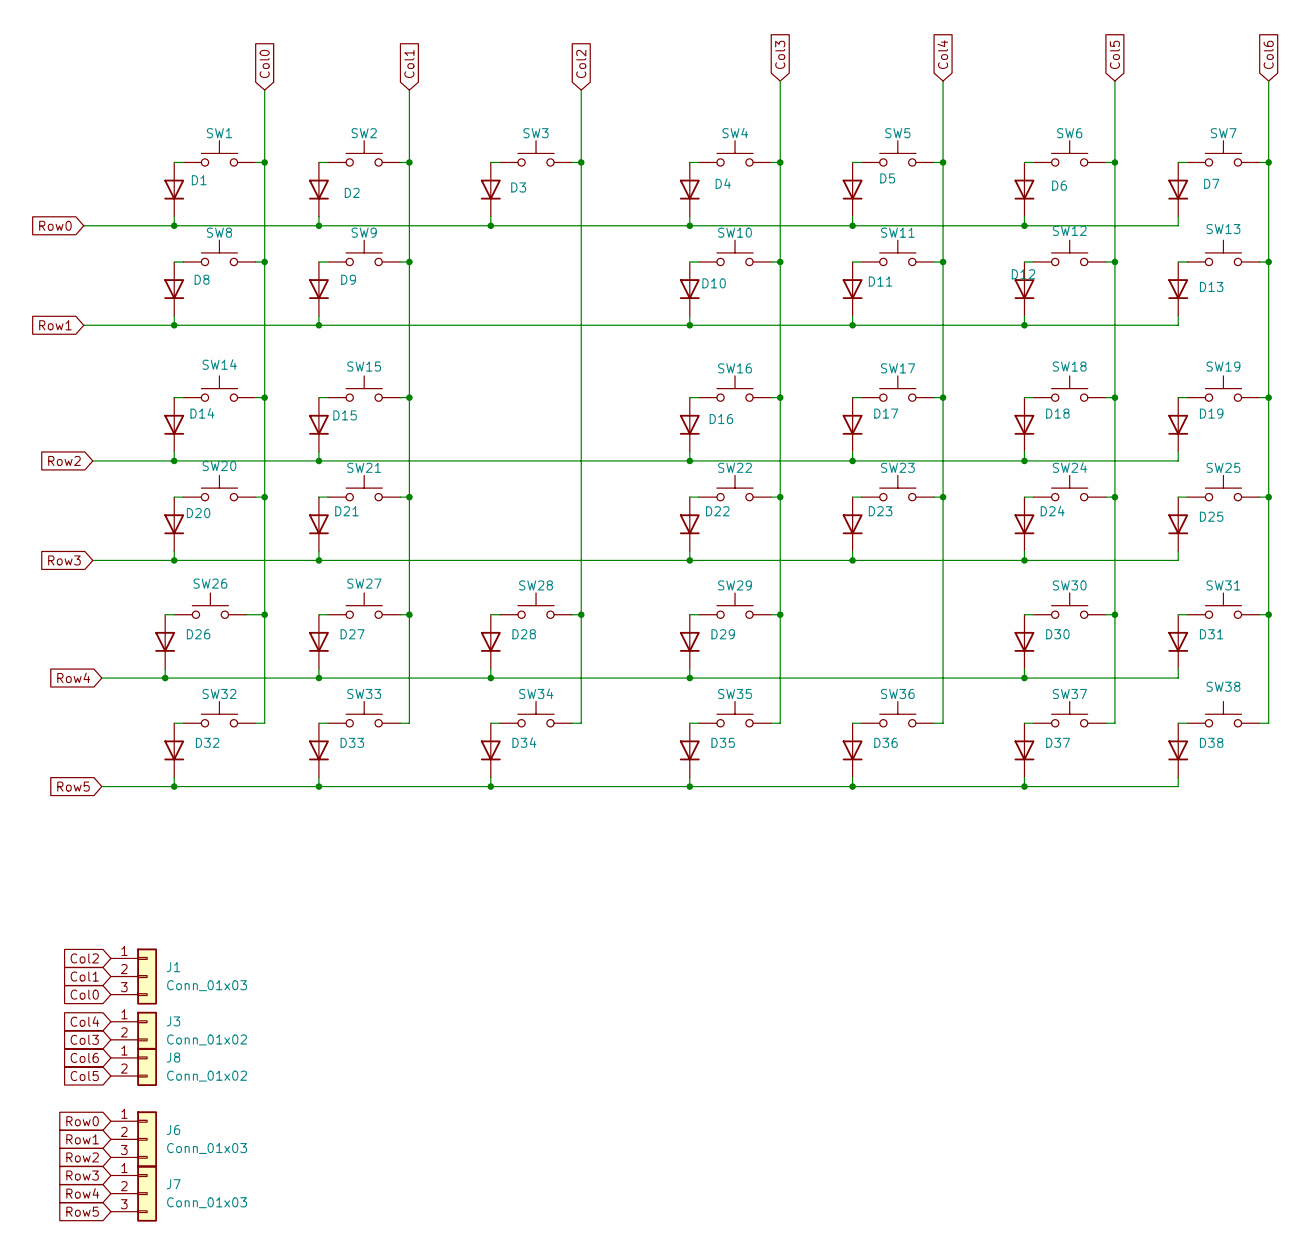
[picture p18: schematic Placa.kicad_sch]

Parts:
D1, D2, D3, D4, D5, D6, D7, D8, D9, D10, D11, D12, D13, D14, D15, D16, D17, D18, D19, D20, D21, D22, D23, D24, D25, D26, D27, D28, D29, D30, D31, D32, D33, D34, D35, D36, D37, D38: 1N4148; D_DO-35_SOD27_P7.62mm_Horizontal
J1, J6, J7: Conn_01x03; JST_XH_B3B-XH-A_1x03_P2.50mm_Vertical
J3, J8: Conn_01x02; JST_XH_B2B-XH-A_1x02_P2.50mm_Vertical
SW1, SW2, SW3, SW4, SW5, SW6, SW7, SW8, SW9, SW10, SW11, SW12, SW13, SW14, SW15, SW16, SW17, SW18, SW19, SW20, SW21, SW22, SW23, SW24, SW25, SW26, SW27, SW28, SW29, SW30, SW31, SW32, SW33, SW34, SW35, SW36, SW37, SW38: SW_Push; Kailh_socket_MX_platemount

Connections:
Col0: J1.3, SW1.2, SW8.2, SW14.2, SW20.2, SW26.2, SW32.2
Col1: J1.2, SW2.2, SW9.2, SW15.2, SW21.2, SW27.2, SW33.2
Col2: J1.1, SW3.2, SW28.2, SW34.2
Col3: J3.2, SW4.2, SW10.2, SW16.2, SW22.2, SW29.2, SW35.2
Col4: J3.1, SW5.2, SW11.2, SW17.2, SW23.2, SW36.2
Col5: J8.2, SW6.2, SW12.2, SW18.2, SW24.2, SW30.2, SW37.2
Col6: J8.1, SW7.2, SW13.2, SW19.2, SW25.2, SW31.2, SW38.2
unnamed: D1.2 (A), SW1.1
unnamed: D2.2 (A), SW2.1
unnamed: D3.2 (A), SW3.1
unnamed: D4.2 (A), SW4.1
unnamed: D5.2 (A), SW5.1
unnamed: D6.2 (A), SW6.1
unnamed: D7.2 (A), SW7.1
unnamed: D8.2 (A), SW8.1
unnamed: D9.2 (A), SW9.1
unnamed: D10.2 (A), SW10.1
unnamed: D11.2 (A), SW11.1
unnamed: D12.2 (A), SW12.1
unnamed: D13.2 (A), SW13.1
unnamed: D14.2 (A), SW14.1
unnamed: D15.2 (A), SW15.1
unnamed: D16.2 (A), SW16.1
unnamed: D17.2 (A), SW17.1
unnamed: D18.2 (A), SW18.1
unnamed: D19.2 (A), SW19.1
unnamed: D20.2 (A), SW20.1
unnamed: D21.2 (A), SW21.1
unnamed: D22.2 (A), SW22.1
unnamed: D23.2 (A), SW23.1
unnamed: D24.2 (A), SW24.1
unnamed: D25.2 (A), SW25.1
unnamed: D26.2 (A), SW26.1
unnamed: D27.2 (A), SW27.1
unnamed: D28.2 (A), SW28.1
unnamed: D29.2 (A), SW29.1
unnamed: D30.2 (A), SW30.1
unnamed: D31.2 (A), SW31.1
unnamed: D32.2 (A), SW32.1
unnamed: D33.2 (A), SW33.1
unnamed: D34.2 (A), SW34.1
unnamed: D35.2 (A), SW35.1
unnamed: D36.2 (A), SW36.1
unnamed: D37.2 (A), SW37.1
unnamed: D38.2 (A), SW38.1
Row0: D1.1 (K), D2.1 (K), D3.1 (K), D4.1 (K), D5.1 (K), D6.1 (K), D7.1 (K), J6.1
Row1: D8.1 (K), D9.1 (K), D10.1 (K), D11.1 (K), D12.1 (K), D13.1 (K), J6.2
Row2: D14.1 (K), D15.1 (K), D16.1 (K), D17.1 (K), D18.1 (K), D19.1 (K), J6.3
Row3: D20.1 (K), D21.1 (K), D22.1 (K), D23.1 (K), D24.1 (K), D25.1 (K), J7.1
Row4: D26.1 (K), D27.1 (K), D28.1 (K), D29.1 (K), D30.1 (K), D31.1 (K), J7.2
Row5: D32.1 (K), D33.1 (K), D34.1 (K), D35.1 (K), D36.1 (K), D37.1 (K), D38.1 (K), J7.3

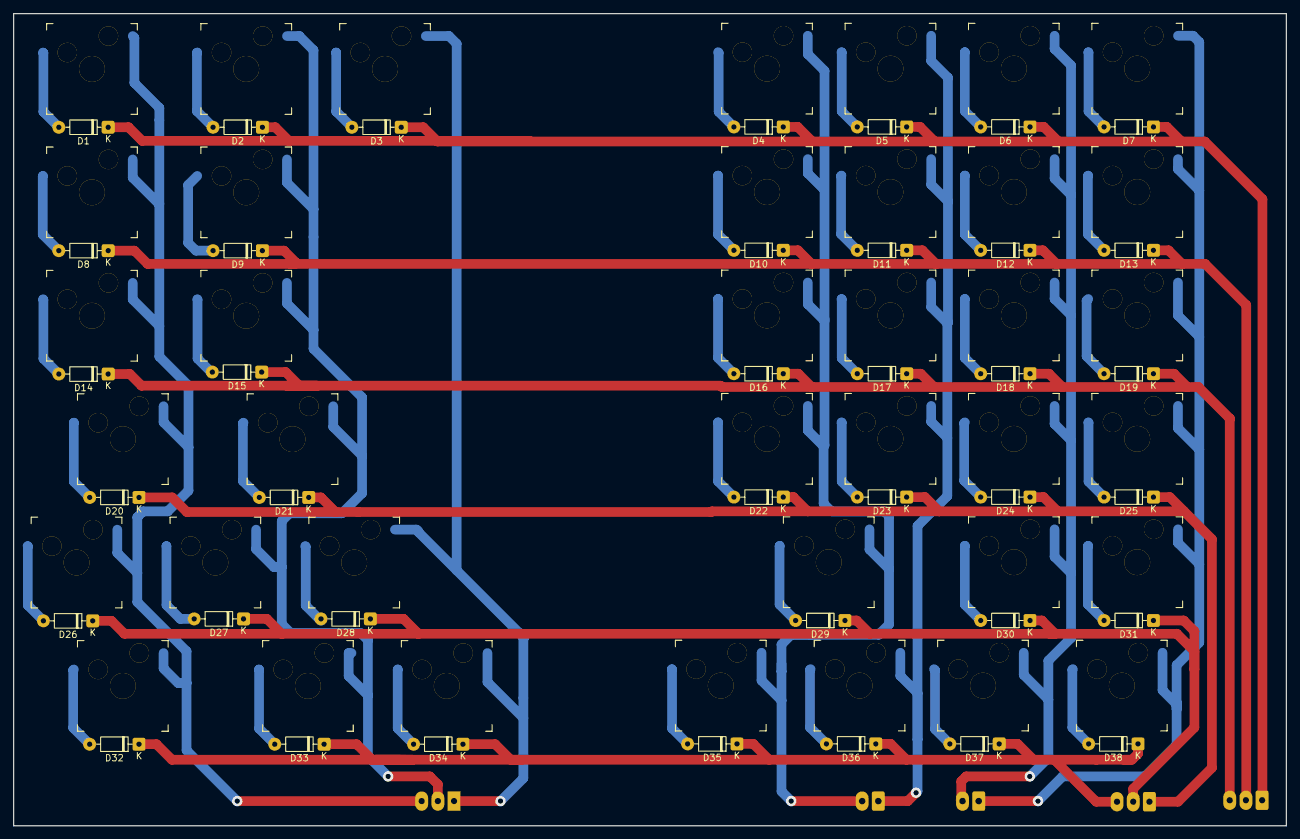
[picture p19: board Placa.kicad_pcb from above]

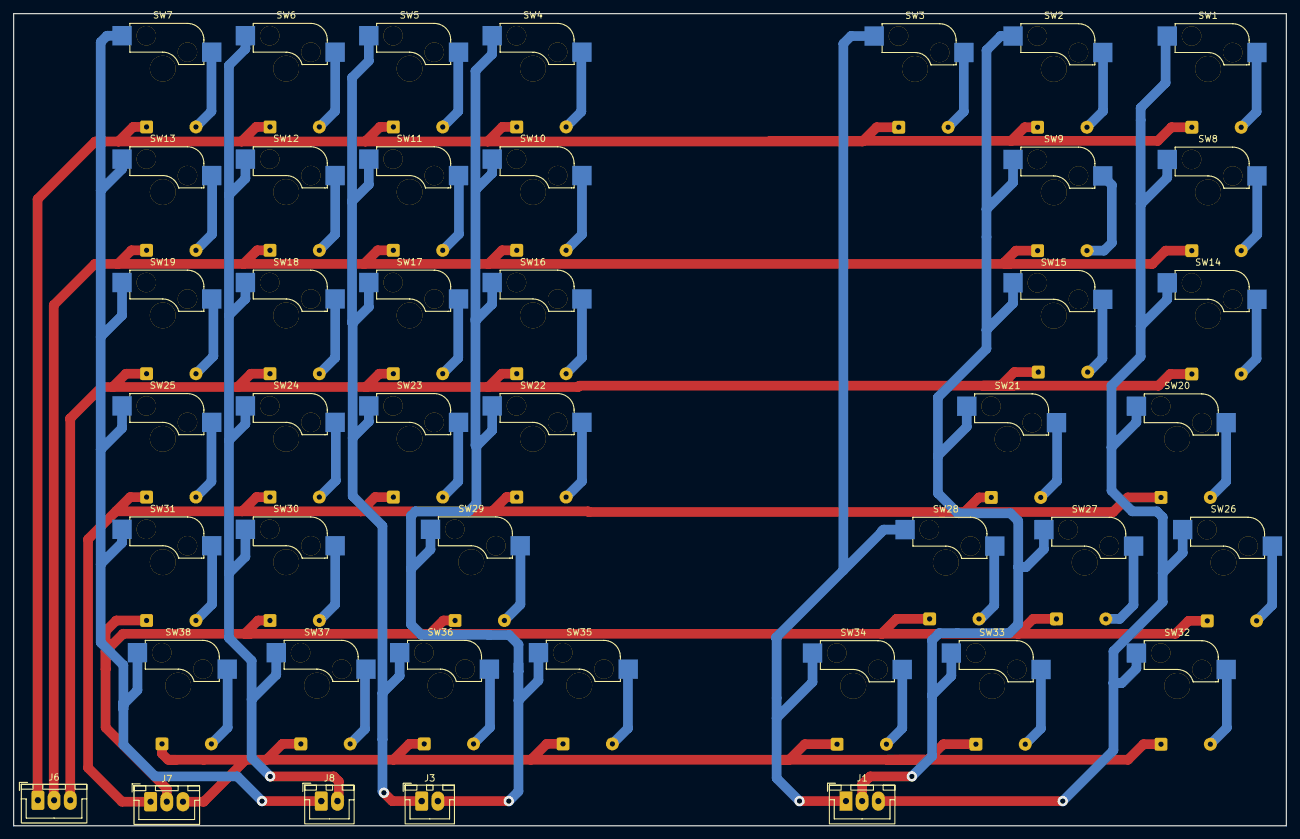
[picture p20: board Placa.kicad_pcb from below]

Board: 2 copper layers, 196.5 x 125.4 mm, 81 parts (5 on the bottom side), 51 nets.

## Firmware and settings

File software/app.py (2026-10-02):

"""Entry point: picks the front-end that matches the active video output.

PRD §7 decides *where* the calculator is visible, so that choice belongs here
rather than in any UI package: the external monitor wins when recognised
(RF-02/RF-03), the LCD is used when it is the only panel available, and with no
usable video the calculator falls back to audio-only operation (RF-04).
Exactly one front is started per run.
"""

from __future__ import annotations

import argparse
import logging
import os
import signal
import sys
from pathlib import Path

if __package__ in {None, ""}:
    sys.path.insert(0, str(Path(__file__).resolve().parents[1]))

from software.accessibility.speech import SpeechService
from software.core import CalculatorState
from software.hw_platform import video_output
from software.hw_platform.display import (
    DEFAULT_LCD_CONNECTOR,
    DEFAULT_MONITOR_CONNECTOR,
    LCD_CONNECTOR_ENV,
    MONITOR_CONNECTOR_ENV,
    DisplayMode,
    DisplaySelector,
    SimulatedHdmiPortReader,
    SysfsHdmiPortReader,
)
from software.hw_platform.keypad_matrix import MatrixKeyboard
from software.ui.shared.video_blackout import VideoApplier, VideoBlackout

logger = logging.getLogger(__name__)

# CLI names for --force-mode, kept short for demos and debugging sessions.
_FORCED_MODES = {
    "lcd": DisplayMode.LCD,
    "hdmi": DisplayMode.HDMI,
    "audio": DisplayMode.AUDIO_ONLY,
}

# --keypad-matrix: "auto" liga a matriz quando o gpiochip0 do Pi 4 existe e
# segue só com o teclado de PC quando não (PC, CI); "off" nunca toca em GPIO.
KEYPAD_MATRIX_CHOICES = ("auto", "off")

LOG_FILE_ENV = "CALC_LOG_FILE"
_LOG_FORMAT = "%(asctime)s %(levelname)s %(name)s: %(message)s"


def default_log_path() -> Path:
    """`$HOME/calculadora.log` - the kiosk user's home, created by the build.

    Not /var/log: the rootfs is writable but `kiosk` is an ordinary user with
    no guaranteed write permission there, and a boot must not depend on it.
    """
    return Path(os.path.expanduser("~")) / "calculadora.log"


def configure_logging() -> None:
    """Send the log somewhere readable on the image (D4).

    On the kiosk, tty1 is covered by X, so a warning on stderr is invisible and
    a failed xrandr is indistinguishable from a working one. Only the entry
    point configures handlers; modules just call getLogger(__name__).
    """
    path = os.environ.get(LOG_FILE_ENV) or str(default_log_path())

    handler: logging.Handler
    try:
        handler = logging.FileHandler(path, encoding="utf-8")
    except OSError as exc:  # unwritable path must not stop the calculator
        handler = logging.StreamHandler()
        logging.basicConfig(level=logging.INFO, handlers=[handler], format=_LOG_FORMAT, force=True)
        logger.warning("nao foi possivel abrir %s (%s); registrando em stderr", path, exc)
        return

    logging.basicConfig(level=logging.INFO, handlers=[handler], format=_LOG_FORMAT, force=True)


def resolve_mode(force_mode: str | None = None, selector: DisplaySelector | None = None) -> DisplayMode:
    """Active output, honouring --force-mode when given."""
    if force_mode is not None:
        return _FORCED_MODES[force_mode]
    return (selector or DisplaySelector()).current_mode()


def resolve_output_names() -> tuple[str, str]:
    """The xrandr names for the LCD and the monitor, in that order.

    The X outputs are read once and reused for both roles, so resolving the
    pair costs a single `xrandr --query` instead of one per panel.
    """
    outputs = video_output.read_outputs()
    lcd = video_output.output_name(
        os.environ.get(LCD_CONNECTOR_ENV, DEFAULT_LCD_CONNECTOR),
        video_output.LCD_OUTPUT_ENV,
        outputs,
    )
    monitor = video_output.output_name(
        os.environ.get(MONITOR_CONNECTOR_ENV, DEFAULT_MONITOR_CONNECTOR),
        video_output.MONITOR_OUTPUT_ENV,
        outputs,
    )
    return lcd, monitor


def point_x_at(mode: DisplayMode, blackout: VideoBlackout | None = None) -> bool:
    """Enable the panel `mode` belongs to and switch the other one off.

    X keeps driving whatever it configured at startup, so a monitor plugged in
    later stays dark until xrandr enables it, and with both ports connected it
    autoconfigures an extended desktop that PRD §7.2 forbids. Best effort: off
    the Pi there is no X server and this is a no-op.

    The single point that applies video (video-blackout D2): while the user has
    the screens off, every output goes off instead - including for a front
    rebuilt by RF-09, which is how the choice survives a hotplug. Returns
    whether the X server was confirmed in the requested state.
    """
    if mode == DisplayMode.AUDIO_ONLY:
        return False

    lcd, monitor = resolve_output_names()
    if blackout is not None and blackout.active:
        return video_output.all_off((lcd, monitor), mode=mode.value)

    # Each panel carries its own orientation: the LCD is mounted upside down in
    # the enclosure and is lit rotated 180 graus, the external monitor upright.
    if mode == DisplayMode.HDMI:
        target = monitor
        rotate = video_output.rotation(
            video_output.MONITOR_ROTATION_ENV, video_output.DEFAULT_MONITOR_ROTATION
        )
    else:
        target = lcd
        rotate = video_output.rotation(
            video_output.LCD_ROTATION_ENV, video_output.DEFAULT_LCD_ROTATION
        )

    return video_output.activate(
        target, disable=(lcd, monitor), mode=mode.value, rotate=rotate
    )


def make_video_applier(
    front_mode: DisplayMode,
    blackout: VideoBlackout,
    selector: DisplaySelector | None = None,
) -> VideoApplier:
    """What a front calls after flipping `blackout.active` (video-blackout D2).

    Relighting re-runs the PRD §7.2 priority through `selector` instead of
    remembering which panel was lit, so a monitor plugged in or removed during
    the blackout is honoured. Without a selector (--force-mode) the front's own
    panel is relit, keeping the forced choice.
    """

    def apply() -> DisplayMode | None:
        mode = front_mode
        if not blackout.active and selector is not None:
            detected = selector.current_mode()
            if detected != DisplayMode.AUDIO_ONLY:
                mode = detected
        return mode if point_x_at(mode, blackout) else None

    return apply


def start_front(
    mode: DisplayMode,
    state: CalculatorState,
    speech: SpeechService,
    blackout: VideoBlackout | None = None,
    selector: DisplaySelector | None = None,
    keypad_matrix: MatrixKeyboard | None = None,
) -> DisplayMode | None:
    """Run the single front matching `mode`; returns the mode taking over.

    UI modules are imported lazily so audio-only operation never needs a Tk
    runtime, and so a headless machine can still run the audio path.
    """
    blackout = blackout or VideoBlackout()

    if mode == DisplayMode.HDMI:
        from software.ui.hdmi.app import CalculatorApp

        return CalculatorApp(
            state, speech, blackout=blackout,
            apply_video=make_video_applier(mode, blackout, selector),
            keypad_matrix=keypad_matrix,
        ).run()

    if mode == DisplayMode.LCD:
        from software.ui.lcd.app import CalculatorApp

        return CalculatorApp(
            state, speech, blackout=blackout,
            apply_video=make_video_applier(mode, blackout, selector),
            keypad_matrix=keypad_matrix,
        ).run()

    # Audio-only has no screen to switch off: the blackout does not reach it.
    # Nor does the matrix: this loop reads whole lines from stdin, and the key
    # handling (Ctrl/Shift, history) lives in the Tk fronts. Known limitation
    # of keypad-matrix; the scanner stays open, unattached, for the video to
    # come back.
    from software.audio_only import AudioOnlyCalculator

    AudioOnlyCalculator(state, speech).run()
    return None


def run_mode(
    mode: DisplayMode,
    state: CalculatorState | None = None,
    speech: SpeechService | None = None,
    selector: DisplaySelector | None = None,
    keypad_matrix: str = "off",
) -> int:
    """Run fronts until the user quits, swapping when the video output changes.

    RF-09: the monitor is always plugged in with the calculator already on, so
    the swap has to be cheap. The whole point of the loop is that `state` is
    built once and handed to whichever front comes next — the expression being
    typed, the history and the angle mode survive; nothing restarts.

    The blackout travels the same way (video-blackout D1): one per run, never
    persisted, so a front taking over during it is born dark and a restart
    always comes up lit.

    So does the keypad matrix (keypad-matrix D8): its GPIO lines are requested
    once here and released here, whatever ends the run. `keypad_matrix` is the
    --keypad-matrix choice; it defaults to "off" so that calling this function
    directly (tests) never touches the hardware.
    """
    state = state or CalculatorState()
    speech = speech or SpeechService()
    blackout = VideoBlackout()

    matrix = open_keypad_matrix(keypad_matrix)
    try:
        next_mode: DisplayMode | None = mode
        while next_mode is not None:
            point_x_at(next_mode, blackout)
            next_mode = start_front(next_mode, state, speech, blackout, selector, matrix)
    finally:
        # Todas as 13 GPIOs de volta a entrada sem bias, também em exceção,
        # Ctrl+C ou SIGTERM/SIGHUP (install_exit_signals).
        if matrix is not None:
            matrix.close()

    return 0


def open_keypad_matrix(choice: str) -> MatrixKeyboard | None:
    """The running matrix scanner, or None (choice "off", or no hardware)."""
    if choice == "off":
        logger.info("matriz do teclado desligada (--keypad-matrix off)")
        return None
    return MatrixKeyboard.open()


def install_exit_signals() -> None:
    """SIGTERM/SIGHUP end the run through the normal `finally` blocks.

    The graphical session stops the app with a signal, and Python's default
    for SIGTERM is to die without unwinding — which would leave the keypad
    matrix lines configured. SystemExit crosses Tk's mainloop (tkinter
    re-raises it from callbacks), and the matrix pump's 10 ms tick gives the
    handler a chance to run promptly.
    """
    def _exit(signum, _frame) -> None:
        raise SystemExit(128 + signum)

    for name in ("SIGTERM", "SIGHUP"):  # SIGHUP não existe no Windows
        sig = getattr(signal, name, None)
        if sig is not None:
            signal.signal(sig, _exit)


def build_parser() -> argparse.ArgumentParser:
    parser = argparse.ArgumentParser(
        prog="calculadora",
        description="Calculadora cientifica acessivel (TCC).",
    )
    parser.add_argument(
        "--force-mode",
        choices=sorted(_FORCED_MODES),
        help=(
            "Forca a saida em vez de detectar (desenvolvimento/demonstracao): "
            "lcd = painel 4.3\", hdmi = monitor externo, audio = somente voz."
        ),
    )
    parser.add_argument(
        "--simulate-monitor",
        action="store_true",
        help="Simula um monitor externo reconhecido (sem hardware real).",
    )
    parser.add_argument(
        "--list-outputs",
        action="store_true",
        help=(
            "Lista os conectores de video vistos pelo sistema e encerra "
            "(usado no bring-up para confirmar quais nomes correspondem a "
            "HDMI0/HDMI1)."
        ),
    )
    parser.add_argument(
        "--keypad-matrix",
        choices=KEYPAD_MATRIX_CHOICES,
        default="auto",
        help=(
            "Teclado fisico (matriz 6x7 por GPIO): auto = usa quando o "
            "gpiochip0 do Raspberry Pi 4 estiver disponivel, off = nunca "
            "toca em GPIO. Padrao: auto."
        ),
    )
    parser.add_argument(
        "--apply-video-layout",
        action="store_true",
        help=(
            "Aplica o layout exclusivo de video (uma unica saida ativa) e "
            "encerra, sem abrir nenhuma interface. Chamado pela sessao grafica "
            "antes de subir o app, para que o desktop estendido que o X "
            "autoconfigura nunca chegue a ficar visivel (PRD §7.2)."
        ),
    )
    return parser


def print_outputs() -> None:
    """Diagnostic for the image bring-up (PRD §6/§11).

    The cabling is fixed - HDMI0 is the LCD, HDMI1 the monitor - but neither
    the DRM connector names nor the xrandr output names are guaranteed, and a
    mismatch between the two is what left both panels lit. Print both sides and
    the mapping actually in use, so one command answers the whole checklist.
    """
    reader = SysfsHdmiPortReader()
    connectors = reader.list_connectors()

    print("Conectores DRM (kernel):")
    if not connectors:
        print(f"  nenhum encontrado em {reader.drm_path} (maquina sem DRM?)")
    else:
        for name, status in connectors.items():
            print(f"  {name}: {status}")

    print()
    print("Saidas do servidor X (xrandr):")
    if video_output.missing_xrandr_on_x():
        # A saída exclusiva do §7.2 é aplicada por xrandr; sem o binário, tudo
        # aqui vira no-op e as duas telas ficam acesas.
        print("  ERRO: o X esta a correr mas o 'xrandr' NAO esta instalado.")
        print("  Sem ele nenhuma reconfiguracao de saida acontece (PRD §7.2).")
        print("  Corrija com: apk add xrandr   (e ver system/rpi-os/alpine/packages)")
    else:
        outputs = video_output.read_outputs()
        if not outputs:
            print("  nenhuma (sem DISPLAY, sem xrandr, ou estado ilegivel)")
        else:
            # A rotacao entra aqui porque o sintoma dela - imagem de pernas para
            # o ar - nao aparece em nenhuma outra linha deste diagnostico.
            rotations = video_output.read_rotations()
            for name, active in outputs.items():
                estado = "ativa" if active else "inativa"
                print(f"  {name}: {estado} (rotacao: {rotations.get(name, '?')})")

    lcd_output, monitor_output = resolve_output_names()
    lcd_rotation = video_output.rotation(
        video_output.LCD_ROTATION_ENV, video_output.DEFAULT_LCD_ROTATION
    )
    monitor_rotation = video_output.rotation(
        video_output.MONITOR_ROTATION_ENV, video_output.DEFAULT_MONITOR_ROTATION
    )
    print()
    print("Mapeamento em uso (conector DRM -> saida X):")
    print(f"  LCD (HDMI0)     -> {reader.lcd_connector} -> {lcd_output} [rotacao: {lcd_rotation}]")
    print(
        f"  Monitor (HDMI1) -> {reader.monitor_connector} -> {monitor_output}"
        f" [rotacao: {monitor_rotation}]"
    )
    print(f"Deteccao real disponivel: {'sim' if reader.available() else 'nao (usando simulacao)'}")


def main(argv: list[str] | None = None) -> int:
    args = build_parser().parse_args(argv)
    configure_logging()

    # Diagnostics first: --list-outputs only reports, so it stays useful even
    # when combined with the flags that would otherwise change the screen.
    if args.list_outputs:
        print_outputs()
        return 0

    selector = None
    if args.simulate_monitor:
        selector = DisplaySelector(SimulatedHdmiPortReader(monitor_present=True))

    mode = resolve_mode(args.force_mode, selector)

    if args.apply_video_layout:
        # No front, no Tk import: the graphical session runs this before the
        # app so the autoconfigured extended desktop is never drawn on.
        point_x_at(mode)
        return 0

    # Relighting after a blackout re-runs detection, unless the mode was forced.
    relight_selector = None if args.force_mode else (selector or DisplaySelector())
    install_exit_signals()
    return run_mode(mode, selector=relight_selector, keypad_matrix=args.keypad_matrix)


if __name__ == "__main__":
    raise SystemExit(main())

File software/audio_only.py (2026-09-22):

"""Audio-only operation for when no usable video output exists (RF-04).

PRD §7.3: audio feedback runs in parallel with whatever video is available, and
when there is none the calculator must still be operable "apoiada no audio".
This loop reads the physical keyboard and announces every entry and result via
TTS, using the same core state machine and the same PRD §13 error catalogue as
the visual fronts - no Tk window is created.
"""

from __future__ import annotations

import logging

from software.accessibility.speech import SpeechService
from software.core import CalculatorState
from software.hw_platform.keyboard import KeyboardAdapter
from software.ui.shared.error_messages import friendly_message, spoken_priority_prefix
from software.ui.shared.keypad import spoken_token

logger = logging.getLogger(__name__)

_QUIT_COMMANDS = {"sair", "quit", "exit"}
_HELP_TEXT = (
    "Modo somente audio. Digite uma expressao e pressione Enter para calcular. "
    "Escreva 'sair' para encerrar."
)


class AudioOnlyCalculator:
    """Keyboard-in / speech-out calculator with no visual surface."""

    def __init__(
        self,
        state: CalculatorState | None = None,
        speech: SpeechService | None = None,
        keyboard: KeyboardAdapter | None = None,
    ) -> None:
        self.state = state or CalculatorState()
        self.speech = speech or SpeechService()
        self.keyboard = keyboard or KeyboardAdapter()

    def run(self) -> None:
        self.speech.say("Calculadora pronta. Sem video disponivel, modo somente audio.")
        print(_HELP_TEXT)
        try:
            while True:
                try:
                    line = input("> ").strip()
                except EOFError:
                    break
                if not line:
                    continue
                if line.lower() in _QUIT_COMMANDS:
                    break
                self.submit(line)
        except KeyboardInterrupt:
            pass
        finally:
            self.speech.say("Encerrando")
            self.speech.stop()

    def submit(self, line: str) -> None:
        """Feed one typed expression through the shared state machine."""
        self.state.press("AC")
        for char in line:
            token = self.keyboard.map_key(char) or char
            self.state.press(token)

        result = self.state.press("=")
        if result is None:
            return
        self.announce(result)

    def announce(self, result) -> None:
        if result.ok:
            message = f"Resultado {result.display}"
            print(message)
            self.speech.interrupt_and_say(message)
            return

        # Same code and priority prefix the visual fronts use (PRD §13).
        friendly_msg = friendly_message(result.code, result.message)
        prefix = spoken_priority_prefix(result.code)
        print(f"{result.code}: {friendly_msg}")
        self.speech.interrupt_and_say(
            f"{prefix} {result.code.split('-')[-1]}. {friendly_msg}"
        )

    def announce_token(self, token: str) -> None:
        """Announce a single key press (used when driven key-by-key)."""
        self.speech.say(spoken_token(token))


def main() -> None:
    AudioOnlyCalculator().run()


if __name__ == "__main__":
    main()

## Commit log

2026-04-18 Initial import: PRD, docs, cronograma, hardware skeleton, and team workflow
    Made-with: Cursor
    [2.54 mm DUPONT MALE PIN HEADER, IO, 2X20, RPi4ModelB.SLDPRT, 2.54 mm DUPONT MALE PIN HEADER, IO, 2X40, RPi4ModelB.SLDPRT, 2.54 mm DUPONT MALE PIN HEADER, POE, 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]
2026-04-18 docs: create materials and methods document and update sprint context
2026-04-28 update pcb artifacts and refresh project scaffolding/docs
    Includes latest KiCad board/project changes, generated PCB PDF exports, and repository housekeeping updates across docs and software/hardware placeholder structure.
    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
    [tcc-16-04-2026-1322.kicad_pcb]
2026-05-09 hardware(pcb): refresh KiCad project and move snapshot to TCC-09-05-2026
    [Placa1.0.step, TccTeste.kicad_pcb, TccTeste.kicad_sch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]
2026-05-09 feat(ui): add ttkbootstrap calculator prototype and Python core
2026-05-10 hotfix: fix calculation errors and calculator functionality issues
    [app.py]
2026-05-12 fix(pcb): correct component footprints and drill sizes
    [Placa.kicad_pcb, Placa.kicad_sch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]
2026-05-14 chore: minor tweaks and bug fixes
    [app.py, display.py, keyboard.py]
2026-05-17 feat: ajusta motor de cálculo e adiciona log baseado em variável
2026-05-17 fix: improve calculation engine precision and scientific operations
    [test_arithmetic.py]
2026-06-10 fix: Ajuste no codigo responsavel por apagar funções
    [app.py]
2026-06-10 fix/feat: corrige exclusão de funções e implementa leitura acessível das funções
    [app.py]
2026-07-04 Atualizções na PCB
    [Placa.kicad_pcb, Placa.kicad_sch, Placa1.0.step]
2026-08-10 Ajustes na pcb
    [Placa.kicad_pcb, Placa.kicad_sch]
2026-08-11 refactor(pcb): reorganiza posicionamento dos componentes
    [Placa.kicad_pcb]
2026-08-14 feat(ui_hdmi): adiciona front do monitor HDMI e seleção de saída
    Implementa a mudança OpenSpec add-hdmi-ui (PRD §7, RF-02/RF-03/RF-04).
    - ui_hdmi/: novo front-end responsivo para o monitor externo. Não fixa
    geometria: abre na resolução reportada pelo SO e recalcula fontes e
    células a cada redimensionamento. Usa a área extra para um painel de
    histórico sempre visível.
    - hw_platform/display.py: DisplaySelector deixa de ser stub e aplica a
    prioridade do §7.4 (monitor > LCD > somente áudio) atrás de um
    HdmiPortReader injetável, permitindo a detecção real depois sem mexer
    na lógica. Interruptor físico do LCD conta como sem vídeo utilizável.
    - app.py: passa a esc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
    [app.py, audio_only.py, display.py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]
2026-08-14 [200~refactor(ui): janela fixa, LCD só display e histórico por teclado
    [app.py, keyboard.py, test_audio_only.py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]
2026-08-24 fix(rpi-img): refresh app and overlay on REUSE_ROOTFS rebuilds
    REUSE_ROOTFS=1 skipped the app copy, so quick rebuilds silently produced
    images carrying an outdated software/. Reuse now keeps only the installed
    packages (the slow apk/pip phase) and always re-applies the overlay and
    the app from the repo.
    Extract mount_chroot() so both paths share it: it reinstalls
    qemu-aarch64-static (build_image removes it at the end) and is idempotent
    about the mounts.
    Document the rebuild flow and which front the kiosk starts, since app.py
    now picks LCD/HDMI/audio via hw_platform/display.py.
2026-08-24 fix(rpi-img): make the image boot on the Pi and stop breaking the host
    Two defects found while flashing the first image to a Raspberry Pi 4B:
    - parted derives the MBR type id from the filesystem it finds, and the
    boot partition is still empty at that point, so p1 ended up as 0x83
    (Linux) instead of 0x0c (W95 FAT32 LBA). The Pi 4 bootloader looks the
    boot partition up by FAT type and rejected the card with "Unable to
    read partition as FAT", even though the FAT32 filesystem itself was
    valid. Force the type with sfdisk and mark p1 bootable.
    - /dev and /sys on the host are shared mounts, so a plain rbind put the
    chroot copies in the same peer group: the cleanup umount propagated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
2026-08-27 docs: adicionado lista de comandos
2026-08-27 fix: teclado inicia visivel na ui_hdmi
    [app.py]
2026-08-28 feat: adicionado fluxo de telas
2026-08-28 feat: ajustado imagem e fluxo de tela por pinagem
2026-08-28 fix: teste de keyboard
    [test_keypad_toggle.py]
2026-09-03 docs(openspec): archive add-hdmi-ui and sync specs
    All 20 tasks and 4 planning artifacts were already complete; move the
    change to archive/2026-09-03-add-hdmi-ui and materialize its 2
    capabilities (display-switching, hdmi-ui) under openspec/specs/.
2026-09-04 fix: adicionado xrandr no build da img
    [app.py, test_image_packages.py, test_video_output.py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]
2026-09-04 fix: ajsutes de ui ao trocar de tela
    [app.py, test_handover_styling.py]
2026-09-06 feat: chenge aplicada e testes ajusdaos para reconhecer o ambiente
2026-09-11 feat: gerar a imagem Alpine do Pi pelo Windows via VM no VirtualBox
    O `make rpi-img` so rodava num Linux com sudo; no Windows falhava com
    "sudo: command not found". O build precisa de kernel Linux (loop, mount,
    chroot, binfmt), entao o novo build-alpine-img.ps1 cria e controla uma VM
    Debian 12 no VirtualBox (sem WSL/Hyper-V, sem reiniciar), roda o mesmo
    build-alpine-img.sh la dentro e traz o .img de volta.
    A copia na VM e convertida de CRLF para LF: com core.autocrlf=true o
    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
2026-09-18 fix: ajustes na imagem
    [keypad_bringup.py, keypad_pinout.py]
2026-09-19 docs(openspec): add add-keypad-matrix-scanner change
    Propose reading the 6x7 keypad matrix over GPIO with the wiring and
    polarity validated on the Pi 4 (active column driven HIGH, rows as
    pull-down inputs, idle columns floating), covering RF-05 and RF-11.
    - Fix row GPIO order (Row0<->Row2 and Row3<->Row5 were swapped) and
    switch to 0-based labels matching the KiCad nets
    - Add the SW0..SW37 switch map, cross-checked against the PCB netlist
    - libgpiod v2 scanner in its own thread, feeding the existing
    _handle_token() through a Tk-side queue pump
    - Safe GPIO release on exit, SIGTERM and SIGHUP; bring-up tool rebuilt
    on top of the scanner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
2026-09-23 fix: orientação da tela em 180° somente no LCD
    [app.py, test_video_layout_cli.py, test_video_output.py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]
2026-09-28 fix: ajustes na lib de audio
    [test_speech_service.py]
2026-09-28 docs: adicionado change de alteração de lib
2026-09-29 chore: atualização do git ignore para não enviar a configuração do claude local
2026-09-30 fix(rpi-img): unblock the Piper wheel build and wire it up by default
    Four defects found while building the image end to end on hardware-bound
    hardware:
    - The wheel build died compiling espeak-ng with "fatal error:
    linux/limits.h: No such file or directory". Alpine needs linux-headers
    for that; on glibc distros it rides along with the libc dev package.
    ninja only reported a generic "subcommand failed", hiding the cause.
    Added to both build paths (the standalone script and the in-chroot one).
    - pip inside the qemu chroot kept failing with "Connection reset by peer"
    while fetching Pillow, a compiled multi-MB dependency of ttkbootstrap.
    Pillow now comes from apk (py3-pillow 12.2.0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
2026-09-30 fix(rpi-img): keep the wheel's real filename and pin the cadu voice hashes
    Two things stood between the build and a finished image:
    - install_piper_prebuilt copied the wheel to a fixed "piper_wheel.whl".
    pip reads name, version and tags from the filename itself, so it
    rejected it with "Invalid wheel filename (wrong number of parts)". The
    original basename is preserved now (derived from the URL, minus query
    and fragment, on the download path), and a malformed name is refused up
    front with the name in the message rather than deep inside pip.
    - The cadu voice hashes were still the placeholders the script asked to
    fill in, and STRICT=1 (which the image build uses, so no unverified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
2026-09-30 fix: ajustes no .sh para reconhecer o caminho da voz pré-compilada
2026-11-03 fix: corrige parênteses, nCr e números complexos; adiciona tecla de ajuda
    - Parênteses não fechados agora calculam: sqrt(144 = 12
    - nCr/nPr viram infixos: 5 nCr 2 = 10 (nCr(5,2) deixa de funcionar)
    - polar() e rect() devolvem os dois valores, com leitura padronizada
    - Tecla ? passa a anunciar o modo angular e os atalhos
    - ERR-009 passa a ser emitido; ERR-008 cobre argumentos em falta
    550 testes passando.
2026-11-05 feat: mudança de teclas
2026-11-05 fix: corrige Pol/Rec, tecla EXP, exibição do par e tecla de consulta
    Correções dos defeitos encontrados no teste em hardware.
    - Pol/Rec estavam invertidos em relação à convenção das calculadoras
    científicas: Pol(3,4) devolvia (2.99, 0.21) em vez de (5, 53.13). Era
    isso que fazia o Y parecer "principalmente errado" - o X saía perto
    de 3 e parecia quase certo. Agora Pol(x,y) dá (r,ângulo) e
    Rec(r,ângulo) dá (x,y). Corrige também a etiqueta "Rec(" que o
    formatting.py já mostrava para a função que fazia o oposto.
    - Os ".." na tela e o X que não aparecia eram a MESMA causa, e não era
    matemática: o par ia numa linha só, "(5, 53.13010235)" com 16
    caracteres, a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
